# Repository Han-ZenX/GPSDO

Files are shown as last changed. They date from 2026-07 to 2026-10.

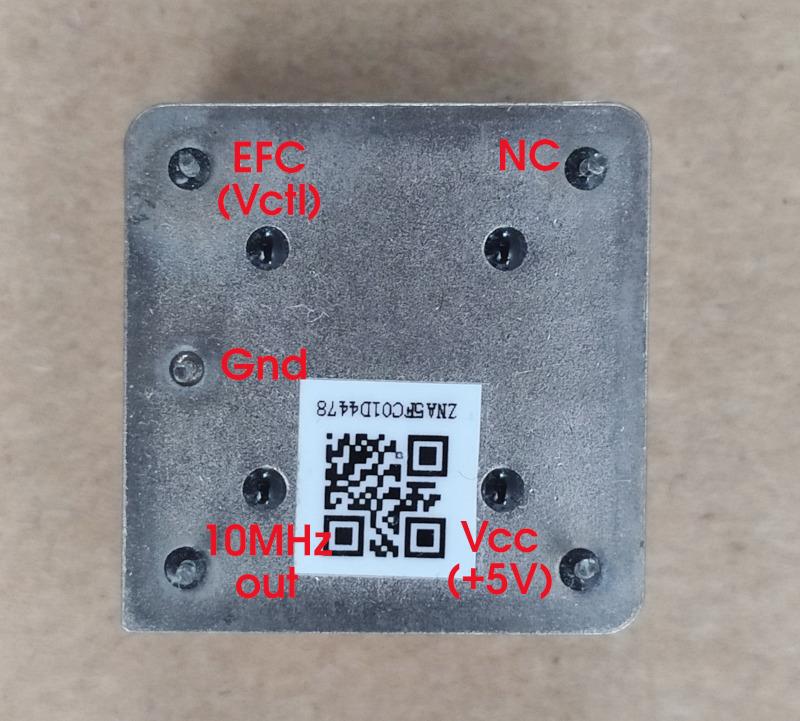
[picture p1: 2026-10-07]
docs/hardware/10Mhz OCXO ETC-CTI OSC5A2B02/CTI_OCXO_bottom.jpg

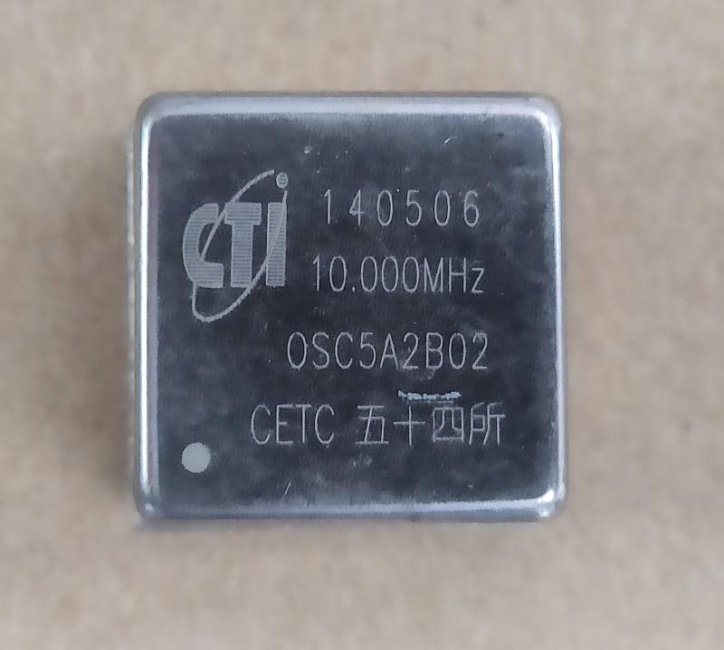
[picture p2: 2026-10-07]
docs/hardware/10Mhz OCXO ETC-CTI OSC5A2B02/CTI_OCXO_top.jpg

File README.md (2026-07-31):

# 🛰️ GPSDO - GPS disciplined Oscillator (GPS  disciplining frequency standard)

<div align="center">

**A highly integrated, portable and high-precision GPSDO**  
一款高度集成、便携式、高精度的 GPS discipling frequency standard






</div>

---

## 📖 概述 (Overview)

GPSDO (GPS Disciplined Oscillator) 是一种利用 GPS 卫星信号来校准高精度晶振频率的设备。本项目采用模块化设计，支持长期持续迭代，具备：

- ✨ **高稳定性**：PPB 级频率精度
- 🔧 **便携设计**：低功耗、一体化结构
- 🚀 **易于扩展**：分层架构，支持功能升级
- 💻 **开放源码**：完整固件 + 硬件设计开源

---

## 🎯 主要特性

| 特性 | 说明 |
|---|---|
| **精度** | PPB（十亿分之一）级别的频率稳定度 |
| **温度补偿** | 内置高精度温度传感器，实时补偿 |
| **数据记录**：支持 SD 卡存储历史数据 |
| **通信接口**：UART/SPI/I2C 多种通信方式 |
| **显示模块**：可扩展 OLED/LCD 显示屏 |
| **电源管理**：宽电压输入，锂电池供电 |
| **外壳设计**：可 3D 打印或 CNC 加工 |

---

## 🏗️ 系统架构

项目采用 **Monorepo + 四层分层架构**，各层级职责清晰：

```
GPSDO/
├── firmware/          # 嵌入式固件 (STM32G431KBU6)
│   ├── src/
│   │   ├── app/       # 应用层：业务逻辑、算法、UI
│   │   ├── hal/       # 硬件抽象层：GPIO、时钟、中断
│   │   ├── drivers/   # 驱动层：SPI、I2C、UART 等外设
│   │   └── services/  # 服务层：通信协议、数据存储
│   └── boards/        # 板级配置 (不同硬件版本)
│
├── hardware/          # KiCad 硬件设计
│   ├── schematic/v1.0/# 原理图
│   ├── pcb/v1.0/      # PCB 布局
│   ├── bom/           # BOM 物料清单
│   └── pinout/        # 引脚分配表
│
├── docs/              # 项目文档
│   ├── architecture/  # 系统架构说明
│   ├── user-guide/    # 用户使用手册
│   └── api/           # API 接口文档
│
├── software/          # 配套软件（开发中）
│   ├── desktop/       # PC 桌面应用
│   └── mobile/        # 移动端 App
│
├── tests/             # 测试套件
├── tools/             # 构建脚本与工具
└── ci/                # CI/CD 流水线配置
```

### 分层架构优势

| 层级 | 职责 | 独立性 |
|---|---|---|
| **Application** | 业务逻辑、状态机 | 更换 MCU 零修改 |
| **HAL** | GPIO、时钟、中断 | 换 MCU 时整体替换 |
| **Drivers** | SPI/I2C/UART 通信 | 随外设更换更新 |
| **Services** | 通信、存储、OTA | 可独立升级 |

👉 **核心原则**：业务逻辑不直接访问寄存器，确保代码可移植性。

---

## 🛠️ 硬件规格 (Hardware Specs)

### 主控芯片
- **MCU**: STM32G431KBU6 (Cortex-M4F, 170MHz)
- **Flash**: 1MB
- **RAM**: 112KB

### GPS 模块
- **芯片**: SKG123NT
- **通道数**: 72 通道
- **定位精度**: 水平 < 2.5m CEP

### ADC 采样
- **芯片**: ADS1115 / ADS1258
- **分辨率**: 16/24-bit
- **采样率**: 上行至 8SPS

### 辅助传感器
- **温度传感器**: TMP117 (-40~+125°C, ±0.1°C)
- **RTC**: PCF8563 (带电池备份)

### 接口
- UART: 调试串口 / 通信接口
- SPI: ADC / 显示屏
- I2C: 传感器 / EEPROM
- GPIO: LED / 按键 / 扩展

---

## 📦 构建指南 (Build Instructions)

### 环境要求

- CMake ≥ 3.16
- ARM GCC Toolchain (`arm-none-eabi-gcc`)
- Python 3.8+ (用于自动化脚本)

### 快速开始

#### Windows (PowerShell)
```powershell
# Debug 构建 (默认板级)
cd firmware
cmake -B build -DBOARD=default
cmake --build build

# Release 构建
cmake -B build -DBOARD=default -DCMAKE_BUILD_TYPE=Release
cmake --build build
```

#### Linux/macOS
```bash
# 使用自动化脚本 (推荐)
python tools/scripts/build.py --board=default

# 或使用 CMake 命令
cmake -B build -DBOARD=default && cmake --build build
```

### 多板级支持

添加新的硬件版本：
```bash
# 复制默认板级配置
cp -r firmware/boards/default firmware/boards/v2.0

# 编辑引脚映射
nano firmware/boards/v2.0/board_config.h

# 编译新版本
cmake -B build -DBOARD=v2.0
```

---

## 🧪 测试运行

### 单元测试 (Host-based)
```bash
# 在 PC 上运行纯软件测试
python tools/scripts/build.py --test unit
```

### 集成测试
```bash
# 模块间交互测试
python tools/scripts/build.py --test integration
```

### HWT (Hardware-in-the-Loop)
```bash
# 硬件在环测试
python tools/scripts/build.py --test hwt
```

---

## 📂 目录结构详解

### `firmware/src/`
| 目录 | 说明 |
|---|---|
| `app/` | 应用层：GPS 数据处理、频偏计算、状态机 |
| `hal/` | HAL 层：STM32 寄存器操作封装 |
| `drivers/` | 驱动层：ADS1258、u-blox、TMP117 等 |
| `services/` | 服务层：NMEA 解析、Flash 日志、UART 协议 |

### `hardware/schematic/v1.0/`
KiCad 原理图工程文件：
- `GPSDO.kicad_sch` - 原理图
- `GPSDO.kicad_pcb` - PCB 布局
- `fp-lib-table` - 封装库

---

## 🔌 通信协议 (Communication Protocol)

### UART 协议格式
```
波特率：115200
数据位：8
停止位：1
校验位：无
流控：无
```

### 指令集示例
```text
AT+GPS?       → 查询 GPS 状态
AT+TEMP?      → 读取温度值
AT+ALIGN      → 手动校准
AT+LOG START  → 开始记录数据
AT+LOG STOP   → 停止记录
```

详细协议文档：`docs/api/communication.md`

---

## 🚀 开发路线图

| 阶段 | 计划 | 状态 |
|---|---|---|
| **v1.0** | 基础版 - 核心功能实现 | ✅ 完成 |
| **v1.1** | 优化算法 - 提升精度 | 🔄 进行中 |
| **v1.2** | 增加 LCD 显示 | 📋 规划中 |
| **v2.0** | 蓝牙/Wi-Fi 远程监控 | 📋 未来计划 |
| **v3.0** | 云端数据同步 | 📋 概念验证 |

---

## 📄 许可证

本项目采用 **[MIT License](LICENSE)** 开源协议

允许：
- ✅ 自由商用
- ✅ 修改代码
- ✅ 分发源码
- ✅ 私有修改

要求：
- ⚠️ 保留版权声明
- ⚠️ 注明原始作者

---

## 👥 贡献指南

欢迎提交 Issue 和 Pull Request！

### 开发流程
1. Fork 本仓库
2. 创建特性分支 (`git checkout -b feature/amazing-feature`)
3. 提交更改 (`git commit -m 'Add some amazing feature'`)
4. 推送到分支 (`git push origin feature/amazing-feature`)
5. 开启 Pull Request

### 编码规范
- C 代码遵循 [Google C Style Guide](https://google.github.io/styleguide/cguide.html)
- 函数注释使用 Doxygen 格式
- 提交信息符合 [Conventional Commits](https://www.conventionalcommits.org/)

---

## 📞 联系方式

- **作者**: Han-ZenX
- **项目主页**: https://github.com/Han-ZenX/GPSDO
- **问题反馈**: [GitHub Issues](https://github.com/Han-ZenX/GPSDO/issues)

---

## 🙏 致谢

本项目参考了以下优秀开源项目：

- **ESP-IDF** - 组件化架构设计
- **Zephyr RTOS** - 板级抽象层模式
- **FreeRTOS** - 任务调度机制
- **RIOT-OS** - 驱动分层设计

---

## 📊 统计信息

```
语言分布:
├── C         54.8%
├── CMake     21.6%
└── Python    23.6%
```

---

<div align="center">

**Made with ❤️ for Precision Timing**

⭐ Star 本仓库以支持项目开发！

</div>

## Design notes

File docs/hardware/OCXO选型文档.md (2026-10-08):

# 10 MHz OCXO 选型文档

> **数据来源声明。** 本文中的**板级约束**（封装尺寸、焊盘坐标、网络连接、供电拓扑、EFC 滤波参数）全部由本仓库 `hardware/schematic/v1.0/GPSDO.kicad_sch` 与 `GPSDO.kicad_pcb` 解析得出，可直接采信。本文中的**具体型号参数、价格与库存**为依据厂商公开资料整理的典型值与量级，撰写时无法联网核对实时行情，**下单前必须逐项核对最新 datasheet 与商城页面**。凡标注"须复核"的条目请视为待验证项，而非结论。

---

## 1. 结论摘要

| 项目 | 结论 |
| --- | --- |
| 接口形态 | 1 英寸见方（25.4 mm）金属壳直插 OCXO，引脚网格 19.0 mm，5 脚（3+2 排布），**安装在 PCB 底面** |
| 输出要求 | **必须是 HCMOS / LVCMOS 方波**，本板没有任何正弦整形电路 |
| 控制方式 | MCU PWM 经二阶 RC 滤波产生 0-3.3 V 控制电压，同时回读进 ADC |
| 供电能力 | TPS7A8901 双路 LDO，输入取自 SYS（单节锂电系统轨 3.0-4.4 V）。**该轨在结构上做不出 5 V**，单通道约 500 mA（须复核） |
| 第一结论 | 不改板时只能选"3.3 V 供电、预热小于 1.5 W、稳态小于 1.0 W"的低功耗型号，这个组合在 1 英寸直插壳里选择面很窄、单价偏高 |
| 推荐路线 | 增加一路 5 V 升压，把 OCXO 轨改为 5 V。**这一步打开整个 5 V OCXO 市场**，新品与拆机件都极易购买 |
| 牵引范围 | 0-3.3 V 控制范围内总牵引量取 **3 到 10 ppm**（即 ±1.5 到 ±5 ppm），依据见第 3.3、3.4 节 |
| 必须避开 | 正弦输出、12 V 供电、封装大于 25.4 mm、脚位网格不是 19 mm、无 EFC 引脚、无 datasheet 的三无拆机件 |

### 1.1 三条可选路线

| 路线 | 做法 | 板级改动 | 器件档次 | 整机功耗 | 适用场景 |
| --- | --- | --- | --- | --- | --- |
| **路线 1** 不改板 | 选 3.3 V 低功耗 OCXO | 无 | ±5 到 ±20 ppb 小型低功耗件 | 预热小于 1.5 W，稳态小于 1 W | 坚持电池便携，可接受高单价与窄选择面 |
| **路线 2** 推荐 | 加 5 V 升压后供 OCXO | 加 1 颗升压 IC 加电感电容，约 6 个元件 | ±5 ppb 主流 5 V 件，选择面最大 | 预热 3 到 5 W，稳态 1.5 到 2.5 W | 大多数情况的最优解，续航按 2 到 4 h 设计 |
| **路线 3** 替代 | 改用超稳 MEMS 数字调频器件 | EFC 通道改走 I2C，PWM 链路作废 | ±100 ppb 级，优于普通 TCXO 但不及 OCXO | 小于 0.15 W | 把便携续航排在短稳之前的产品定位 |

---

## 2. 板级约束（实测自 v1.0 工程文件）

@fig:ocxo_pinout 图 1　U2 焊盘实测坐标与引脚功能（数据取自 GPSDO.kicad_pcb）

### 2.1 封装与脚位

PCB 中 OCXO 位号 `U2`，封装 `Counter:OCXO_19x19mm`，位于 **B.Cu 即板底面**。丝印外框从 -3.25 mm 到 +22.25 mm，约 **25.5 mm 见方**，对应标准 1 英寸金属壳 OCXO。

| 焊盘 | 相对坐标 mm | 原理图引脚名 | 实际连接网络 | 说明 |
| --- | --- | --- | --- | --- |
| 1 | (0, 0) | RF | Net-(U2-RF) | 10 MHz 输出，串 R6 180 欧 |
| 2 | (0, -9.5) | GND | BAT- | 地。本工程的地网络最终名为 BAT- |
| 3 | (0, -19) | VCTRL | VCTL | 电压控频 EFC 输入 |
| 4 | (19, -19) | VREF | **未连接** | 预留给带内部基准输出的型号 |
| 5 | (19, 0) | VCC | +3.3/+5V | OCXO 供电轨，见 2.2 |

机械参数：焊盘 1.5 mm 圆角矩形，钻孔直径 **1.0 mm**；引脚网格 **19.0 x 19.0 mm**（业界标准 0.75 英寸即 19.05 mm，0.05 mm 差异可由 1.0 mm 孔吸收）。

> **选型时必须核对的三件事。** 一，**脚位排布**：本板是"一条边 3 脚间距 9.5 mm，对边 2 脚间距 19 mm"。这是常见但并非唯一的 1 英寸 OCXO 脚位，另一大类"四角 4 脚加中心 1 脚"**与本板不兼容**。二，**引脚功能顺序**：几何位置对上不等于功能对上，各厂对 VCC / VC / OUT / GND 的分配顺序不同。三，**引脚直径**：部分 OCXO 用直径 1.0 mm 粗针，塞进 1.0 mm 孔会很紧，0.45 到 0.6 mm 细针则没问题。

### 2.2 供电通道

供电链路为：USB VBUS 或电池，经 BQ25890 得到 SYS，再经 TPS7A8901 双路超低噪 LDO 得到 `+3.3V` 与 `+3.3/+5V`。OCXO 挂在第二路输出上。该路的反馈电阻 R10 / R11 目前**数值未定义**（原理图中 R10 的值写成 "100nF"、R11 的值写成 "GND"，是占位符）。焊接跳线 JP1 可把该轨直接短接到主 3.3 V。

> **关键结论：该轨不可能输出 5 V。** TPS7A8901 是线性稳压器，输出必然低于输入，而它的输入是 SYS，BQ25890 的 SYS 轨在单节锂电系统中约为 3.0 到 4.4 V。因此网络名 `+3.3/+5V` 里的 "+5V" 在当前拓扑下无法实现。**要用 5 V OCXO 就必须新增升压级**，见第 7 节。

| 项目 | 数值与影响 |
| --- | --- |
| 可用输出电压 | 3.3 V |
| 单通道电流上限 | 约 500 mA（TPS7A89 系列标称，**须复核**），3.3 V 下对应约 **1.65 W 功率上限** |
| 低电池风险 | 锂电放到 3.4 V 时 SYS 约 3.4 V，扣掉 LDO 压差后 3.3 V 轨掉出调整区，OCXO 供电随电池漂移，再经电压频率灵敏度（典型 ±1 ppb 每 1% VCC）污染频率 |
| 由此得出的门槛 | **预热峰值不超过 1.5 W（约 455 mA），稳态不超过 1.0 W**，才能不改板直接使用 |

对照：典型 1 英寸金属壳 OCXO 的预热功耗是 3 到 6 W，稳态 1.2 到 2.5 W。**绝大多数常见型号会超出本板 LDO 的电流能力**，这正是推荐路线 2 的根本原因。

### 2.3 EFC 电压控频通道

链路为：MCU PWM 引脚，经 R4 20k 与 C1 10uF、R5 20k 与 C2 10uF 两级 RC，得到 VCTL 送 OCXO 引脚 3，C3 0.1uF 就近去耦，TP1 为测试点；**VCTL 同时回接到 MCU 的一个 ADC 引脚做闭环监测**。

| 项目 | 数值 |
| --- | --- |
| 控制电压范围 | 0 到 3.3 V（PWM 高电平即 MCU 的 VDD，未做电平放大） |
| 滤波器 | 二阶 RC，单极点 fc = 1/(2 pi x 20k x 10uF) 约 **0.80 Hz** |
| PWM 载波（建议） | 16 位分辨率配 170 MHz 时钟，载波 2.594 kHz，两级合计衰减约 **140 dB**，纹波可忽略 |
| 建立时间 | 单级时间常数 0.2 s，二阶串联稳定到 0.1% 约需 1.5 到 2 s，远快于 GPSDO 环路带宽（毫赫兹量级） |
| 源阻抗 | **40 k 欧**（两级 20k 串联），见下方风险 A |

> **风险 A：源阻抗过高。** EFC 节点的戴维南源阻抗是 40 k 欧。若所选 OCXO 的 EFC 输入阻抗为 Rin，实际到达变容管的电压被分压成 V 乘以 Rin/(Rin+40k)。Rin = 100 k 欧时只剩 71%，且 Rin 随温度变化会转化成**控制增益漂移**；若 EFC 端有输入偏置电流，还会带来固定电压误差。对策二选一：一是选型时限定 **EFC 输入阻抗不低于 1 M 欧**（变容管直连型多属此类，但必须查证）；二是在 RC 之后加一级轨到轨运放电压跟随器（OPA333 或 OPA192 级别，低失调低噪声）。**推荐后者。**

> **风险 B：PWM 幅度即基准。** 控制电压等于 PWM 占空比乘以 MCU 的 VDD，3.3 V 轨的噪声与漂移会按比例直接调制 EFC。按 3.3 节的最佳区间（0-3.3 V 内总牵引 5 ppm，每 LSB 约 7.6e-11）计算，占空比在 50% 附近时，**3.3 V 轨每变化 0.1 mV，EFC 就变化约 1 个 LSB**。缓慢漂移会被环路纠正，但本板是电池供电，充电启停、蜂鸣器、GNSS 模组与 CH340E 的负载变化会让 3.3 V 轨出现 mV 级的快速台阶，这些台阶会直接变成频率台阶。

> **风险 B 的对策：在 PWM 与 RC 之间插入一颗由精密基准单独供电的单门 CMOS 缓冲器。** 缓冲器输出的高电平就等于基准电压，与 3.3 V 轨无关；它的负载只是 20 k 欧的 RC，约 0.2 mA，一般精密基准都能直接驱动，输出电阻带来的误差在微伏级。基准有两种取法：一是取 OCXO 自身的 VREF 输出（本板焊盘 4 已预留，见 2.1 节），构成比率式调谐，基准漂移时 EFC 与 OCXO 内部基准一起漂、部分抵消，但需确认该型号 VREF 引脚的输出电流能力；二是用独立的精密基准。器件选择取决于基准电压：基准为 3.3 V 或更低时用 74LVC1G125 一类即可；**基准高于 3.3 V 时（如 5 V 型号的 VREF），要改用 TTL 输入门限的 74AHCT1G125 或电平转换器 74LVC1T45**，否则 MCU 3.3 V 的高电平达不到门限。做了这一步之后，"基准电压加 DAC"相对 PWM 已经没有基准方面的优势。

> **更正：用 ADC 回读 VCTL 做比例校正，在本板上不成立。** STM32G431KBU6 的 UFQFPN32 封装没有单独的 VREF+ 引脚，ADC 以 VDDA 为基准，而 VDDA 与数字电源同接 +3.3V。于是 ADC 读数等于 VCTL 除以 3.3 V 轨，恰好就是占空比本身，3.3 V 轨怎么变都看不出来。若不加上述缓冲器，只能同时测量片内参考电压 VREFINT、换算出 VDDA 的绝对值再补偿，精度受 VREFINT 自身温漂限制。VCTL 回读仍然保留，但用途是监测 EFC 的开路、短路与饱和，而不是校正基准。

### 2.4 输出通道

链路为：OCXO 引脚 1，串 R6 180 欧到网络 `10MHz`，该网络上挂 TP2 测试点、R24 49.9 欧对地、R27 0 欧接 LMK1C1102 的 CLKIN；缓冲器两路输出分别经 R25 送 MCU 定时器、经 R22 与 R23 送 SMA 座 J2。原理图上的文字标注是 "OCXO HCMOS" 与 "50 OHM TRACE"。

> **硬性结论：必须选方波输出型号。** 本板没有任何正弦整形电路，没有比较器、没有自偏置反相器、没有变压器。市面上大量便宜的拆机 OCXO 是**正弦输出（典型 +7 dBm / 50 欧）**，焊上去无法驱动 LMK1C1102 的 LVCMOS 输入。

> **风险 C（顺带发现的既有设计问题，本文不做修改）。** R6 = 180 欧与 R24 = 49.9 欧构成分压，会把 3.3 Vpp 方波衰减到约 **0.72 Vpp**，可能低于 LMK1C1102 的输入高电平门限。若要保留 50 欧端接，串阻通常取 22 到 33 欧更合适。另外 PCB 中 **U8 的 VDD 焊盘（pad 6）当前是未连接状态**。建议贴片前一并复核。

@fig:ocxo_chain 图 2　OCXO 的三条链路与各自的瓶颈

---

## 3. 指标怎么看

### 3.1 单位换算速查（f0 = 10 MHz）

| 相对频差 | 绝对频差 | 1 秒累积相位 | 1 天累积时差 | 在本项目中的含义 |
| --- | --- | --- | --- | --- |
| 1 ppm = 1e-6 | 10 Hz | 3600 度 | 86.4 ms | 普通晶振量级，也是典型 OCXO 牵引范围量级 |
| 1 ppb = 1e-9 | 10 mHz | 3.6 度 | 86.4 us | OCXO 温度稳定度的常用单位 |
| 1e-11 | 0.1 mHz | 0.036 度 | 0.86 us | 好 OCXO 的 1 秒阿伦方差量级，也是 EFC 分辨率的设计目标 |
| 1e-12 | 10 uHz | 0.0036 度 | 86 ns | 驯服锁定后的长期目标，高端双恒温 OCXO 的短稳 |

### 3.2 参数权重表

| 参数 | 对 GPSDO 的作用 | 本项目目标 | 权重 |
| --- | --- | --- | --- |
| **短稳 ADEV**，取样 1 到 100 s | 决定环路带宽以内以及交越点附近的实际性能，GPSDO 输出短稳基本等于 OCXO 自身短稳 | 1 s 不劣于 1e-11，10 s 不劣于 1e-11，100 s 不劣于 2e-11 | 最高 |
| **温度稳定度**，全温区峰峰值 | 环路带宽外的温度扰动无法被 GPS 修正，这是 OCXO 相对 TCXO 的核心价值 | 不超过 ±10 ppb，优选 ±5 ppb | 最高 |
| **牵引范围与 EFC 特性** | 太小则老化后拉不回，太大则分辨率与噪声抑制变差，定量见 3.3 与 3.4 | 0-3.3 V 内总量 3 到 10 ppm，单调且近似线性 | 最高 |
| **预热时间与功耗** | 直接决定电池续航与供电方案，便携设备的第一约束 | 见 2.2，不改板需预热不超过 1.5 W | 最高 |
| **老化率** | 决定失锁保持能力，以及 EFC 调谐余量能撑几年 | 不超过 1 ppb 每天，不超过 0.5 ppm 每年 | 高 |
| **相位噪声** | 影响作为射频本振或测试基准时的可用性，做时频基准时优先级低于 ADEV | 10 Hz 处不劣于 -120 dBc/Hz，1 kHz 处不劣于 -145 dBc/Hz | 中 |
| **Retrace 重启复现性** | 断电冷却再上电回到原频率的能力，便携设备频繁开关机时才重要 | 不超过 ±5 ppb | 中 |
| **电压与负载牵引** | 供电波动经此转成频率误差，与 2.2 的低电池风险叠加 | 不超过 ±1 ppb 每 1% VCC | 低 |
| **磁场与振动敏感度** | 固定台式使用可忽略，移动使用会显著劣化短稳 | 了解即可，通常不作筛选条件 | 低 |

### 3.3 EFC 分辨率计算，决定牵引范围的上限

```
每 LSB 频率步进  df = 总牵引量[ppm] x 10 Hz/ppm / 2^N      (N 为 PWM 位数)
相对分辨率      = df / 10 MHz
```

取 N = 16（STM32G431 配 170 MHz，PWM 载波 2.594 kHz，二阶 RC 后纹波已被抑制约 140 dB）：

| 0-3.3 V 内的总牵引量 | 全量程频率跨度 | 每 LSB 步进 | 相对分辨率 | 评价 |
| --- | --- | --- | --- | --- |
| 1 ppm，即 ±0.5 ppm | 10 Hz | 0.153 mHz | 1.5e-11 | 分辨率好，但余量不足，见 3.4 |
| 3 ppm，即 ±1.5 ppm | 30 Hz | 0.458 mHz | 4.6e-11 | **下限，可用** |
| 5 ppm，即 ±2.5 ppm | 50 Hz | 0.763 mHz | 7.6e-11 | **最佳区间** |
| 10 ppm，即 ±5 ppm | 100 Hz | 1.53 mHz | 1.5e-10 | **上限，尚可** |
| 20 ppm，即 ±10 ppm | 200 Hz | 3.05 mHz | 3.1e-10 | 已劣于 OCXO 自身短稳，不推荐 |

注一：目标是让 EFC 分辨率优于 OCXO 在环路时间常数处的 ADEV（约 1e-11 到 1e-10），使量化台阶不成为性能瓶颈。上表 3 到 10 ppm 区间满足这一条件。

注二：若实际拿到的器件牵引范围偏大，可用固件做一阶 sigma-delta 抖动（在 1 秒更新周期内对占空比做时间维度抖动），再换取 2 到 4 位等效分辨率，RC 的 0.8 Hz 截止频率足以滤掉抖动噪声。

注三：C1 与 C2 是 10uF X7R，存在直流偏压容值衰减，实际可能只剩 50% 到 70%，fc 会升到约 1.1 到 1.6 Hz，对上述结论无实质影响。

### 3.4 调谐余量的寿命计算，决定牵引范围的下限

EFC 必须同时吸收下列各项：

| 误差来源 | 典型量 | 说明 |
| --- | --- | --- |
| 出厂初始频差 | ±0.5 ppm | 常见标称 ±0.5 ppm 或 ±1 ppm 在 25 摄氏度 |
| 第 1 年老化 | ±0.3 到 ±0.5 ppm | 按 1 ppb 每天，且首年速率最快 |
| 后续每年老化 | ±0.1 到 ±0.2 ppm 每年 | 老化率随时间衰减 |
| 温度加电压加 retrace | ±0.05 ppm | 相对老化项可忽略 |
| **5 年累计需求** | **约 ±1.3 到 ±1.5 ppm** | 因此总牵引量需要不低于 3 ppm |

> **3.3 与 3.4 的合并结论：在 0-3.3 V 控制范围内，总牵引量取 3 到 10 ppm 最佳。** 注意 datasheet 通常标注的是 0-5 V 的牵引范围。若器件标称"±5 ppm 在 0-5 V"，本板只用到 0-3.3 V，实际可用牵引约为标称的 66%，即总量约 6.6 ppm，仍落在最佳区间内；但要注意**标称频率点会落在 EFC 中点 1.65 V 附近而不是 2.5 V**，选型时需确认该点仍在牵引曲线的线性段内。

---

## 4. 筛选清单

拿这张表对着商城页面逐条打勾。

| 序号 | 条件 | 要求 | 不满足的后果或处理 |
| --- | --- | --- | --- |
| 1 | 标称频率 | 10.000000 MHz | 硬性 |
| 2 | 输出波形 | **HCMOS 或 LVCMOS 方波** | 正弦输出需自建整形电路，本板没有，直接排除 |
| 3 | 输出电平 | 与 3.3 V 逻辑兼容，或经 2.4 节分压后仍满足缓冲器门限 | 5 V CMOS 输出经 180/49.9 分压后约 1.1 Vpp，需复核门限 |
| 4 | 供电电压 | 路线 1 为 3.3 V ±5%，路线 2 为 5.0 V ±5% | 12 V 型号一律排除 |
| 5 | 预热峰值电流 | 路线 1 不超过 450 mA，路线 2 建议不超过 1 A | 超出会导致限流保护、上电反复重启 |
| 6 | 稳态功耗 | 路线 1 不超过 1.0 W，路线 2 不超过 2.5 W | 直接决定电池续航 |
| 7 | 有 EFC 引脚 | 必须有，控制范围覆盖 0-3.3 V 或 0-5 V | 无 EFC 的固定频率 OCXO 无法驯服，排除 |
| 8 | 牵引范围 | 0-3.3 V 内总量 3 到 10 ppm | 过小则数年后失去调节能力，过大则分辨率变差 |
| 9 | EFC 输入阻抗 | 不低于 1 M 欧，低于 200 k 欧必须加运放缓冲 | 见风险 A |
| 10 | EFC 极性 | 正斜率或负斜率，已知即可 | 极性搞反会让环路变成正反馈而发散 |
| 11 | 封装与脚位 | 不大于 25.4 mm 见方，网格 19.0 或 19.05 mm，脚位逐点比对 2.1 表 | 不匹配需做转接小板或飞线 |
| 12 | 温度稳定度 | 不超过 ±10 ppb，优选 ±5 ppb | 决定环路带宽外的性能 |
| 13 | 老化率 | 不超过 1 ppb 每天 | 决定保持能力与调谐寿命 |
| 14 | 有正式 datasheet | 必须能拿到 PDF | 拿不到就只能按第 8 节实测反推脚位与极性 |

---

## 5. 候选器件

> 下表价格为**量级参考**，参数为**厂商公开资料的典型值**，撰写环境无法联网核实。请把它当作搜索方向与判断框架，不要当作最终报价与规格书。

### 5.1 B 档：正规渠道新品（推荐主力）

渠道为立创商城、贸泽、得捷、厂商代理。优点是有 datasheet、批次一致、可复购；缺点是单价高。

| 系列与品牌 | 封装 | 供电 | 典型指标（须复核） | 价格量级 | 与本板匹配 |
| --- | --- | --- | --- | --- | --- |
| **Connor-Winfield OH300 系列** | 1 英寸金属壳直插 | 3.3 V 或 5 V | HCMOS 输出，温度稳定度 ±5 到 ±20 ppb，老化约 1 ppb 每天 | 300 到 800 元 | 封装契合度最高的一类，**务必核对脚位排布与预热功耗** |
| **Taitien 泰艺 OCXO 系列** | 直插与贴片均有 | 3.3 V 或 5 V | ±5 到 ±20 ppb，型号覆盖广，含低功耗版本 | 200 到 600 元 | 国内易买，有低功耗型号，是路线 1 的主要希望 |
| **IQD OCXO 系列** | 直插或贴片 | 3.3 V / 5 V / 12 V | 分档细，从 ±20 ppb 到 ±1 ppb | 300 到 1500 元 | 贸泽常备，注意剔除 12 V 与正弦输出型号 |
| **Abracon AOCJY 系列** | 多为贴片，约 10 x 8 mm 起 | 3.3 V | ±5 到 ±20 ppb，低功耗设计 | 200 到 600 元 | **贴片封装与本板直插焊盘不匹配**，需转接板；但功耗最适合电池供电 |
| **国产：成都天奥、苏州东晶、扬兴 YXC 等** | 以 1 英寸直插为主 | 5 V 居多，3.3 V 较少 | ±5 到 ±50 ppb 不等，分档明显 | 80 到 400 元 | 性价比最高的一类，**务必索取 datasheet**，同一外形可能有多种脚位定义 |

### 5.2 A 档：拆机与二手（低成本验证）

渠道为淘宝、闲鱼、AliExpress、eBay。优点是极便宜且常是高档货，缺点是无质保、批次不一、脚位与 EFC 需自行实测。

| 型号或类别 | 供电 | 输出 | 特点 | 价格量级 | 与本板匹配 |
| --- | --- | --- | --- | --- | --- |
| **CTI OSC5A2B02** | 5 V | 方波 | 圈内最经典的入门件，±5 ppb 级，社区实测数据丰富 | 40 到 120 元 | 封装约 36 x 27 mm，**脚位与本板不匹配**，需转接板加 5 V 升压 |
| **各类 1 英寸方壳 5 V 拆机件** | 5 V | 方波或正弦 | 数量最多最便宜的一类，质量参差需实测筛选 | 30 到 150 元 | 几何上最可能匹配本板，**必须先实测确认方波与脚位** |
| **Trimble / Symmetricom / Datum 拆机模块** | 多为 12 V | 常为正弦 | 指标很好，部分是双恒温 | 80 到 300 元 | 供电与输出形式都不适配，只适合当外部参考源 |
| **Morion MV89A 等** | 12 V | 正弦 | 短稳可达 1e-12 量级，发烧级选择 | 200 到 600 元 | 50.8 mm 封装加 12 V 加正弦，**与本板完全不兼容** |

> **拆机件三条铁律。** 一，先用限流实验室电源单独点亮实测，绝不直接焊上板。二，无 datasheet 时必须按第 8 节流程反推脚位，把 EFC 错接到电源会击穿变容二极管。三，同一链接的不同批次可能是完全不同的器件，量产不可依赖。

### 5.3 C 档：高性能（超出本板需求）

双恒温 DOCXO、恒温 SC 切晶体、Wenzel 与 Bliley 与 Morion 的高端型号，短稳可达 1e-12 甚至更好。这类器件普遍是 12 V 供电、功耗 5 到 15 W、体积 50 mm 以上、多为正弦输出，**与本项目的便携电池定位冲突**。仅建议作为将来台式外接电源版本的升级选项，不在本板考虑范围。

### 5.4 D 路线：超稳 MEMS 数字调频器件（替代方案）

以 SiTime SiT5711 与 SiT5721 一类"超稳 MEMS 振荡器"为代表：3.3 V 供电，功耗低于 0.15 W，通过 **I2C 数字接口**直接写入频率修正值，分辨率可达 1e-12 量级，不需要模拟 EFC 通道。

| 维度 | 相对 OCXO 的优势 | 相对 OCXO 的劣势 |
| --- | --- | --- |
| 功耗 | 低 1 到 2 个数量级，彻底解决续航与 LDO 电流问题 | 无 |
| 预热 | 秒级可用，无长预热 | 无 |
| 调频接口 | 数字接口，本文 2.3 节的三个风险全部消失 | 需改硬件与固件走 I2C，PWM 加 RC 链路作废 |
| 温度稳定度 | 优于普通 TCXO | 通常仍不及好 OCXO 的 ±5 ppb |
| 短稳 ADEV | 无 | **明显不如 OCXO，这是最关键的差距** |
| 封装 | 小型贴片 | 与本板直插焊盘不兼容，需改版 |

具体型号的稳定度与 ADEV 须查 SiTime 官方 datasheet 核实。此路线适合把"便携、续航、快速可用"排在"短期稳定度"之前的产品定位；若项目核心卖点是 ppb 级频率基准品质，仍应选 OCXO。

---

## 6. 推荐结论

### 6.1 首选方案

> **路线 2 加 B 档国产或台系 5 V 方波 OCXO。**

1. 板上增加一路 5 V 升压，详见第 7 节，把 OCXO 供电与 3.3 V 数字域分开。
2. 选购 1 英寸直插、**5 V 供电、HCMOS 方波输出**、温度稳定度 ±5 到 ±10 ppb、老化不超过 1 ppb 每天、0-5 V 牵引 ±3 到 ±5 ppm 的型号。
3. EFC 仍用本板的 0-3.3 V 驱动，对应约 66% 牵引量，仍满足 3.4 节的余量要求；也可在升压后加运放把 0-3.3 V 放大到 0-5 V 以用满量程、改善线性度。
4. 在 RC 网络后加一级轨到轨运放跟随器，消除 40 k 欧源阻抗问题，即风险 A。

理由：5 V 是 OCXO 市场的主流供电，可选型号数量是 3.3 V 的数倍，价格低一个档次，且拆机件大量可用于前期验证。

### 6.2 备选方案（不想动板子）

路线 1 加低功耗 3.3 V OCXO。严格按第 4 节清单筛选，重点卡死"预热不超过 1.5 W、稳态不超过 1.0 W、3.3 V 供电、1 英寸直插、方波输出"这五条。同时满足的型号数量有限、单价偏高、选型工作量大，但完全不用改板。若筛选中发现只有贴片封装的低功耗型号可选，做一块 25.4 mm 转接小板也是可行方案。

### 6.3 明确不推荐

- **任何 12 V 型号**：本板无 12 V 轨，功耗也与电池方案冲突。
- **任何正弦输出型号**：本板无整形电路，Morion 与多数 Trimble、Symmetricom 拆机件属此类。
- **无 EFC 引脚的固定频率 OCXO**：无法驯服。
- **50 mm 级大封装双恒温件**：与便携定位冲突。
- **未验证脚位就直接焊上板的拆机件**：EFC 端错接电源会击穿变容管。

---

## 7. 若走路线 2：供电改动要点

| 项目 | 说明 |
| --- | --- |
| 拓扑 | SYS（3.0 到 4.4 V）升压到 5.0 至 5.5 V，再经一级超低噪 LDO 稳到 5.0 V 供 OCXO。升压能力建议不低于 1.5 A 以覆盖预热浪涌 |
| 为什么要串 LDO | 升压是开关电源，其纹波与开关噪声会经供电灵敏度调制频率并抬高相噪基底，串一级低压差超低噪 LDO 并留 300 到 500 mV 压差可显著改善 |
| 网络与跳线 | 现有网络名 `+3.3/+5V` 已预留此意图。改动后应把 R10 与 R11 的占位值改成实际反馈电阻，或把该轨直接切到新的 5 V 源，并保留 JP1 作为回退到 3.3 V 的选项 |
| 电池续航估算 | OCXO 稳态 2 W 加其余系统约 0.4 W 合计 2.4 W。按 3000 mAh 单节锂电约 11 Wh、转换效率 85% 计算，**约 3.9 小时**。预热阶段 3 到 5 分钟按 4 到 5 W 计，额外约 0.3 Wh，可忽略 |
| 热设计 | OCXO 装在板底面，稳态 2 W 会形成局部热源。一要避免其热流干扰 TMP117 的温度读数；二要避免机壳内气流直吹 OCXO，气流波动会转化成频率波动 |
| EFC 电平匹配（可选） | 用一级同相放大，增益 1.515，把 0-3.3 V 映射到 0-5 V 以用满牵引范围。但这会把牵引量放大 1.5 倍，需按 3.3 节重新核算分辨率是否仍在 3 到 10 ppm 的等效区间内 |

---

## 8. 到货验收流程

### 8.1 步骤

| 步 | 操作 | 方法 | 判据与记录 |
| --- | --- | --- | --- |
| 1 | 外观与尺寸核对 | 看壳体丝印与批次，用游标卡尺量壳体尺寸与引脚网格 | 网格 19.0 到 19.05 mm，壳体不超过 25.5 mm |
| 2 | 脚位反推（无资料时） | 断电用万用表测各脚对壳体的阻值：近似 0 欧的是 GND；阻值极大且对地无低阻通路的是 EFC；剩余两脚串 100 欧限流后从 3.3 V 缓慢升压试探并监控电流 | **此步有烧毁风险，必须用限流电源，初始限流设 100 mA。** 记录每个脚的判定结论 |
| 3 | 预热电流曲线 | 按标称电压供电、限流 1.5 A，记录 0、10 s、30 s、1 min、2 min、3 min、5 min、10 min 的电流 | 峰值是否在供电方案能力内，稳态是否符合 datasheet。**峰值超标即该器件不可用** |
| 4 | 输出波形确认 | 用不低于 100 MHz 带宽的示波器配 10:1 探头测输出 | **必须是方波**，记录 Vpp、上升沿、占空比，占空比应在 45% 到 55% |
| 5 | EFC 牵引曲线实测 | EFC 从 0 V 起按 0.2 到 0.5 V 步进扫到满量程，每点稳定 60 s 后用频率计或与 GPS 1PPS 比对的闸门计数测频 | 画出 f-V 曲线，确认**单调性、极性、总牵引量、线性度**，总牵引量应落在 3.4 节要求内 |
| 6 | EFC 输入阻抗估算 | 在 EFC 支路串入已知电阻如 100 k 欧，比较串入前后的频率变化量反推分压比 | 推得 Rin。低于 200 k 欧则必须加运放缓冲 |
| 7 | 准确度与预热漂移 | EFC 置于中点，连续记录 30 分钟频率 | 记录 5、10、30 分钟时刻的频差，预热判据一般取"进入 ±1 ppb 带宽" |
| 8 | 老化观察 | 常温连续通电 7 到 30 天，每天同一时刻记录频率 | 拟合日老化率，应不超过 1 ppb 每天。**拆机件的老化通常已趋于平缓，这是二手件的真实优点** |
| 9 | ADEV 测量 | 与 GPS 1PPS 做时间间隔测量，本板 MCU 的 32 位定时器即可粗测，采样不少于 10000 点，算重叠阿伦偏差 | 对照 3.2 节目标，1 秒处不劣于 1e-11 |
| 10 | 温度敏感度（可选） | 用热风枪或温箱在 0 到 60 摄氏度间缓慢变温，同步记录 TMP117 与频率 | 得到频温曲线峰峰值，可用于固件前馈补偿 |

### 8.2 验收记录表模板

| 项目 | 实测值 | 判据 | 结论 |
| --- | --- | --- | --- |
| 型号 / 批次 / 渠道 |  | 记录用 |  |
| 壳体尺寸与引脚网格 mm |  | 不超过 25.5，网格 19.0 到 19.05 |  |
| 引脚 1 到 5 的功能 |  | 与 2.1 表一致 |  |
| 供电电压与稳态电流 |  | 与所选方案匹配 |  |
| 预热峰值电流与持续时间 |  | 不超过供电能力 |  |
| 输出波形 Vpp 与占空比 |  | 方波，45% 到 55% |  |
| EFC 极性 |  | 已确定 |  |
| 0-3.3 V 牵引量 ppm |  | 3 到 10 ppm |  |
| EFC 输入阻抗 |  | 不低于 1 M 欧，否则加缓冲 |  |
| 10 分钟频差 ppb |  | 不超过 ±10 ppb |  |
| 日老化率 ppb 每天 |  | 不超过 1 |  |
| ADEV 1 秒与 100 秒 |  | 不劣于 1e-11 与 2e-11 |  |

---

## 9. 购买渠道与询价

| 渠道 | 搜索关键词或筛选路径 | 备注 |
| --- | --- | --- |
| 立创商城 | "恒温晶振 OCXO 10MHz"，筛选频率 10 MHz、封装选插件、输出选 CMOS 或 HCMOS | 有中文规格书与现货标识，最省事的正规渠道 |
| 贸泽 Mouser 与得捷 DigiKey | 参数筛选：Frequency 选 10 MHz，Package 选 Through Hole，Supply 选 3.3 V 或 5 V，Output 选 HCMOS，功能选带 EFC 的 VCOCXO | 参数筛选器最强、datasheet 齐全，价格最高，注意关税与起订量 |
| 淘宝 | "10M 恒温晶振 方波"、"OCXO 10MHz 压控 5V"、"恒温晶振 25.4 直插" | 新品与拆机混杂，**下单前务必私信索要 datasheet 与脚位图** |
| 闲鱼与 eBay | "拆机 恒温晶振"、"OCXO 10MHz" | 最便宜，也最需要第 8 节的完整验收流程 |
| AliExpress | "OCXO 10MHz square wave"、"OCXO 10MHz VCOCXO" | 与淘宝货源大致重合 |

询价话术模板，可直接复制给卖家：

```
你好，我需要 10 MHz 恒温晶振，请确认以下几点：
1) 输出是方波 HCMOS 还是正弦？
2) 供电电压是多少？
3) 预热电流峰值和稳态电流各是多少？
4) 有没有压控 EFC 引脚？控制电压范围和牵引量是多少 ppm？
5) 能否提供 datasheet 和引脚定义图（底视图，含引脚间距尺寸）？
```

---

## 10. 附录

### 10.1 术语

| 术语 | 含义 |
| --- | --- |
| OCXO | 恒温晶体振荡器。晶体置于恒温槽中，用温控消除频温曲线的影响，是本项目的核心器件 |
| EFC 或 VC | Electronic Frequency Control，电压控频输入，是 GPSDO 环路的执行端 |
| 牵引范围 | EFC 从最低到最高时能改变的频率总量，通常以 ppm 表示 |
| ADEV | 阿伦方差或阿伦偏差，频率源短期稳定度的标准度量，与取样时间相关 |
| Holdover | 失去 GPS 信号后仅靠 OCXO 自身维持精度的能力，主要由老化率与温度稳定度决定 |
| Retrace | 断电冷却后再上电，频率回到原值的复现能力 |
| DOCXO | 双恒温 OCXO，两级温控，性能更高、功耗更大 |

### 10.2 关键数值汇总

| 项目 | 数值 |
| --- | --- |
| OCXO 焊盘引脚网格 | 19.0 x 19.0 mm，钻孔 1.0 mm，底面安装 |
| EFC 滤波器 | 二阶 RC，fc = 0.80 Hz，源阻抗 40 k 欧 |
| EFC 源阻抗处理 | 加轨到轨运放跟随器，或选输入阻抗不低于 1 M 欧的器件 |
| 推荐 PWM 分辨率与载波 | 16 位，2.594 kHz，基于 170 MHz 时钟 |
| 推荐牵引范围 | 0-3.3 V 内总量 3 到 10 ppm |
| 不改板时的功耗门槛 | 预热不超过 1.5 W，稳态不超过 1.0 W |
| 路线 2 的电池续航估算 | 约 3.9 小时，按 3000 mAh 单节锂电、OCXO 稳态 2 W 计 |
| 短稳目标 | 1 秒阿伦偏差不劣于 1e-11 |

### 10.3 待办事项

1. 复核 TPS7A8901 的实际单通道电流能力与压差，本文按 500 mA 估算。
2. 确定 R10 与 R11 的实际阻值，明确 `+3.3/+5V` 轨的目标电压，当前是占位值。
3. 复核 R6 180 欧与 R24 49.9 欧的分压比是否满足 LMK1C1102 的输入门限，并确认 U8 的 VDD 焊盘连接。
4. 确定走路线 1、2 还是 3 之后，按第 4 节清单锁定 2 到 3 个候选型号，各买 1 只按第 8 节验收，用实测数据定型。
5. 把最终选定型号的 EFC 极性、牵引量 Hz 每伏、预热时间写入固件常量与 `hardware/bom/`。

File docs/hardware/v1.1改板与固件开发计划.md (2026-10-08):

# GPSDO v1.1 改板与固件开发计划

> **本计划的依据与前提。** 硬件现状由 `hardware/schematic/v1.0` 工程文件解析并经 `kicad-cli` 导出网表核对；固件现状由 `firmware/` 下的实际代码统计。改动理由来自同目录的三份文档：`OCXO选型文档`、`GNSS模组选型文档`、`开源GPSDO项目对比文档`。
>
> **关键前提：本计划假设走"真 OCXO + 便携锂电"路线**（即 OCXO 选型文档里的路线 1/2），而不是改用超稳 MEMS 的路线 3。如果决定改走 MEMS，本文的 HW-1、HW-2 中关于 5 V 升压与 EFC 模拟链路的全部内容失效，固件的 M4 与 M5 需要重写为 I²C 数字调频。**若路线未定，请先定这个，再看第 2 节。**

---

## 1. 现状盘点

### 1.1 硬件：基本完整，有五处待改

v1.0 的整体架构是对的——MCU、GNSS、OCXO、时钟缓冲、电源管理、USB、充电、按键、蜂鸣器都已就位，PCB 已布完。问题集中在 OCXO 供电能力、EFC 模拟链路、GNSS 定时能力这三块，详见第 2 节。

### 1.2 固件：实际上是空的

这是本计划里最需要正视的事实。

| 文件 | 行数 | 实际内容 |
| --- | --- | --- |
| `src/main.c` | 32 | 调用三个空函数的框架 |
| `src/app/app_main.c` | 16 | 空函数 |
| `src/hal/hal_init.c` | 13 | 空函数 |
| `src/services/service_manager.c` | 13 | 空函数 |
| `boards/default/board_config.h` | 36 | **模板，且内容与实际硬件矛盾** |
| **合计** | **194** | **没有任何 GPSDO 功能代码** |

没有 NMEA 解析、没有定时器捕获、没有 PI 控制环、没有 PWM 输出、没有 ADC 采集、没有状态机、没有数据记录。**固件是从零开始，不是改进。**

### 1.3 三处文档与实物不一致，必须先修正

| 位置 | 当前内容 | 实际硬件 |
| --- | --- | --- |
| `boards/default/board_config.h` | `MCU_TYPE "STM32F407"`，`SYSTEM_CLOCK_HZ 168000000` | **STM32G431KBU6，170 MHz** |
| `board_config.h` 引脚定义 | PA9/PA10 UART、PA4-PA7 SPI、PB6/PB7 I2C、PC13 LED、PA0 按键 | 见 3.1 节实测表。**UFQFPN32 封装没有 PC13**；PA0 是 10 MHz 输入不是按键；SPI 根本没用 |
| `hardware/pinout/pinout.md` | 十行通用模板 | 同上 |
| `README.md` 硬件规格 | 列了 ADS1115/ADS1258、TMP117、PCF8563 | **原理图里都不存在**。板上唯一的 I²C 设备是 BQ25890 |

### 1.4 构建系统还不能产出可烧写固件

`firmware/CMakeLists.txt` 没有交叉编译工具链文件、没有 `CMAKE_SYSTEM_NAME`、没有链接脚本、没有启动文件、没有引入 STM32 HAL 或 LL 库。全仓库只有 `ci/workflows/build.yml` 里装了 `gcc-arm-none-eabi`，但 CMake 侧并未使用它。

**现在执行 README 里的 `cmake -B build -DBOARD=default` 只会用主机编译器编译三个空文件，产出一个 x86 可执行文件。** 这是 M0 存在的原因。

---

## 2. 硬件改动清单

@fig:v11_roadmap 图 1　v1.1 的硬件轨与固件轨及其依赖关系

### 2.1 P0 必改（不改则达不到设计目标）

#### HW-A　OCXO 供电：解决 5 V 与电流上限

| 项 | 内容 |
| --- | --- |
| 问题 | `+3.3/+5V` 轨由 TPS7A8901 线性稳压，输入是 SYS（3.0–4.4 V），**结构上做不出 5 V**；单通道约 500 mA，3.3 V 下仅 1.65 W，而典型 OCXO 预热要 3–6 W，**会触发限流反复重启** |
| 来源 | OCXO 选型文档 2.2 节 |
| **方案 A（低成本，优先评估）** | **复用 BQ25890 的 OTG 升压**。U5 的 OTG 控制脚已连到 MCU 的 PB3，BQ25890 的 OTG 模式能从电池升压出 5 V 到 VBUS，典型能力 1.2–2.4 A。**这意味着可能不需要新增升压 IC** |
| 方案 A 的风险 | OTG 输出在 VBUS 上，需要把 VBUS 引回板内给 OCXO，必须处理：USB 插入时的冲突与反灌、OTG 使能时序、USB 供电与电池供电的切换逻辑。**这几点必须在改板前用 BQ25890 datasheet 确认清楚** |
| 方案 B（稳妥） | 新增独立升压 IC（能力 ≥1.5 A）后串一级超低噪 LDO 稳到 5.0 V。多 6 个元件，但逻辑简单、无耦合风险 |
| 共同要求 | 升压是开关电源，纹波会经供电灵敏度调制频率并抬高相噪底，**必须串一级低噪 LDO，留 300–500 mV 压差** |
| 顺带 | R10/R11 的值目前是占位符（写成 "100nF" 和 "GND"），需定为实际反馈电阻 |
| 验证 | 用限流电源模拟 OCXO 预热负载（0.2→1.0 A 阶跃），测 5 V 轨的跌落与恢复；用示波器测纹波 |

#### HW-B　EFC 加运放缓冲

| 项 | 内容 |
| --- | --- |
| 问题 | EFC 节点源阻抗 **40 kΩ**（R4+R5 各 20 kΩ）。OCXO 的 EFC 输入阻抗 Rin 会与之分压，Rin=100 kΩ 时只剩 71%，且 Rin 随温度变化转成控制增益漂移 |
| 来源 | OCXO 选型文档 风险 A；**并且开源 GPSDO 对比文档发现 Carsten Andrich 的 STM32G4 方案正是这么做的**——他在调谐 DAC 之后加一级 1 Hz 有源低通 |
| 方案 | 在二阶 RC 之后加一级轨到轨运放电压跟随器（OPA333 或 OPA192 级别，低失调低噪声）。或按 Andrich 的做法把第二级 RC 直接做成有源低通，一次解决滤波与阻抗两件事 |
| 代价 | 1 颗运放 + 2 个无源件 |
| 验证 | 串入 100 kΩ 前后测 VCTL 电压变化，加缓冲后应无可测变化 |

#### HW-C　GNSS 换定时级模组

| 项 | 内容 |
| --- | --- |
| 问题 | SKG123N 是**导航级**模组，没有定时模式，1PPS 受位置解算噪声污染；而且**没有锯齿波修正消息** |
| 来源 | GNSS 模组选型文档 第 3、6 节 |
| 方案 | 换 **u-blox NEO-F10T**（L1+L5 双频定时级）或 **NEO-M8T**（单频、资料最全）。**本板焊盘是 12.20×16.30 mm / 24 pad，与 u-blox NEO 封装尺寸一致，且 pin 3=1PPS、10=GND、11=RF_IN、23=VCC 四个关键脚已核对对应，改板量可能为零** |
| **前置条件** | 必须先完成 GNSS 文档第 7 节的 24 脚逐一核对。**这件事没做完之前不要下单** |
| 若脚位不兼容 | 退回 SkyTraq PX1100T（10.1×9.7 mm，5 ns，支持 PSTI,00），代价是重画焊盘 |
| 验证 | 见 GNSS 文档第 8 节；核心是 M4 完成后锯齿波修正前后的抖动对比 |

#### HW-D　输出链路复核

| 项 | 内容 |
| --- | --- |
| 问题一 | R6 180 Ω 与 R24 49.9 Ω 构成分压，把 3.3 Vpp 方波衰减到约 **0.72 Vpp**，可能低于 LMK1C1102 的输入高电平门限 |
| 问题二 | PCB 中 **U8（LMK1C1102）的 VDD 焊盘 pad 6 当前未连接** |
| 来源 | OCXO 选型文档 风险 C |
| 方案 | 核对 U8 的 V_IH/V_IL，串阻改 22–33 Ω；连上 U8 的 VDD |
| 注意 | 问题二若确实存在，**当前板子的时钟缓冲根本不工作**，这会掩盖其他所有问题，应优先确认 |

#### HW-E　GNSS 备电

| 项 | 内容 |
| --- | --- |
| 问题 | V_BCKP（pin 22）只经 R7 470 Ω 从 3.3 V 取电，配 C5 1 µF，**没有电池或超级电容**。断电即丢星历，每次开机都是冷启动（30 秒以上），而不是热启动（几秒） |
| 来源 | GNSS 模组选型文档 2.3 节 |
| 方案 | 补一颗超级电容（0.1–1 F）或纽扣电池 + 隔离二极管；同时核对 V_BCKP 的电流规格，确认 470 Ω 串联是否造成压降 |
| 为什么是 P0 | 便携设备频繁开关机，**"拿出来就能用"是产品体验的核心**，而冷启动直接违背它 |

### 2.2 P1 建议改（明显收益，代价小）

| 编号 | 改动 | 理由与来源 |
| --- | --- | --- |
| HW-F | **磁珠 FB1 下游补一颗 10 µF**（甚至 22 µF 聚合物电容顺便做 LC 阻尼） | 本轮已加的 FB1 把上游 C7 10 µF 隔开了，OCXO 侧只剩 C4 0.1 µF，**加热器的动态电流撑不住，加了磁珠反而可能比原来更差** |
| HW-G | 1PPS 串阻 R1 由 100 Ω 改为 **22–33 Ω** | 1PPS 的边沿陡度直接决定时间间隔测量的分辨率，应与时钟信号同等对待。来源：GNSS 文档 2.3 节 |
| HW-H | **把 10 MHz 同时送进 OSC_IN** | 当前 10 MHz 只进 PA0，MCU 的 HSE 是独立晶振 Y1。若让 MCU 以 OCXO 为系统时钟，TIC 单次分辨率可从 **100 ns 提到 5.9 ns**，见 3.2 节。这是性价比最高的一项分辨率改善 |
| HW-I | CHIP_EN（pin 8）明确上拉而非悬空 | 悬空依赖内部上拉，换模组后该位置功能会变 |
| HW-N | **PWM 与 RC 之间插一颗基准供电的单门缓冲器** | PWM 幅度即 3.3 V 轨（OCXO 选型文档 风险 B），轨上每变化 0.1 mV 约等于 EFC 跳 1 个 LSB，电池板的负载台阶会直接变成频率台阶。缓冲器由精密基准或 OCXO 的 VREF 单独供电，PWM 幅度即等于基准。代价是 1 颗 SOT-23-5 逻辑门加去耦，见 3.4 节 |

### 2.3 P2 可选（看目标定位再决定）

| 编号 | 改动 | 说明 |
| --- | --- | --- |
| HW-J | 预留 TDC7200 位置与 SPI | 把 TIC 分辨率推到 55 ps。但在 OCXO 与 GNSS 没升级之前，分辨率不是瓶颈，**不建议现在就上** |
| HW-K | 预留 Lars 式模拟 TIC（HC390 + HC4046 + 二极管 + RC 进 ADC） | 两片 HCMOS 换约 1 ns 分辨率，比 TDC7200 便宜得多。如果 HW-H 做了，收益会重叠，二选一 |
| HW-L | OCXO 热隔离的机械预留 | 泡棉或气凝胶包裹 OCXO。既稳频率又降恒温槽功耗，是便携设计里少见的双赢。但增大体积，需与外壳一起定 |
| HW-M | 外部 16 位 DAC 预留 | 做了 HW-N 之后，DAC 在基准方面已无优势；仅当所需分辨率超过 PWM 加抖动扩位所能提供的范围时才考虑。见 3.4 节 |

### 2.4 改动量小结

| 优先级 | 项数 | 新增元件估计 | 是否需要改 PCB 布线 |
| --- | --- | --- | --- |
| P0 | 5 | 方案 A 约 3–5 个，方案 B 约 10 个 | 是，电源区与 EFC 区 |
| P1 | 5 | 3–5 个 | HW-H 需加一条走线与匹配；HW-N 需在 PWM 与 RC 之间插入一颗门 |
| P2 | 4 | 视选择 | 建议留位不贴 |

---

## 3. MCU 引脚与定时器资源规划

### 3.1 实测引脚表（用它替换 `pinout.md` 与 `board_config.h`）

STM32G431KBU6，UFQFPN32，33 个焊盘（含底部散热盘）。下表直接取自网表。

| pad | MCU 引脚 | 网络 | 功能 |
| --- | --- | --- | --- |
| 1 | VDD | +3.3V | 供电 |
| 2 | PF0 | OSC_IN | HSE 晶振 Y1 |
| 3 | PF1 | OSC_OUT | HSE 晶振 Y1 |
| 4 | PG10 | RESET | NRST，接 SW1 与 R19/C21 |
| 5 | **PA0** | **10MHz_1** | **OCXO 10 MHz 输入**（经 R25 来自 LMK1C1102 的 Y0） |
| 6 | **PA1** | **1PPS** | **GNSS 1PPS 输入**（经 R1） |
| 7 | PA2 | TX2 | USART2 TX → CH340E（USB 调试串口） |
| 8 | PA3 | BUZZ | 蜂鸣器，经 Q1 |
| 9 | PA4 | — | **未连接。注意 PA4 = DAC1_OUT1** |
| 10 | **PA5** | **PWM** | **EFC 控制输出** → R4/C1/R5/C2 → VCTL。注意 PA5 = DAC1_OUT2 |
| 11 | PA6 | — | 未连接 |
| 12 | PA7 | — | 未连接 |
| 13 | **PB0** | **VCTL** | **EFC 电压回读（ADC）** |
| 14 | VSSA | GND | — |
| 15 | VDDA | +3.3V | — |
| 16 | VSS | GND | — |
| 17 | VDD | +3.3V | — |
| 18 | PA8 | — | 未连接 |
| 19 | PA9 | TX1 | USART1 TX → GNSS 模组 RX（经 R2） |
| 20 | PA10 | RX1 | USART1 RX ← GNSS 模组 TX（经 R3） |
| 21 | PA11 | — | 未连接 |
| 22 | PA12 | — | 未连接 |
| 23 | PA13 | SWDIO | 调试 |
| 24 | PA14 | SWCLK | 调试 |
| 25 | PA15 | I2C1_SCL | → BQ25890 |
| 26 | PB3 | OTG | → BQ25890 OTG 控制（**HW-A 方案 A 的关键脚**） |
| 27 | PB4 | RX2 | USART2 RX ← CH340E |
| 28 | PB5 | — | 未连接 |
| 29 | PB6 | — | 未连接 |
| 30 | PB7 | I2C1_SDA | → BQ25890 |
| 31 | PB8 | GND | **BOOT0 接地 = 正常启动** |
| 32 | VSS | GND | — |
| 33 | VSS | GND | 底部散热盘 |

空闲引脚 8 个：PA4、PA6、PA7、PA8、PA11、PA12、PB5、PB6。

### 3.2 时间间隔测量（TIC）：三个方案

硬件已经把 10 MHz 送到 PA0、1PPS 送到 PA1。**要测 OCXO 就必须拿 10 MHz 当计数时基**，这决定了当前能做到什么。

| 方案 | 做法 | 单次分辨率 | 需要改板 | 说明 |
| --- | --- | --- | --- | --- |
| **A（当前硬件可做）** | TIM2 用 PA0 的 10 MHz 作外部时钟（ETR 或外部时钟模式），PA1（CH2）输入捕获 1PPS，32 位计数器连续累积相位 | **100 ns** | 否 | **相位连续累积**使等效分辨率随观测时间线性提高：1000 s 观测约等效 1e-10。这是方案 A 能用的关键，不要只看单次 100 ns |
| **A+（软件插值）** | 在 A 的基础上，用内部 170 MHz 再捕获 10 MHz 的边沿做游标插值 | 约 6 ns | 否 | 纯固件技巧，但 MCU 时钟来自独立晶振 Y1，其噪声会进入插值结果，收益需实测确认 |
| **B（HW-H 之后）** | 10 MHz 同时送 OSC_IN，MCU 以 OCXO 为系统时钟，用 170 MHz 直接捕获 1PPS | **5.9 ns** | 是，加一条走线 | 性价比最高的分辨率改善 |
| **C（HW-J 之后）** | 外接 TDC7200 | 55 ps | 是，加芯片 | 在 OCXO 与 GNSS 升级之前不是瓶颈 |

> **更正：** 本项目早先在开源 GPSDO 对比文档里被记为"5.9 ns 定时器捕获"，这是按内部 170 MHz 算的。但那样测的是 1PPS 相对 MCU 自身晶振的时间，**测不到 OCXO**。以 OCXO 为时基时单次分辨率是 100 ns。该文档已更正。

### 3.3 定时器资源冲突（必须在写固件前解决）

**PA0 和 PA5 在 STM32G4 上都映射到 TIM2_CH1。** 如果 TIM2 被用作 TIC（ETR 取 PA0 的 10 MHz、CH2 捕获 PA1 的 1PPS、ARR 置满程做自由运行计数器），那么 PA5 就不能再用同一个 TIM2 输出 PWM——因为 PWM 周期会被满程 ARR 决定（2^32/10 MHz ≈ 429 s），毫无意义。

**必须查 STM32G431 datasheet 的 AF 复用表确认 PA5 还有没有第二个可用的定时器通道。** 三条退路，按推荐顺序：

1. **PA5 直接改用 DAC1_OUT2 输出 EFC。零改板**，固件一行配置切换。代价是 G431 的 DAC 只有 12 位，见 3.4 节。
2. TIC 改用其他定时器，前提是 PA0/PA1 对该定时器有可用 AF。
3. PWM 移到 PA4（也是空闲脚且为 DAC1_OUT1），需改板一条走线。

### 3.4 EFC 输出方式的权衡（不要想当然选 DAC）

| 方案 | 分辨率 | 牵引 5 ppm 时的步进 | 评价 |
| --- | --- | --- | --- |
| **PWM 16 位 + 二阶 RC**（当前） | 65536 级 | 0.76 mHz = **7.6e-11** | **分辨率最好**。载波 2.594 kHz，两级 RC 衰减约 140 dB，纹波可忽略 |
| 内部 DAC 12 位（PA5 或 PA4） | 4096 级 | 12 mHz = 1.2e-9 | **比 PWM 差 16 倍。"用 DAC 更高级"是错觉** |
| 外部 16 位 DAC + 基准 | 65536 级 | 同 PWM | 分辨率与 PWM 相当，优势在于摆脱了"PWM 幅度即 VDD"的基准问题（风险 B）。但 HW-N 用一颗逻辑门解决了同一问题 |
| **PWM 16 位 + 基准供电缓冲门（HW-N）** | 65536 级 | 同 PWM | **推荐。** 分辨率不变，PWM 幅度改由基准决定，与 3.3 V 轨无关 |

> **结论：保留 PWM 方案，并补上 HW-N。** PWM 的真正弱点不是分辨率而是基准：控制电压等于占空比乘以 3.3 V 轨。按牵引 5 ppm 计，占空比在 50% 附近时，**3.3 V 轨每变化 0.1 mV，EFC 就变化约 1 个 LSB（7.6e-11）**。缓慢漂移会被环路纠正，但电池板上充电启停、蜂鸣器、GNSS 与 CH340E 的负载变化会造成 mV 级的快速台阶。在 PWM 与 RC 之间插一颗由精密基准单独供电的单门 CMOS 缓冲器（HW-N），PWM 幅度就等于基准电压。基准为 3.3 V 或更低时用 74LVC1G125 一类；高于 3.3 V 时改用 TTL 输入门限的 74AHCT1G125 或电平转换器 74LVC1T45。外部 16 位 DAC + 基准（HW-M）因此不再必要。

> **更正：早先"把 VCTL 回读进 PB0 的 ADC，在固件里做比例校正"的说法不成立。** UFQFPN32 封装没有单独的 VREF+ 引脚（见 3.1 节引脚表），ADC 以 VDDA 为基准，而 VDDA（pad 15）与数字电源同接 +3.3V。于是 ADC 读数等于 VCTL 除以 3.3 V 轨，恰好就是占空比本身，3.3 V 轨怎么变都看不出来。不做 HW-N 时，只能同时测量片内参考电压 VREFINT、换算出 VDDA 的绝对值再补偿，精度受 VREFINT 自身温漂限制。PB0 回读仍然保留，用途改为监测 EFC 的开路、短路与饱和。

---

## 4. 固件开发计划

八个里程碑。**M0–M3 与 M5–M7 全部不依赖改板，可在现有 v1.0 板上立即开始**，只有 M4 需要等定时级 GNSS 模组到货。

### M0　构建系统可用

| | |
| --- | --- |
| 目标 | 能编译出可烧写到 STM32G431KBU6 的固件并点亮一个 LED |
| 任务 | 写 ARM GCC 工具链文件；引入 CMSIS 与 STM32G4 的 HAL 或 LL 库；加启动文件与链接脚本；配置 170 MHz 时钟树（HSE 来自 Y1 + PLL）；接通 `ci/workflows/build.yml` 里已装好的 `gcc-arm-none-eabi`；配置 SWD 烧写 |
| 交付物 | `firmware/cmake/arm-none-eabi.cmake`、链接脚本、可用的 `cmake --build` 产出 .elf/.bin |
| **验收** | **烧进板子，蜂鸣器响一声或状态灯闪烁；`arm-none-eabi-size` 能输出合理的段大小** |
| 依赖 | 无。**这是全部工作的起点** |

### M1　板级配置校正

| | |
| --- | --- |
| 目标 | `board_config.h` 与 `pinout.md` 与实际硬件一致 |
| 任务 | 按 3.1 节实测表重写 `boards/default/board_config.h`（MCU 改 STM32G431KBU6、时钟改 170 MHz、引脚全部按实测）；同步 `hardware/pinout/pinout.md`；修正 `README.md` 里不存在的 ADS1115/TMP117/PCF8563 |
| 交付物 | 两个文件 + README 勘误 |
| **验收** | **逐脚与 3.1 节表核对一致；每个宏都能在代码里被用到或明确标注保留** |
| 依赖 | 无，可与 M0 并行 |

### M2　基础驱动

| | |
| --- | --- |
| 目标 | 各外设单独可用 |
| 任务 | USART1 收 GNSS 的 NMEA（中断或 DMA）；USART2 做调试输出与 AT 指令；NMEA 解析（至少 GGA/RMC/GSV，拿到定位状态与可见卫星数）；PA5 的 PWM 输出（16 位，载波 2.594 kHz）；PB0 的 ADC 读 VCTL；I²C1 与 BQ25890 通信读电池状态；LED 与蜂鸣器 |
| 交付物 | `src/drivers/` 下各驱动 + `src/services/` 下 NMEA 服务 |
| **验收** | **调试串口能打印出 UTC 时间、定位状态、可见卫星数、电池电压；示波器能看到 PWM 占空比随指令变化；ADC 读回的 VCTL 与万用表实测在 1% 内吻合** |
| 依赖 | M0、M1 |

### M3　时间间隔测量

| | |
| --- | --- |
| 目标 | 输出可信的原始相位序列 |
| 任务 | **先解决 3.3 节的定时器冲突**；实现 3.2 节方案 A（TIM2 外部时钟 + CH2 捕获 + 32 位相位连续累积）；处理计数器溢出与 1PPS 丢失；把每秒的相位值经串口输出 |
| 交付物 | `src/services/tic.c`，输出时间戳序列 |
| **验收** | **OCXO 自由运行时，相位序列应是一条带噪声的直线，斜率等于频差。把 EFC 改一个已知量，斜率应按预期变化——这同时验证了 TIC 与 EFC 两条链路的极性与增益** |
| 依赖 | M2 |

### M4　锯齿波（量化误差）修正

| | |
| --- | --- |
| 目标 | 把 1PPS 的有效抖动压低一个数量级 |
| 任务 | 实现 UBX 二进制协议解析（NEO 系列）或 PSTI,00 解析（SkyTraq）；取出 qErr；**注意 u-blox 的 qErr 单位是皮秒，要除以 1000 换成纳秒**；**qErr 仅在 1 Hz 脉冲时有效**；从 M3 的时间间隔值里减掉它 |
| 交付物 | `src/services/gnss_ubx.c` + 修正逻辑 |
| **验收** | **同一组数据，修正前后算标准差，修正后应明显下降。下降不明显说明符号或单位换算错了。同时把未修正的序列画出来应能看到明显三角波** |
| 依赖 | M2、M3，**以及 HW-C 的模组到货**。这是唯一需要等硬件的固件里程碑 |
| 为什么优先 | **投入产出比最高的一项：纯固件、零硬件成本，而当前完全没做** |

### M5　控制环与状态机

| | |
| --- | --- |
| 目标 | 能稳定锁定 |
| 任务 | PI 控制器（先按 Lars 方案的参数整定思路起步）；交越时间常数可配，初值取 100–1000 s；状态机：上电 → OCXO 预热 → GNSS 捕获 → 粗调 → 精调锁定 → 失锁保持；EFC 限幅与饱和处理；VCTL 的 ADC 回读用于监测 EFC 开路、短路与饱和（不能用来校正基准漂移，见 3.4 节更正；风险 B 由 HW-N 在硬件上解决） |
| 交付物 | `src/app/` 下控制环与状态机 |
| **验收** | **从冷启动到进入 ±1 ppb 带宽的时间可测量并记录；人为扰动 EFC 后环路应自行恢复；连续运行 24 小时不失锁、不饱和** |
| 依赖 | M3（M4 可后补，但有 M4 时性能更好） |

### M6　数据记录与上位机对接

| | |
| --- | --- |
| 目标 | 能出 ADEV 图 |
| 任务 | 按 TimeLab 可读的格式导出时间间隔序列（制表符分隔的时间戳序列）；串口协议完善（参考 README 里已设计的 AT 指令集）；记录温度、电池、卫星数等协变量以便做相关性分析 |
| 交付物 | 导出格式说明 + 上位机采集脚本 |
| **验收** | **把一段不少于 10 小时的数据导入 TimeLab，能画出 ADEV 曲线，且曲线形状符合开源 GPSDO 对比文档图 1 的定性预期** |
| 依赖 | M3 |

### M7　守时与快速启动

| | |
| --- | --- |
| 目标 | 解决便携场景"拿出来就能用" |
| 任务 | **把最后一次锁定的 EFC 值存进 Flash，开机直接打到该值**，跳过大段收敛；配合 HW-E 的备电实现 GNSS 热启动；失锁保持（holdover）策略；可选的温度前馈补偿（需先采集频温曲线） |
| 交付物 | `src/services/` 下的参数持久化 + holdover 逻辑 |
| **验收** | **断电再上电，进入 ±1 ppb 的时间应显著短于 M5 的冷启动基线；拔掉天线后 1 小时内的频率漂移可测量并记录** |
| 依赖 | M5；温度前馈还需 M6 的数据 |

---

## 5. 测量与验证计划

### 5.1 最大的门槛不是电路，是参考源

要验证 1e-11 以上的性能，需要一个比被测对象更好的参考。**用本项目的 MCU 去测本项目的 OCXO，测到的是两者误差的组合。**

| 方案 | 代价 | 能验证到 |
| --- | --- | --- |
| 长时间与 GPS 比对取统计 | 零 | 长 tau 段（交越点以右），足够验证锁定与长稳 |
| 买一台已知良好的成品 GPSDO 做互比 | 中 | 全段，但只能得到两者的组合误差 |
| 铷钟 | 高 | 短中 tau 段，是验证 OCXO 真实短稳的唯一实际途径 |
| 自制 TAPR TICC（BSD 开源，TDC7200，<60 ps） | 低–中 | 作为独立的高分辨率测量工具，不受本项目固件 bug 影响 |

**建议：先用"长时间 GPS 比对"走完 M0–M6，这不需要额外投入；在需要验证短稳时再考虑 TICC 或铷钟。**

### 5.2 必备工具

| 工具 | 用途 | 状态 |
| --- | --- | --- |
| **TimeLab** | ADEV 绘图与分析的事实标准 | 免费，需安装 |
| 限流实验室电源 | OCXO 预热电流曲线、模拟负载阶跃 | 必需 |
| 示波器 ≥100 MHz | 输出波形、PWM 纹波、1PPS 边沿 | 必需 |
| 频率计 | OCXO 的 EFC 牵引曲线实测 | 可用本板的闸门计数替代，精度较低 |
| 万用表 | 供电、压降、VCTL 校核 | 必需 |

---

## 6. 风险登记册

| 编号 | 风险 | 影响 | 应对 |
| --- | --- | --- | --- |
| R1 | **NEO 系列与本板焊盘脚位不完全兼容** | HW-C 从"零改板"变成"重画焊盘"，M4 延后 | 下单前完成 24 脚核对；备选 PX1100T |
| R2 | **PA5 没有可用的第二定时器通道** | PWM 与 TIC 冲突 | 见 3.3 节三条退路，首选改用 DAC1_OUT2（零改板） |
| R3 | BQ25890 的 OTG 复用方案（HW-A 方案 A）存在反灌或时序问题 | 退回方案 B，多 6 个元件 | 改板前先用 datasheet 确认，必要时先搭飞线验证 |
| R4 | **U8 的 VDD 未连接，当前板子时钟缓冲可能根本不工作** | 会掩盖其他所有问题 | **列为最优先确认项**，用万用表直接量 |
| R5 | OCXO 预热功耗超出供电能力 | 上电反复重启 | 选型时卡死预热峰值；HW-A 完成后复测 |
| R6 | 固件从零开始，工作量被低估 | 进度延期 | M0 到 M3 是硬骨头，先做；M4 之后每步都有明确验收 |
| R7 | 便携使用的振动与温度冲击吃掉 OCXO 的短稳优势 | 实际性能不如预期 | HW-L 热隔离；选低 g 敏感 OCXO（参考 Andrich 的做法） |
| R8 | 测量结果不可信导致调参方向错误 | 浪费大量时间 | 严守 5.1 节的参考源原则，M3 与 M4 的验收标准都设计成自校验 |

---

## 7. 执行顺序建议

### 7.1 立即可做的三件事（零采购、零改板、零等待）

1. **用万用表确认 U8 的 VDD 是否真的没连**（风险 R4）。五分钟的事，但它可能是当前板子的拦路虎。
2. **查 STM32G431 datasheet 的 AF 复用表，解决 3.3 节的 PA5 定时器冲突**（风险 R2）。这个结论会决定 M3 的实现方式和是否需要改板。
3. **开始 M0**：搭交叉编译工具链。这是所有固件工作的前提，而且完全不依赖硬件决策。

### 7.2 两轨并行

**硬件轨**（受采购与打样周期约束）：先完成 HW-C 的脚位核对与 HW-A 的方案选择 → 器件采购 → 原理图与 PCB 改动 → 打样 → 硬件验收。

**固件轨**（不占用采购周期）：M0 → M1 → M2 → M3 → M5 → M6，全部可在现有 v1.0 板上完成。**M4 卡在模组到货，但它可以插在 M5 之后补做，不必阻塞主线。**

### 7.3 一个取舍提醒

本计划的 P0 五项都有明确依据，但**它们的收益并不均等**。按对最终 ADEV 的贡献排序：

**HW-C（定时级 GNSS）+ M4（锯齿修正）> HW-A（供电能力，属于"不做就不工作"）> HW-B（EFC 缓冲）> HW-H（TIC 分辨率）> OCXO 升级。**

如果资源有限，**优先把 HW-C 加 M4 这一对做完**——它改善的是交越点右边的长 tau 段，而这正是 GPSDO 相对裸 OCXO 的全部价值所在。

---

## 8. 待确认事项清单

下面每一条都会改变计划内容，建议逐条消解。

| 序号 | 待确认 | 影响 |
| --- | --- | --- |
| 1 | **路线选择：真 OCXO 还是超稳 MEMS** | 决定本计划是否整体适用，见开头前提 |
| 2 | u-blox NEO-F10T / NEO-M8T 的 24 脚是否与本板焊盘完全兼容 | HW-C 的改板量 |
| 3 | PA5 在 STM32G431 上的全部定时器 AF | M3 实现方式与是否改板 |
| 4 | BQ25890 的 OTG 能否安全地给板内 5 V 供电 | HW-A 选方案 A 还是 B |
| 5 | TPS7A8901 的实际单通道电流能力与压差（本文按 500 mA 估算） | 供电余量核算 |
| 6 | U8 的 VDD 焊盘是否真的未连接 | 当前板子能否工作 |
| 7 | 目标续航与精度指标 | 电池容量、OCXO 功耗档位、是否值得做热隔离 |
| 8 | 是否接受 GPL-3.0（若直接参考 AndrewBCN 的固件代码） | 固件许可策略 |

---

## 9. 相关文档

| 文档 | 本计划中引用的内容 |
| --- | --- |
| `docs/hardware/OCXO选型文档.pdf` | HW-A 供电约束、HW-B 风险 A、HW-N 风险 B、HW-D 风险 C、3.4 节 EFC 分辨率计算 |
| `docs/hardware/GNSS模组选型文档.pdf` | HW-C 的 NEO 封装兼容性发现、HW-E 备电、HW-G 串阻、M4 的锯齿修正依据 |
| `docs/hardware/开源GPSDO项目对比文档.pdf` | 3.2 节 TIC 方案、HW-B 借鉴 Andrich 的有源滤波、M5 借鉴 Lars 的环路整定、5.1 节参考源问题 |

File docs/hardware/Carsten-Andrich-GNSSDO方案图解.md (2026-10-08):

# Carsten Andrich GNSSDO 方案图解

> **资料来源与可信度声明。** 本文的电路细节全部取自作者公开的两版原理图 PDF（v1：2022-08-05；v2：2022-08-10 至 08-11）和 v2 版图 PDF，设计思路取自作者在 time-nuts 邮件列表与 EEVblog 论坛的两个讨论串（2022-08-05 至 2022-09-03），逐条来源列在第 13 节。**截至作者最后一条公开帖（2022-09-03），整机没有发布任何实测结果，固件与 KiCad 工程也未公开**，只有原理图与版图的 PDF。文中的滤波器 f0、Q、群时延与幅频曲线是本文按原理图元件值**自行计算**的；标注"推断"的内容是本文根据帖子描述整理，作者并未明说。

---

## 1. 方案速览

| 项目 | 内容 |
| --- | --- |
| 作者 | Carsten Andrich，自述职业为射频工程师 |
| 发布 | 2022-08-05 同时发到 time-nuts 与 EEVblog；08-11 更新原理图并发布版图 |
| 用途 | 移动车辆之间的精确时间同步，服务于分布式 SDR 的相干采样与毫米波变频器。载体主要是汽车，也可能上飞机 |
| 为什么自己做 | 作者在工作中用过 Ministd、Jackson Labs LC_XO、SRS FS740，移动中都不满足要求 |
| 指标目标 | 10 km 半径内、移动中相对时间误差 < 10 ns，**期望 < 1 ns**。只要求相对同步，不关心绝对 UTC 误差 |
| 成本目标 | 单台器件与制造费用 < 500 欧元，**不含 OCXO** |
| 开发优先级 | 性能 > 简洁 > 性价比（作者原话的顺序） |
| 核心器件 | ZED-F9T（用 RCB-F9T 评估板）、TDC7200、STM32G474RE、Abracon AOCJY OCXO、LMK1C1103、AD5542A、ADR4533、OPA189、BUF602 x5、TMP117；v2 加 IIM-42652 IMU |
| 板子 | 100 x 100 mm，5 路 SMA，三路电源全部外供 |
| 进度 | 原型设计定稿；TDC7200 死区问题已用面包板实测验证；**整机性能未见公开** |

@fig:ca_usecase 图 1　应用场景：基准站播发差分修正，各车辆上的 GNSSDO 彼此相对同步

### 1.1 作者明确提出的三处改进

作者说明这套架构受 thinkfat（Matthias Welwarsky）的 STM32 + TDC7200 方案启发，并在三处做了改动：

| 方面 | thinkfat 的做法 | Andrich 的做法 | 理由（作者自述） |
| --- | --- | --- | --- |
| OCXO 输出给 TDC | 经 74HC390 分频 | **10 MHz 直接送 TDC7200**，不分频 | 分频器的传播延迟随温度变化 |
| 时钟分配器件 | 74 系列逻辑 | **只用 LMK1C110x 这类低抖动时钟芯片** | 74 系列没有抖动与相噪指标 |
| 调谐电压 | DAC 直接送 OCXO | **DAC 后加 1 Hz 有源低通** | 一是压低电源、基准、DAC 送进 EFC 的噪声；二是为在 16 bit 之上叠加 PWM 扩展分辨率留出条件 |

---

## 2. 系统架构

@fig:ca_system 图 2　系统总框图（v2 原理图），颜色区分信号类型

整机分成四块：**GNSS 接收**（RCB-F9T 板插在主板上）、**时间测量**（MCU 定时器 + TDC7200）、**OCXO 及其调谐**（DAC、基准、有源滤波、OCXO、时钟分配）、**输出驱动**（5 路 BUF602）。

### 2.1 关键器件

| 位号 | 器件 | 作用 | 关键参数 |
| --- | --- | --- | --- |
| U201 | STM32G474RETx | 主控 | 170 MHz；TIM2 为 32 bit，单拍 5.88 ns；HRTIM 等效 184 ps |
| U231 | TDC7200 | 时间间隔测量 | 单次约 55 ps；模式 1 量程 12 ns 起；外部时钟 1 至 16 MHz |
| U321 | Abracon AOCJY | 10 MHz OCXO | 3.3 V 供电；原理图标注预热峰值电流 1.1 A |
| U331 | LMK1C1103 | 1 分 3 时钟缓冲 | 通道偏斜 <= 50 ps（-40 至 125 摄氏度），上升沿 <= 0.7 ns（作者引用） |
| U302 | AD5542A | 16 bit 调谐 DAC | 无缓冲 R-2R 输出，内阻约 6.25 k 欧，与码值无关 |
| U301 | ADR4533 | DAC 电压基准 | 3.3 V；可用 JP302 改接 OCXO 自身的 VREF 输出 |
| U311 | OPA189 | 二阶有源低通 | 零漂移运放，+5 V 单电源供电 |
| U341 | TMP117 | 温度传感器 | 放在 OCXO 塑料罩内 |
| U401 至 U491 | BUF602 x5 | 50 欧输出驱动 | 每路串 49.9 欧源端匹配 + TVS |
| J102 | RCB-F9T | ZED-F9T 评估板 | 2x4 排针叠插：V_ANT、VCC、TXD、RXD、RST、TP1、TP2、GND |
| J103 | IIM-42652 子板 | 6 轴 IMU（v2 新增） | SPI3 + MCU 提供的外部时钟 |

**电源：** 主板上**没有任何稳压器**。+5 V、+3.3 V、-5 V 三路由 J101 四针端子外供：+5 V 给 OPA189、ADR4533 与天线偏置，+3.3 V 给 MCU、TDC、DAC、OCXO、LMK、F9T，+/-5 V 给 BUF602。

---

## 3. 时钟与脉冲分配

@fig:ca_clock_tree 图 3　10 MHz 与各路脉冲的完整路径（v2），按相干域与异步域分区

这张图是理解整个方案的关键，要点有四：

1. **只有 GNSS 脉冲是异步信号。** TDC 的时基、MCU 的全部定时器、对外输出的脉冲，全部来自同一个 OCXO，经同一片 LMK1C1103 分出。MCU 通过 PF0（OSC_IN）以 HSE 旁路方式直接吃 10 MHz，再由 PLL 倍频到 170 MHz，因此 TIM2 每 100 ns 恰好走 17 拍，与 10 MHz 严格同相。
2. **全程不分频、不同步。** 作者拒绝 74 系列的理由有具体数字：74HC74 在 5 V 下传播延迟典型 14 ns、最大约 40 ns；即使 74AHC74 在全温区也有 1.0 至 8.5 ns 的跨度，这个不确定性会直接落在"TDC 测到的沿"与"SMA 输出的沿"之间。LMK1C1103 的通道间偏斜全温区不超过 50 ps，**各通道一起漂，相互抵消**。
3. **上升沿速度。** TDC7200 要求 START、STOP、CLOCK 的上升时间标称 1 ns。74HC74 的转换时间典型 7 ns、最大 19 ns，不满足；LMK1C110x 的上升沿不超过 0.7 ns。
4. **输出脉冲由 OCXO 派生，不直接用 GNSS 脉冲。** GNSS 原始脉冲 TP2 另走一路 BUF602 送到 SMA，只作对照。

> **v2 的一处细节：** LMK 到 MCU、到 TDC 的两路各加了一个 0 欧串联电阻 R331、R332（v1 没有）。作者没说明用途，推断是预留的阻尼或调试断点。

---

## 4. 时间间隔测量：TIM2 粗测 + TDC7200 细测

### 4.1 原理

@fig:ca_tic_timing 图 4　两级时间测量时序。情形 A 是常规情况，情形 B 是 10 MHz 沿落进 TDC 死区的情况

TDC7200 的模式 1 只能测十几到几百 ns 的短间隔，而且单次误差随间隔线性增大（见 4.3 节）。作者的做法是：

- **START 接 GNSS 脉冲，STOP 与 CLOCK 都接连续的 10 MHz**（经 JP231 短接）。于是 TDC 测到的是"脉冲到其后第一个可用 10 MHz 沿"的时间 tau，范围 12 至 112 ns，这是**周期内的精细相位**。
- **TIM2 的 32 bit 输入捕获（PB11，TIM2_CH4）同时给出粗时刻 t_c**，分辨率 5.88 ns，用来判定"是哪一个 10 MHz 周期"，即解决 TDC 读数的 100 ns 周期模糊。
- 组合：k = round((t_c + tau) / 100 ns)，脉冲精确时刻 t = k x 100 ns - tau。

**一个容易忽略的好处：粗测的误差只要小于正负 50 ns 就不影响取整。** 所以 TIM2 输入同步造成的几个时钟周期的固定延迟完全无关紧要，粗测不需要标定到 ns 级。

### 4.2 TDC7200 死区之争与作者的解法

@fig:ca_tdc 图 5　左：周期性 STOP 下的读数折叠关系；右：作者面包板实测的单次标准差

发帖次日，vk3jpk 指出 TDC7200 模式 1 的最小可测间隔是 12 ns，脉冲落在 10 MHz 沿之前 0 至 12 ns 的情况（约 12% 的时间）会出问题，并建议照 TAPR TICC 的思路加一级 D 触发器同步器。thinkfat 也提到他用 74HC74 把 STOP 延迟一个周期。社区里的三种方案：

| 方案 | 做法 | 代价 |
| --- | --- | --- |
| 同步器（TICC 思路） | D 触发器链把脉冲同步到 10 MHz，TDC 测脉冲到同步器输出 | 多器件，触发器延迟随温度变化，需从 TDC 结果中消掉 |
| STOP 延迟一周期（thinkfat） | 74HC74 把 STOP 推后 100 ns | 多器件，上升沿慢 |
| **作者的方案 A：利用周期性** | 不加任何器件。第一个沿落进死区就被忽略，TDC 自然测到下一个沿，读数从 0 至 12 ns 折叠到 100 至 112 ns | 折叠区的读数长了 100 ns，单次误差略大 |
| 作者的方案 B | TDC7200 寄存器 CLOCK_CNTR_STOP_MASK = 1，开始后等一个时钟周期再接受 STOP | 方案 A 失败时的后备 |

作者坚持方案 A 的理由：数据手册没有任何地方说 STOP 落在死区或先于 START 会影响后续测量；而且他不愿为一个"没有坚实技术理由"的同步器引入额外的温度相关延迟。

**他随后用实测验证了这个假设（2022-08-28）。** 做了一块 TDC7200 转接板插在 Nucleo-G474RE 上，用 TIM2 产生间隔可编程的 START/STOP（正间隔每点测 10 万次，负间隔每点 1 万次）：

| 结果 | 说明 |
| --- | --- |
| STOP 先于或等于 START | **100% 判为溢出无效，不产生错误读数**，下一次测量不受影响 |
| 设定间隔 5.88 ns | 仍有 99.8% 有效，平均读数 6.71 ns。说明标称 12 ns 是保证值，实际门限更低；设计上仍应按 12 ns 处理 |
| 设定间隔 >= 11.76 ns | 100% 有效 |
| 单次标准差 | 随间隔近似线性增长，拟合斜率约 0.87 ps/ns；12 至 112 ns 工作区内约 13 至 75 ps |

### 4.3 实测中发现的一个坑：GPIO 输出速度

2022-09-03 作者补充：START/STOP 由 MCU 的 GPIO 产生时，**GPIO 输出速度档位明显影响 TDC 的单次标准差**。下表摘自他发布的原始数据（TIM2 运行在 160 MHz，TDC 时钟为 160 MHz 经 MCO 16 分频的 10 MHz，单位 ps）：

| 设定间隔 | 速度档 0（低） | 档 1 | 档 2（高） | 档 3（最高） |
| --- | --- | --- | --- | --- |
| 12.5 ns | 217 | 75 | 54 | 42 |
| 50 ns | 227 | 64 | 55 | 47 |
| 150 ns | 233 | 115 | 101 | 114 |
| 500 ns | 258 | 240 | 241 | 426 |
| 2000 ns | 547 | 520 | 520 | 1209 |

最低档最差，最高档在长间隔反而劣化，作者暂定用"高"档，原因尚未用示波器查明。**对 GNSSDO 本身影响不大**——在整机里 START 来自 F9T、STOP 来自 LMK，都不是 MCU 的 GPIO；但对用 MCU 产生测试信号做标定的场景是个实用提醒。

### 4.4 分辨率不是瓶颈

论坛里多人（WatchfulEye、thinkfat）指出，在环路关心的带宽内，**ZED-F9T 定时脉冲本身的噪声比 TDC7200 高几个数量级**。作者也认同，并据此放弃了功能更强但更贵的 ScioSense AS6500——用 AS6500 虽然可以省掉 MCU 定时器的粗测，但生成稳定输出脉冲仍需要一个同步到 OCXO 的 MCU 定时器，收益不大。WatchfulEye 还给了一个技巧：可以"借用"模式 2，只取时钟计数与 TIME1 的小数部分，丢掉 TIME2，避免两次测量噪声相加。

---

## 5. OCXO 调谐链路

### 5.1 电路

@fig:ca_dac_sch 图 6　按作者原理图重绘的调谐电压链路，元件值按"v1 / v2"标注

信号路径：**ADR4533（3.3 V）或 OCXO 自身 VREF → AD5542A 16 bit DAC → 二阶 Sallen-Key 有源低通（单位增益，OPA189）→ 无源 RC（100 欧 + 10 uF）→ OCXO 的 VCTL**。几个设计细节：

- **基准二选一（JP302）。** 用 OCXO 自带的 VREF 时，DAC 输出与 OCXO 内部基准成比例，基准漂移被抵消一部分；用 ADR4533 时噪声与温漂由独立的精密基准决定。
- **AD5542A 的 LDAC 接地**，数据在 CS 上升沿直接锁存，只需 SPI1 的三根线（不读回）。
- **为什么有源级后面还要一级无源 RC。** 在几 kHz 以上，C313 近似短路，输入电流经 R311 直接灌到运放输出端；运放的闭环输出阻抗随频率升高，于是有源级的衰减到某个频率后不再增加，反而以 +20 dB/十倍频回升，原理图上标注为"斜率在 3 至 4 kHz 处反转"。后面那级 159 Hz 的 RC 把这段回升压平。
- **R313 只取 100 欧。** 作者解释：12 k 欧的电阻在 300 K 时热噪声约 14 nV/根号Hz，已高于 OPA189 的输出噪声，所以第二级用小电阻大电容"宁可保守"。
- **OCXO 罩在 Hammond 1551P 塑料盒里挡气流**，罩内放 TMP117 测温。

### 5.2 两版参数与本文计算

| 参数 | v1（2022-08-05） | v2（2022-08-11） |
| --- | --- | --- |
| R311 / R312 | 13 k / 10 k | 8.2 k / 15 k |
| C313 / C314 | 20 uF / 10 uF | 2.2 uF / 1 uF |
| f0（按原理图） | **0.99 Hz** | **9.68 Hz** |
| Q | 0.70（接近巴特沃斯） | 0.71 |
| 群时延：直流 / 峰值 | 0.23 s / 0.28 s（0.62 Hz 处） | 0.024 s / 0.029 s（6.2 Hz 处） |
| 计入 DAC 内阻 6.25 k 后的 f0 与 Q | **0.81 Hz**，Q 0.67 | **7.29 Hz**，Q 0.74 |
| 计入 DAC 内阻后的群时延峰值 | 0.33 s | 0.039 s |
| 作者标注的斜率反转点 | 3 至 4 kHz | 约 10 kHz |
| 本文模型算出的反转点 | 3.2 kHz | 12.6 kHz |

@fig:ca_lpf_bode 图 7　两版调谐滤波器的幅频响应（按原理图元件值计算）

> **一个旁证：** 作者在帖子中给出 v1 的 PSpice 结果"群时延在约 0.5 Hz 处达到峰值约 0.27 s"，与本文**不计 DAC 内阻**时算出的 0.28 s @ 0.62 Hz 吻合，计入内阻后则是 0.33 s。可见作者仿真时把 DAC 当成了理想电压源（他也说明用的是"2 V 直流偏置 + 1 mV 交流"的激励源）。

### 5.3 为什么要更细的调谐分辨率

@fig:ca_tuning 图 8　DAC 一个 LSB 的频率步进在 tau 内累积出的时间误差

作者的算例：假设 OCXO 调谐范围 2 ppm 全部落在 16 bit DAC 的满量程内，一个 LSB 对应 30.5 ppt；持续 10 s 就累积 305 ps，**已经比 TDC7200 的约 50 ps 分辨率粗了 6 倍**。所以他希望在 DAC 之上再叠加 PWM 或 PAM（用 STM32G4 的定时器或 DAC 的循环 DMA）扩展有效位数——这正是 1 Hz 低通的第二个用途。

这个设计在 time-nuts 上引发了一轮讨论：

| 观点 | 提出者 | 要点 |
| --- | --- | --- |
| 滤波器时延会带来环内相移和噪声峰化 | Bob kb8tq | 控制环不分模拟数字，时延就是时延，无法"补偿掉" |
| 群时延对慢环路可忽略 | 作者 | 0.27 s 的群时延对 10 s 以上的环路时间常数可忽略；1PPS 驱动的环路时间常数本来就不可能小于 1 s；数字环可把滤波器传函和死区时间显式计入 |
| 其实几乎不用滤波 | WatchfulEye | 按窄带调频近似，VCTL 噪声引起的相噪约为 20 log10(S x Nv(f) / 2f)。以 0 至 4 V 调 +/-2 ppm 的廉价 OCXO（S = 10 Hz/V）为例，1 LSB 方波扰动在 10 Hz 偏移处约 -122 dBc/Hz，远低于廉价 OCXO 自身相噪 |
| PWM 抖动比 DAC 更便宜 | MIS42N | 用 PIC 的 10 bit PWM 逐脉冲抖动扩到 24 bit，FET 对管缓冲加无源滤波，粒度优于 1 uV |

v2（08-11）把截止频率从 1 Hz 提到 10 Hz，群时延随之降为原来的十分之一。作者没有说明改动原因，时间上紧随上述讨论。

### 5.4 本文发现的两处需要注意的地方

以下两点作者在帖子和原理图中都没有讨论，是本文根据器件数据手册推断的，**移植时应先核实**：

1. **AD5542A 的内阻会改变滤波器参数。** 它是无缓冲 R-2R 输出，内阻约 6.25 k 欧，与 R311 串联。结果是 f0 比设计值低约 18% 至 25%，群时延相应变大（见 5.2 节表格）。直流精度不受影响，因为运放同相端几乎不取电流。移植时应把 R311 减去约 6.25 k 欧，或在 DAC 后加缓冲。
2. **OPA189 的输入共模范围可能不够。** TI 数据手册给出的输入共模上限比正电源低约 2.5 V（典型值）。OPA189 用 +5 V 单电源时，同相端最高约 2.5 V；而 DAC 满量程是 3.3 V，**码值的上部约 24% 会使单位增益跟随器超出共模范围**。如果 OCXO 的实际工作点在 2.5 V 以下就不受影响——作者仿真时用的 2 V 偏置恰好在范围内，所以仿真不会暴露这个问题。本项目 v1.1 计划 HW-B 选的 OPA333、OPA192 都是输入轨到轨型，不存在此问题。

---

## 6. 控制环（推断）

@fig:ca_loop 图 9　数字锁相环的信号流（按帖子描述整理，作者未公开固件）

作者没有公开固件，下面是根据帖子能确定的部分：

| 环节 | 能确定的内容 | 来源 |
| --- | --- | --- |
| 相位比较 | GNSS 脉冲时刻与本地 OCXO 派生脉冲时刻之差，全部在 OCXO 相干时钟域内完成 | 架构本身 |
| 环路时间常数 | 作者按"大于 10 s"考虑，并认为 1PPS 驱动下小于 1 s 不现实 | time-nuts 讨论 |
| 滤波器时延 | 由数字环显式计入 | time-nuts 讨论 |
| 锯齿波修正 | 用 F9T 的 UBX-TIM-TP 中的 qErr。F9T 内部时钟据社区估计约 128 MHz，量化步长约 7.8 ns | 推断；时钟频率为 Marek 的估计，未见官方确认 |
| 差分授时 | 一台固定的 F9T 以时间模式、已测坐标运行，向移动端发送 RTCM 3 MSM7；移动端 F9T 用这些码与载波相位修正改善授时 | time-nuts 讨论 |
| IMU 用途 | v2 加了 IMU，作者未说明用途。推断用于 OCXO 加速度敏感度补偿或运动状态记录 | 推断 |
| 温度 | TMP117 放在 OCXO 罩内，可用于温度前馈 | 推断 |

### 6.1 社区指出的 ZED-F9T 风险

这些风险直接影响移动场景，作者表示要靠原型实测来回答：

- **定时指标只在固定位置模式下规定。** F9T 数据手册的 5 ns 绝对、2.5 ns 差分的脉冲精度只针对固定位置模式；移动时的运行极限是 4 g、500 m/s。作者承认移动中可能劣化，验证这一点正是做原型的目的之一。
- **能否用 RTK 修正有争议。** John Ackermann（N8UR）认为只有 F9P 能内部做 RTK，F9T 只能当基准站；作者引数据手册反驳：F9T 的差分授时功能本身就使用 RTCM 10403 中的码与载波相位修正，不需要做 RTK 定位。
- **位置误差不等于时间误差。** 作者用 F9P 双天线基线长度误差的统计（98% 小于 30 cm，约合 1 ns）来类比，Bob kb8tq 认为时间误差很可能比这个类比更差。目前双方都没有数据。
- **模块对温度、冲击、姿态敏感。** Thomas Abbott 实测：把裸模块翻转、升温 5 至 10 摄氏度、甚至用力敲桌子，脉冲都会跳几个 ns，10 至 20 s 后恢复。他判断是内部 TCXO 受扰后各个环路在重新收敛。**这对车载是直接威胁。**
- **qErr 偶发回绕。** Thomas Abbott、Marek、Bob 都观察到时间脉冲偏移修正偶尔出现约 7 ns 的"跳点"，2019 年的固件与 TIM 2.21 固件上都有人遇到，固件里必须做跳变检测。
- **不要开 SBAS。** 作者引用了 u-blox 的建议：授时应用应关闭 SBAS。

---

## 7. 输出驱动

@fig:ca_output 图 10　BUF602 输出级：源端 49.9 欧匹配，可驱动 50 欧或高阻负载

5 路输出电路完全相同：**BUF602 → 49.9 欧串联 → TVS → SMA**。2 路 10 MHz 来自 LMK 的 Y0，2 路稳定脉冲来自 MCU 的 PA9，1 路是 F9T 的 TP2 原始脉冲。

作者为什么用缓冲运放而不用 74 逻辑门，在同期的 RCB-F9T 转接板讨论中解释得很清楚：

| 理由 | 说明 |
| --- | --- |
| 上升沿 | BUF602 压摆率 8 V/ns，上升沿 < 0.5 ns；逻辑门的规格书都不给 1 ns 以下的上升时间 |
| 电源抑制 | BUF602 的 PSRR 在 1 MHz 以内 > 45 dB；逻辑门基本不标 |
| 源端匹配 | 运放输出阻抗低且确定，串 49.9 欧即成 50 欧源；逻辑门不标输出阻抗，驱动 50 欧要并联多个输出 |
| 可预期的噪声 | 附加噪声主要来自输入电压噪声 4.8 nV/根号Hz，约合 -153 dBm/Hz（50 欧），可以照数据手册算；逻辑门没有抖动指标 |
| 工程成本 | Bob kb8tq 认为分立方案更便宜；作者认为为每种信号分别验证一套方案的工程成本更高，手焊 SMA 的成本已经超过器件差价 |

作者还指出输出电平恰好符合 ITU G.703 的要求。在单独的 RCB-F9T 转接板上，-5 V 由 LM27761 电荷泵产生（驱动 5 路 50 欧负载的平均电流 < 100 mA）；主板上则由 J101 外供。

---

## 8. MCU 引脚分配

@fig:ca_pinmap 图 11　STM32G474RET6 在 v2 原理图中的引脚分配

几个值得注意的选择：

- **PF0 接 10 MHz（HSE 旁路）**，这是"MCU 与 OCXO 同源"的关键一根线。
- **PA9 输出稳定脉冲。** 它在原理图上标为 TIM2_CH3，但 PA9 同时是 HRTIM1_CHA2，可改用 HRTIM 获得约 184 ps 的边沿定位分辨率，这就是作者说的"约 200 ps 可调延迟"。
- **GNSS 脉冲进 PB11（TIM2_CH4）**，与输出脉冲共用 32 bit 的 TIM2，粗测与生成在同一个计数器上，没有跨定时器的同步问题。
- **PC13 至 PC15 一律不用。** v2 原理图特意注明：这三脚由电池域的 3 mA 电源开关供电，最高 2 MHz @ 30 pF，且不能输出电流。
- **TDC 的 INTB 加了 4.7 k 上拉**（v2 的 R231）。作者在 08-07 读 thinkfat 的帖子时发现 v1 漏了这个上拉——原理图注释"Only INT is open-drain"。

---

## 9. PCB 布局

@fig:ca_board 图 12　v2 版图的器件分区（按作者版图 PDF 量取，示意）

- 板框 100 x 100 mm（含 SMA 底座），可直接装进常见的铝制 PCB 外壳。
- **OCXO 在左上角，罩在 Hammond 1551P 塑料盒里**，TMP117 也在罩内，用于在无外壳使用时挡住气流。
- **RCB-F9T 用 2x4 排针叠插在右上方**，MCU 与 TDC7200 就在它下面紧挨着，GNSS 脉冲走线最短。
- 基准、DAC、有源滤波夹在 OCXO 罩与 MCU 之间；LMK1C1103 紧贴 OCXO 输出脚。
- 5 路 SMA 全部排在下沿，BUF602 驱动级一字排开在其上方。
- IMU 子板放在板中央（v2 新增）。

---

## 10. 两版原理图差异

| 项目 | v1（2022-08-05） | v2（各页 08-09 至 08-11） |
| --- | --- | --- |
| 有源低通 | 13 k / 10 k / 20 uF / 10 uF，约 1 Hz，反转 3 至 4 kHz | 8.2 k / 15 k / 2.2 uF / 1 uF，约 10 Hz，反转约 10 kHz |
| LMK 输出分配 | Y0 到 MCU，Y1 到 TDC，Y2 到输出 | Y0 到输出，Y1 经 R331 到 MCU，Y2 经 R332 到 TDC |
| TDC INTB | **无上拉**（作者事后发现） | R231 4.7 k 上拉 |
| TDC 供电 | 直接接 +3.3 V | 经 FB231 600 欧磁珠 |
| TDC ENABLE / INTB 引脚 | PC8 / PC9 | PC7 / PC6 |
| TMP117 | I2C4（PC6 / PC7），上拉 5 k | I2C3（PC8 / PC9），上拉 4.7 k |
| IMU | 无 | IIM-42652 子板，SPI3 + TIM4_CH1 时钟 |
| 指示灯 | 无 | PA0 至 PA2 接绿 / 黄 / 红 LED |
| SWD | 无保护 | 加 SMF05C ESD 阵列 |
| JP301（基准供电跳线） | 在磁珠与 ADR4533 输入之间 | 移到磁珠与 +5 V 之间 |
| 安装孔 | 4 个 | 8 个 |

---

## 11. 作者在讨论中回应过的其他问题

| 问题 | 提出者 | 作者回应 |
| --- | --- | --- |
| OCXO 的加速度敏感度 | Bob kb8tq | 原型先用一颗容易买到的普通 OCXO；下一版换最坏轴 < 0.2 ppb/g 的型号。他找到的最好约 0.05 ppb/g/轴，但很贵或体积大、不是贴片 |
| MCU 输出抖动 | WatchfulEye（在 SAMD51 上测到 PLL 抖动约 5 ns） | STM32G474 数据手册给出的 PLL 抖动约正负 25 ps，且 MCU 与 TDC 同源，预计影响可忽略。未实测 |
| 加气压传感器 | thinkfat | OCXO 是密封外壳，应对气压不敏感，暂不加 |
| 怎样测移动中的性能 | Theboel | 之前测 LC_XO 的做法：同一辆车里放多台 GPSDO，各用一根朝向不同的天线，行驶中直接比对各自输出。跨车辆比对需要视距无线链路，太复杂 |

---

## 12. 对本项目的借鉴

| Andrich 的做法 | 本项目现状 | 建议 | 对应 v1.1 计划 |
| --- | --- | --- | --- |
| 10 MHz 进 OSC_IN，MCU 与 OCXO 同源 | 10 MHz 只进 PA0，HSE 是独立晶振 | **照做**，单次分辨率从 100 ns 提到 5.9 ns，只加一条走线 | HW-H |
| TDC7200 的 STOP、CLOCK 直接接 10 MHz，靠周期折叠避开死区 | 无 TDC | 若将来上 TDC，可直接沿用这种无同步器接法，作者已实测验证 | HW-J |
| 粗测只需正负 50 ns，TIM2 与 TDC 组合 | 无 | 写 TIC 固件时按 4.1 节的公式组合，粗测不用精细标定 | M3 |
| DAC 后接有源二阶低通 + 无源 RC | PWM + 两级无源 RC，源阻抗 40 k 欧 | 借鉴结构，但**运放选输入轨到轨型**，并把 PWM 或 DAC 的源阻抗算进滤波器 | HW-B |
| 截止频率从 1 Hz 改到 10 Hz | 0.8 Hz | 本项目若在 16 bit PWM 上做抖动扩位，需要足够低的截止频率滤掉抖动；不做扩位时可参考 v2 适当提高 | HW-B |
| LMK1C1103 三路同相分配，无 74 逻辑 | 已有 LMK1C1102，但输入幅度与 VDD 有问题 | 先修正 v1.1 已列出的两个问题 | v1.1 第 2 节 |
| OCXO 罩盒挡气流 + 罩内测温 | 热设计尚未做 | 可直接借鉴，便携场景更需要 | HW-L |
| qErr 修正并做跳变检测 | 固件为空 | 实现 M4 时加入回绕检测 | M4 |

**不建议照搬的部分：**

- **供电方式。** 他的板子需要外部 +5 V、+3.3 V、-5 V 三路电源，没有任何板载稳压，OCXO 预热峰值 1.1 A @ 3.3 V。本项目是电池便携方案，必须自己做电源。
- **BUF602 + +/-5 V。** 需要负电源，功耗也不小。本项目若只需驱动高阻负载，没必要上。
- **把 ZED-F9T 当作移动授时一定可行。** 社区对此有实质性质疑（第 6.1 节），作者自己也没有数据。

---

## 13. 参考来源

```
Original post, time-nuts 2022-08-05 (v1 schematic STM32G4_GNSSDO.pdf attached)
  https://febo.com/pipermail/time-nuts_lists.febo.com/2022-August/106228.html
Author replies on time-nuts (F9T specs, differential timing, LPF group delay,
  0.05 ppb/g OCXO, F9P baseline error, updated schematic)
  https://febo.com/pipermail/time-nuts_lists.febo.com/2022-August/106235.html
  https://febo.com/pipermail/time-nuts_lists.febo.com/2022-August/106246.html
  https://febo.com/pipermail/time-nuts_lists.febo.com/2022-August/106249.html
  https://febo.com/pipermail/time-nuts_lists.febo.com/2022-August/106250.html
  https://febo.com/pipermail/time-nuts_lists.febo.com/2022-August/106265.html
  https://febo.com/pipermail/time-nuts_lists.febo.com/2022-August/106277.html
  https://febo.com/pipermail/time-nuts_lists.febo.com/2022-August/106290.html
Community feedback on time-nuts (Bob kb8tq, John Ackermann, Thomas Abbott, Marek)
  https://febo.com/pipermail/time-nuts_lists.febo.com/2022-August/106236.html
  https://febo.com/pipermail/time-nuts_lists.febo.com/2022-August/106237.html
  https://febo.com/pipermail/time-nuts_lists.febo.com/2022-August/106257.html
  https://febo.com/pipermail/time-nuts_lists.febo.com/2022-August/106267.html
  https://febo.com/pipermail/time-nuts_lists.febo.com/2022-August/106311.html
  https://febo.com/pipermail/time-nuts_lists.febo.com/2022-August/106325.html
  https://febo.com/pipermail/time-nuts_lists.febo.com/2022-August/106329.html
EEVblog thread (v2 schematic + layout, TDC7200 dead-time test, GPIO speed test)
  https://www.eevblog.com/forum/projects/gpsdognssdo-stm32g4-u-blox-zed-f9t-tdc7200/
  https://www.eevblog.com/forum/projects/gpsdognssdo-stm32g4-u-blox-zed-f9t-tdc7200/25/
RCB-F9T adapter board thread (why BUF602, LM27761 negative rail, G.703 levels)
  https://febo.com/pipermail/time-nuts_lists.febo.com/2022-August/106347.html
  https://febo.com/pipermail/time-nuts_lists.febo.com/2022-August/106375.html
  https://febo.com/pipermail/time-nuts_lists.febo.com/2022-August/106387.html
thinkfat: DIY GPSDO with STM32 + TDC7200 (the design that inspired this one)
  https://www.eevblog.com/forum/projects/diy-gpsdo-project-w-stm32-tdc7200/
Part data used in this document
  OPA189 datasheet (input common-mode headroom)
    https://www.ti.com/product/OPA189
  AD5542A output impedance (CN-0169)
    https://www.analog.com/CN0169
  STM32G474 pin map: PA9 = HRTIM1_CHA2
    https://docs.embassy.dev/embassy-stm32/git/stm32g474re/hrtim/
    trait.HRTimerPin.html
```

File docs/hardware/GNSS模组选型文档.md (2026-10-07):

# GNSS 模组选型文档

> **数据来源声明。** 本文第 2 节的**板级现状**（焊盘尺寸、引脚使用、网络连接、外围元件值）由本仓库 `hardware/schematic/v1.0` 的工程文件解析得出，并经 `kicad-cli` 导出网表核对，可直接采信。第 3 节之后的**模组参数**来自厂商公开资料与公开技术讨论，已在第 10.3 节列出逐条来源；凡标注"须核对 datasheet"的条目请视为待验证项。价格与库存未经核实，下单前请自行复核。

---

## 1. 结论摘要

| 项目 | 结论 |
| --- | --- |
| **最重要的发现** | 本板 GNSS 焊盘是 **12.20 x 16.30 mm / 24 pad**，与 **u-blox NEO 封装（12.2 x 16.0 mm，24 pin LCC）尺寸一致**，且关键四个引脚（3 = 1PPS、10 = GND、11 = RF_IN、23 = VCC）与 NEO-M8T 公开资料完全对应 |
| **由此得到的首选** | **u-blox NEO-F10T**（L1+L5 双频定时模组）或 **NEO-M8T**（单频定时模组），**很可能不用改焊盘就能直接替换**现有的 SKG123N。这是本次选型最大的收获 |
| 对"越小越好"的回答 | 最小的是 **u-blox MIA-M10Q，4.5 x 4.5 mm SiP**，只占 20 mm2 板面积且不需外围元件。但它是**导航级**模组，1PPS 只有 30 ns RMS，**不适合做 GPSDO 的时间基准** |
| 尺寸不是瓶颈的原因 | 定时级和导航级的封装尺寸差别很小。10.1 x 9.7 mm 这一档里既有导航级的 ATGM336H、LC76G，也有定时级的 PX1100T。**同样大小，性能差 6 倍** |
| 真正的决定性指标 | 一是**有没有定时模式**（position hold / stationary timing），二是**有没有锯齿波（量化误差）修正消息**。详见第 3 节 |
| 当前方案的短板 | SKG123N 是 L1+L5 **导航级**模组，没有定时模式，1PPS 抖动受位置解算噪声污染 |

### 1.1 三条路线

| 路线 | 选型 | 尺寸 | 1PPS 精度 | 改板量 | 适用 |
| --- | --- | --- | --- | --- | --- |
| **路线 A** 推荐 | u-blox NEO-F10T | 12.2 x 16.0 mm | ns 级，L1+L5 双频 | **可能为零**，待脚位核对 | 追求最佳 GPSDO 性能且想少改板 |
| **路线 B** 性价比 | SkyTraq PX1100T | 10.1 x 9.7 mm | 5 ns (1 sigma) | 需重画焊盘 | 既要定时级又要省面积，且接受重画 |
| **路线 C** 极小 | u-blox MIA-M10Q | 4.5 x 4.5 mm | 30 ns RMS | 需重画焊盘 | 只在尺寸压倒一切、放弃 GPSDO 精度目标时选 |

---

## 2. 本板 GNSS 现状（实测自 v1.0 工程文件）

@fig:gnss_chain 图 1　本板 GNSS 的三条链路（连接关系取自 kicad-cli 导出的网表）

### 2.1 焊盘与脚位

PCB 中 GNSS 模组位号 `U3`，封装 `Counter:SKG123N`，丝印范围 **12.20 x 16.30 mm**，**24 个焊盘**。

这个尺寸和引脚数与 u-blox NEO 封装一致。把本板实际连接的引脚与 NEO-M8T 的公开引脚资料并排对比：

| 引脚 | 本板 SKG123N 的引脚名 | 本板实际连接 | u-blox NEO-M8T | 是否一致 |
| --- | --- | --- | --- | --- |
| 3 | PPS | 经 R1 100 欧到 MCU | **TIMEPULSE** | **一致** |
| 9 | ANT_POWER | 经 L1 33nH 到 VANT | 待核对 | 待核对 |
| 10 | GND | 地 | **GND** | **一致** |
| 11 | RF_IN | IPEX 座 U4 的信号脚 | **RF_IN** | **一致** |
| 12 | GND | 地 | 待核对 | 待核对 |
| 13 | GND | 地 | 待核对 | 待核对 |
| 20 | UART0_TX | 经 R3 33 欧到 MCU | 待核对 | 待核对 |
| 21 | UART0_RX | 经 R2 33 欧到 MCU | 待核对 | 待核对 |
| 22 | V_BCKP | C5 1uF 与 R7 470 欧到 3.3V | 待核对 | 待核对 |
| 23 | VCC | 3.3V | **VCC** | **一致** |
| 24 | GND | 地 | 待核对 | 待核对 |

> **关键四脚（供电、地、射频输入、1PPS）全部对应。** 这四个脚决定了模组能不能上电工作并输出 1PPS，因此 NEO 系列换上本板焊盘的可行性很高。但**必须拿到 NEO-F10T 或 NEO-M8T 的正式 datasheet，把 24 个引脚逐一核对完**再下单——尤其是 UART 的 20 / 21 两脚方向、V_BCKP 位置、以及天线供电引脚是否存在。这件事没做完之前，上表的"一致"只覆盖 4 个脚，不是 24 个。

### 2.2 当前未使用的引脚

本板有 11 个引脚悬空：1 (RTC_EINT)、2 / 5 / 6 (NC)、4 (SPEED)、7 (EINT_IN)、8 (CHIP_EN)、14 (EINT_OUT)、15 (FWD)、16 / 17 (UART2)、18 / 19 (TXD1/SDA、RXD1/SCL)。

换料时这些脚的功能会变，**悬空不等于安全**：如果新模组在同一位置是使能脚、复位脚或配置脚，悬空会导致模组不工作或行为随机。

### 2.3 顺带发现的三个待复核项

这些属于既有设计，本文只记录，不做改动。

1. **CHIP_EN (pin 8) 悬空。** 如果 SKG123N 内部没有上拉，模组可能根本不使能。请确认 datasheet 是否标明内部上拉；换成 NEO 系列后该位置的功能也会变。
2. **V_BCKP (pin 22) 没有备电。** 当前只经 R7 470 欧从 3.3V 取电，配 C5 1uF。整机断电后星历与 RTC 全部丢失，**每次开机都是冷启动**（典型 30 秒以上才有 1PPS），而不是热启动（几秒）。对需要快速进入锁定的 GPSDO 来说，建议补一颗超级电容或纽扣电池。另外 470 欧串联会在 V_BCKP 有电流需求时产生压降，需核对该引脚的电流规格。
3. **1PPS 串 R1 100 欧。** 100 欧配 MCU 引脚电容会拖慢边沿。**1PPS 的边沿陡度直接影响时间间隔测量的分辨率**，这条路径上建议用 22 到 33 欧，和时钟信号同等对待。

---

## 3. GPSDO 对 GNSS 模组的真正要求

### 3.1 定时模式 vs 导航模式（最重要）

| | 导航模式 | 定时模式 |
| --- | --- | --- |
| 解算内容 | 同时解 3 个位置分量加 1 个时间分量 | 位置被钉死，**只解时间** |
| 后果 | 位置解的噪声通过几何关系耦合进时间解，1PPS 抖动被显著放大 | 时间解的噪声源只剩卫星钟与路径误差 |
| 最少可见卫星 | 4 颗 | **1 颗即可**（位置已知） |
| 典型 1PPS 精度 | 几十 ns 到几百 ns | 5 到 20 ns |
| 实现方式 | 默认 | 先 self-survey 自测位置数小时取平均，再切 position hold |

**这是导航级与定时级模组的分水岭，比尺寸、比星座数量、比灵敏度都重要。** 一个 4.5 mm 的导航模组和一个 10 mm 的定时模组，后者给 GPSDO 带来的性能提升是前者省下的面积完全换不来的。

### 3.2 锯齿波（量化误差）修正

模组内部用自己的时钟（典型几十 MHz）去对齐 1PPS 边沿，因此边沿只能落在内部时钟的整数周期上，产生周期性的三角波误差，画出来像锯齿，这就是量化误差 qErr。

| 环节 | 说明 |
| --- | --- |
| 误差幅度 | 取决于模组内部时钟频率，典型十几到几十 ns 峰峰值 |
| 修正原理 | 模组在**下一个脉冲到来之前**把该脉冲的量化误差播报出来，固件把这个值从时间间隔测量结果里减掉 |
| u-blox 的实现 | **UBX-TIM-TP** 消息的 qErr 字段，单位皮秒，仅在 1 Hz 脉冲时有效 |
| SkyTraq 的实现 | **PSTI,00** 消息，PX1100T 支持 |
| 为什么关键 | 不做修正，1PPS 的有效抖动就是锯齿波的幅度；做了修正可以压到 ns 以下。**这是 GPSDO 能否进到 1e-12 量级的分界线** |

> **这一项要作为硬性筛选条件。** 没有量化误差输出的模组（多数导航级模组，包括部分 Quectel 型号——其用户论坛上仍有"是否有 PPS 量化误差消息"的提问）用在 GPSDO 上，固件再好也补不回来。

### 3.3 单频与 L1+L5 双频

电离层延迟是单频 GNSS 定时的最大系统误差源，有明显的日变规律，会在 GPSDO 的输出上留下周期性的频率起伏。双频（L1+L5 / E1+E5a / B1+B2a）可以直接算出电离层延迟并消掉，**不需要外部差分改正服务**。

本板现有的 SKG123N 已经是 L1+L5 双频，但是导航级；NEO-F10T 则是**双频加定时级**，两个优点兼得。

### 3.4 指标权重

| 参数 | 对 GPSDO 的作用 | 权重 |
| --- | --- | --- |
| 定时模式 (position hold) | 决定 1PPS 抖动的量级，见 3.1 | 最高 |
| 量化误差输出 | 决定固件能否把抖动再压一个数量级，见 3.2 | 最高 |
| 1PPS 时间精度 ns RMS | 直接决定环路参考的质量 | 最高 |
| L1+L5 双频 | 消电离层，去掉日变系统误差 | 高 |
| 守时 / T-RAIM 完好性 | 剔除异常卫星，避免坏星把环路带偏 | 中 |
| 跟踪灵敏度 | 室内或遮挡环境能否维持锁定 | 中 |
| 功耗 | 本板是电池供电，但模组功耗远小于 OCXO，不是瓶颈 | 低 |
| **封装尺寸** | 见第 4 节，边际收益有限 | **低** |

---

## 4. 尺寸对比

@fig:gnss_size 图 2　主流 GNSS 模组本体尺寸等比对比

### 4.1 为什么"越小越好"在这里收益有限

把模组从 12.2 x 16 mm（195 mm2）换成 4.5 x 4.5 mm（20 mm2）看似省了 175 mm2，但 GNSS 这一块的实际占板面积还包括：

| 外围 | 本板实际情况 | 面积量级 |
| --- | --- | --- |
| IPEX 天线座 | U4，丝印 2.7 x 2.7 mm | 小，但周边需要净空 |
| 有源天线偏置 | L1 33nH 加 VANT 网络 | 十几 mm2 |
| 备电 | C5 1uF，**建议再加超级电容** | 补了备电后反而增加 |
| 供电去耦 | C22 / C23 / C24 / C26 / C27 等多颗 | 十几 mm2 |
| 射频走线净空 | RF_IN 到天线座要求 50 欧阻抗与地平面完整 | 不可压缩 |

**结论：模组本体越做越小以后，外围和射频净空成了面积的主导项。** 为了省这 175 mm2 而把 1PPS 精度从 ns 级退到 30 ns 级，对一个以频率准确度为核心卖点的产品是不划算的交换。真要省面积，先优化天线座位置与偏置网络布局。

---

## 5. 候选模组

### 5.1 定时级（GPSDO 应该从这里选）

| 型号 | 尺寸 mm | 1PPS 精度 | 频点 | 量化误差消息 | 要点 |
| --- | --- | --- | --- | --- | --- |
| **u-blox NEO-F10T** | 12.2 x 16.0 | ns 级 | L1+L5 双频 | UBX-TIM-TP（须核对该型号是否保留） | 双频自带消电离层；带 secure boot、配置锁、T-RAIM 完好性；2.7 到 3.6 V 单电源，3.0 V 下约 19 mA |
| **u-blox NEO-M8T** | 12.2 x 16.0 | 优于 20 ns | 单频 | **UBX-TIM-TP qErr，皮秒单位** | 时间圈经典型号，开源 GPSDO 代码与实测数据最多，资料最好找 |
| **SkyTraq PX1100T** | **10.1 x 9.7** | **5 ns (1 sigma)** | 单频四星座 | **PSTI,00** | 尺寸与导航模组同级却是定时级；1 颗星可见即可输出 1PPS；冷启动灵敏度 -148 dBm，跟踪 -165 dBm；230 通道；castellated 边缘封装好焊 |
| u-blox ZED-F9T | 17 x 22 | 约 5 ns | 双频 | 支持 | 性能天花板。公开实测：1 km 基线上两台之间 1PPS 标准差约 0.7 ns，滤波后可到约 200 ps。但体积最大、价格最高 |

### 5.2 导航级小封装（尺寸最优，不适合做 GPSDO 基准）

| 型号 | 尺寸 mm | 1PPS 精度 | 要点 |
| --- | --- | --- | --- |
| **u-blox MIA-M10Q** | **4.5 x 4.5 SiP** | 30 ns RMS，99% 时优于 60 ns | 目前最小，仅占 20 mm2 且**不需外部元件**；连续跟踪小于 25 mW；脉冲频率 0.25 Hz 到 10 MHz 可配 |
| Quectel LC76G | 10.1 x 9.7 x 2.4 | 30 ns | GPS / BDS / GLONASS / Galileo / QZSS |
| Quectel L76K | 10.1 x 9.7 x 2.0 | 30 ns | 比 LC76G 薄，星座少 Galileo |
| 中科微 ATGM336H 系列 | 10.1 x 9.7 | 标称定时优于 10 ns（**此指标未找到权威出处，须核对完整 datasheet**） | 立创有货、国产最便宜，有 -6N / -7N / -F8N 多版本 |
| u-blox MAX-M10S | 10.1 x 9.7 | 未查证 | 连续跟踪小于 25 mW，超低功耗 |
| SKYLAB SKG123N | 12.2 x 16.3 焊盘 | 未查证 | **本板当前方案**，GPS / BDS / GLONASS / Galileo / QZSS，L1+L5 双频 |

### 5.3 两个封装家族

市面上的小型 GNSS 模组实际上收敛到两个事实标准，都是被 u-blox 的封装带出来的：

| 家族 | 尺寸 | 成员 |
| --- | --- | --- |
| **MAX 家族** | 10.1 x 9.7 mm | u-blox MAX-M10S、SkyTraq PX1100T、Quectel LC76G 与 L76K、中科微 ATGM336H |
| **NEO 家族** | 12.2 x 16.0 mm，24 pin LCC | u-blox NEO-M8T 与 NEO-F10T、SKYLAB SKG123（**本板**） |

实用价值：**同一家族内可以共用一套焊盘**，便宜的型号打样调试、贵的型号定型量产，板子不用改。但**尺寸相同绝不等于脚位兼容**，必须逐脚核对各家 datasheet 的引脚定义表。

---

## 6. 推荐结论

### 6.1 首选：u-blox NEO-F10T

> 理由是三条优点叠在一起，而代价可能为零。

1. **定时级**，有 position hold，1PPS 进入 ns 级；
2. **L1+L5 双频**，消掉电离层日变误差，这一点与本板现有 SKG123N 持平而不退步；
3. **封装属于 NEO 家族，与本板现有焊盘尺寸一致**，关键四脚已核对对应，**改板量可能为零**；
4. 附带 T-RAIM 完好性与安全启动，可以剔除异常卫星，避免坏星把环路带偏。

前提是第 7 节的脚位核对全部通过。

### 6.2 备选

- **u-blox NEO-M8T**：同样是 NEO 家族，同样可能免改板。单频，所以要接受电离层日变误差；但**公开资料与开源实现最多**，qErr 的用法有大量现成代码可参考，是风险最低的工程选择。适合先用它把固件的锯齿波修正逻辑跑通，再升级到 F10T。
- **SkyTraq PX1100T**：如果决定重画这块区域的焊盘，它是性价比最优解——10.1 x 9.7 mm 拿到 5 ns，支持 PSTI,00 锯齿波修正，castellated 封装好焊。代价是焊盘、布局、固件的 NMEA 解析都要改。

### 6.3 不推荐

- **MIA-M10Q 等导航级模组做 GPSDO 基准**：30 ns RMS 的 1PPS 当环路参考，意味着环路时间常数必须拉得很长才能把抖动平均掉，而 OCXO 的优势恰恰在中短时间尺度。为省面积牺牲这个不划算。
- **没有量化误差输出的模组**：见 3.2，固件补不回来。
- **ZED-F9T 用在本板**：17 x 22 mm 与便携定位冲突，留给将来的台式版本。

---

## 7. 换料前必须做完的核对清单

| 序号 | 要核对的事 | 怎么做 | 不通过的后果 |
| --- | --- | --- | --- |
| 1 | 24 个引脚逐一比对 | 把 NEO-F10T 或 NEO-M8T datasheet 的引脚表与本文 2.1、2.2 两节逐行对照 | 错接电源或射频会直接损坏模组 |
| 2 | 焊盘几何 | 核对 datasheet 的 land pattern 与本板 12.20 x 16.30 mm / 24 pad 的间距、宽度 | 焊不上或虚焊 |
| 3 | 天线供电引脚 | 确认新模组是否有 ANT_POWER 类引脚，位置是否仍是 pin 9；若没有，L1 与 VANT 网络要改成外部偏置 | 有源天线不工作 |
| 4 | 悬空脚的新功能 | 本板悬空的 11 个脚在新模组上是什么功能，是否需要上下拉或固定电平 | 模组不使能或行为随机 |
| 5 | 供电电压与电流 | NEO-F10T 为 2.7 到 3.6 V，3.0 V 下约 19 mA；核对本板 3.3V 轨余量 | 一般没问题，确认即可 |
| 6 | 量化误差消息 | 确认该型号固件版本支持 UBX-TIM-TP 且 qErr 字段有效（**仅 1 Hz 脉冲时有效**） | 拿不到锯齿波修正，精度上不去 |
| 7 | 定时模式配置 | 确认支持 self-survey 与 position hold，以及如何通过 UBX 或 NMEA 指令切换 | 退化成导航级精度 |
| 8 | 固件改动量 | NEO 系列用 UBX 二进制协议，本板现有固件是 NMEA 解析，需要新增 UBX 解析 | 低估工作量 |

---

## 8. 验收与实测方法

拿到模组后，1PPS 的真实质量必须实测，datasheet 的数字只是参考。

| 步 | 操作 | 判据 |
| --- | --- | --- |
| 1 | 冷启动到首次 1PPS 的时间 | 记录。无备电时典型 30 秒以上 |
| 2 | 切定时模式 | 先 self-survey 数小时取位置平均，再切 position hold，确认模组回报已进入定时模式 |
| 3 | 1PPS 抖动（不修正） | 用本板 MCU 的 32 位定时器把 1PPS 与 OCXO 的 10 MHz 做时间间隔测量，采样不少于 10000 点，算标准差 |
| 4 | 1PPS 抖动（修正后） | 同上，但每个脉冲减掉 qErr 或 PSTI,00 给出的量化误差，**标准差应明显下降**。下降不明显说明修正逻辑有错 |
| 5 | 锯齿波形态确认 | 把未修正的时间间隔序列画出来，应能看到明显的三角波，周期与模组内部时钟有关 |
| 6 | 长期稳定性 | 连续记录 24 小时以上，观察是否有日变起伏。单频模组会有，双频应显著减弱 |
| 7 | 遮挡与卫星数 | 记录可见卫星数与 1PPS 抖动的相关性，定时模式下应对卫星数不敏感 |
| 8 | 天线对比 | 换不同天线与安装位置重测，天线的影响常常大于模组型号的差别 |

> **第 4 步是整个验收的核心。** 它同时验证了模组确实在播报量化误差、固件的符号与单位换算正确（u-blox 的 qErr 是皮秒，要除以 1000 换成纳秒）、以及时间间隔测量链路本身是可信的。

---

## 9. 采购渠道

| 渠道 | 适合买 | 备注 |
| --- | --- | --- |
| 立创商城 | ATGM336H、部分 u-blox 型号 | 中文规格书、现货标识，国产模组最便宜 |
| 贸泽 Mouser、得捷 DigiKey | NEO-F10T、NEO-M8T、ZED-F9T、MIA-M10Q | datasheet 齐全，正品渠道，价格最高 |
| SkyTraq 代理或淘宝 | PX1100T | 注意确认是 T 结尾的定时版本，不要买成 S 结尾的导航版本 |
| 淘宝 | 各类模组与开发板 | **务必问清是定时版还是导航版**，两者型号常只差一个字母 |

> **最容易买错的一点：** SkyTraq 的 PX1100**T** 是定时版，PX1100**S** 是导航版；u-blox 的 NEO-M8**T** 是定时版，NEO-M8**N** 是导航版。**一个字母的差别就是本文第 3 节的全部内容。**

---

## 10. 附录

### 10.1 术语

| 术语 | 含义 |
| --- | --- |
| 1PPS | 每秒一个脉冲，上升沿对齐 UTC 整秒，是 GPSDO 的时间参考输入 |
| 定时模式 | position hold / stationary timing，位置已知后只解时间，大幅降低 1PPS 抖动 |
| self-survey | 模组长时间自测位置并取平均，为切入定时模式做准备 |
| qErr / 量化误差 | 1PPS 边沿被模组内部时钟量化产生的误差，画出来呈锯齿状 |
| UBX-TIM-TP | u-blox 的私有二进制消息，播报下一个脉冲的时间信息与量化误差 |
| PSTI,00 | SkyTraq 的 NMEA 扩展消息，作用同上 |
| T-RAIM | 定时接收机自主完好性监测，剔除异常卫星 |
| LCC | 无引线芯片载体封装，NEO 家族用的 24 脚形式 |

### 10.2 关键数值汇总

| 项目 | 数值 |
| --- | --- |
| 本板 GNSS 焊盘 | 12.20 x 16.30 mm，24 pad，封装名 Counter:SKG123N |
| 已核对一致的引脚 | 3 = 1PPS、10 = GND、11 = RF_IN、23 = VCC |
| 本板悬空引脚数 | 11 个 |
| 1PPS 串联电阻 | R1 = 100 欧（建议复核，宜改 22 到 33 欧） |
| 天线偏置 | ANT_POWER pin 9 经 L1 33nH 到 VANT |
| 备电 | V_BCKP pin 22 经 R7 470 欧从 3.3V 取电，C5 1uF，**无电池或超容** |
| 定时级 1PPS 目标 | 5 到 20 ns，修正锯齿波后进入 ns 以下 |
| 导航级 1PPS 实际 | 约 30 ns RMS |
| 最小模组 | MIA-M10Q，4.5 x 4.5 mm，20 mm2 |

### 10.3 参考来源

```
u-blox MIA-M10Q datasheet (立创镜像)
  https://wmsc.lcsc.com/wmsc/upload/file/pdf/v2/lcsc/
  2312271341_U-BLOX-MIA-M10Q-00B_C6990279.pdf
u-blox MIA-M10 系列产品页
  https://www.u-blox.com/en/product/mia-m10-series
u-blox NEO-F10T datasheet
  https://content.u-blox.com/sites/default/files/documents/
  NEO-F10T_DataSheet_UBX-22022576.pdf
u-blox ZED-F9T datasheet
  https://cdn.sparkfun.com/assets/7/a/e/d/3/ZED-F9T-00B_DataSheet_UBX-18053713.pdf
u-blox MAX-M10S datasheet
  https://cdn.sparkfun.com/assets/7/5/9/a/a/MAX-M10S_DataSheet_UBX-20035208.pdf
u-blox 定时应用笔记 (GPS.G6-X-11007)
  https://mikrocontroller.net/attachment/546526/Timing_AppNote__GPS.G6-X-11007_.pdf
SkyTraq PX1100T datasheet
  https://macrogroup.ru/upload/iblock/bd4/
  cj2twawy50db4fphjo8zj555jogc5ob3/PX1100T.pdf
time-nuts 邮件列表：SkyTraq PX1100T 实测讨论
  https://febo.com/pipermail/time-nuts_lists.febo.com/2021-December/104490.html
time-nuts 邮件列表：锯齿波修正的实现
  https://febo.com/pipermail/time-nuts_lists.febo.com/2022-December/107093.html
N8UR：GPS 接收机定时性能评测 (TAPR DCC 2020)
  https://hamsci.org/sites/default/files/publications/
  2020_TAPR_DCC/N8UR_GPS_Evaluation_August2020.pdf
Quectel LC76G 规格书
  https://quectel.com/content/uploads/2024/03/
  Quectel_LC76G_Series_GNSS_Specification_V1.1-1-1.pdf
Quectel L76K 规格书 (中文)
  https://www.quectel.com.cn/wp-content/uploads/2021/03/
中科微 ATGM336H 系列用户手册 (立创商城)
  https://atta.szlcsc.com/upload/public/pdf/source/20230620/
  6B4557DC589EF72A5E0A00DF964910CB.pdf
SKYLAB SKG123 产品资料
  https://www.yunzhan365.com/basic/62707938.html
NEO-M8T 引脚资料 (DigiKey / flux.ai 条目)
  https://www.flux.ai/vasy_skral/neo-m8t-0.md
```

### 10.4 待办

1. 拿到 NEO-F10T 与 NEO-M8T 的正式 datasheet，完成第 7 节清单第 1 到 4 项的 24 脚逐一核对，确认能否免改板替换。
2. 核对 SKG123N 的 CHIP_EN (pin 8) 是否有内部上拉。
3. 评估给 V_BCKP 补超级电容或纽扣电池的方案，把冷启动改成热启动。
4. 复核 1PPS 路径上 R1 = 100 欧是否应改为 22 到 33 欧。
5. 固件侧预研 UBX 二进制协议解析与 UBX-TIM-TP 的 qErr 应用，这是换 u-blox 模组的主要软件工作量。
6. 定型后把模组型号、定时模式配置指令、qErr 单位换算写入固件常量与 `hardware/bom/`。

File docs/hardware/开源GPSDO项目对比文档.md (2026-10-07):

# 开源 GPSDO 项目对比文档

> **数据来源与可信度声明。** 本文所有项目信息来自各项目的仓库、作者在 time-nuts 邮件列表与 EEVblog 论坛的公开陈述，逐条来源列在第 9 节。**不同项目的性能数据性质差别很大**：有的是第三方实测、有的是作者自述、有的只是设计目标，本文在每个条目上标注了数据性质，请按此判断可信度。各项目的 star 数与状态为查询时的快照。第 3 节的 ADEV 曲线是**典型量级示意，不是任何具体项目的实测曲线**。

---

## 1. 结论摘要

| 问题 | 回答 |
| --- | --- |
| 开源 GPSDO 一共有多少 | 真正完整的硬件加固件开源**设计**约十个，另有二十余个 GitHub 仓库是周边工具（协议解析、分配放大器、监控软件） |
| **最值得参考的一个** | **Carsten Andrich 的 STM32G4 + ZED-F9T + TDC7200 方案**。它和本项目**用同一系列的 MCU**，架构是目前公开方案里最先进的，设计思路可以直接借鉴 |
| **社区最成熟、资料最多** | **Lars Walenius GPSDO**。2011 年至今的事实基准，EEVblog 主帖阅读量三十余万，有大量第三方复现与实测数据 |
| **最容易上手、成本最低** | **AndrewBCN/STM32-GPSDO**，不到 30 欧元，GPL-3.0，106 star，开源 GPSDO 里 star 最高 |
| **时间分辨率最高** | 用 TI **TDC7200** 的那一类，**55 到 60 ps**，比 Lars 的 1 ns 方案高约 20 倍，比本项目当前的定时器捕获方案高约 100 倍 |
| **精度最高（有实测依据）** | Lars 方案与铷钟 GPSDO 对比测试中，在 tau = 1000 s 处约 **2e-12**。这是本次调研中找到的**有公开实测支撑**的最好数字 |
| 一个重要的认识 | **时间分辨率高不直接等于输出精度高。** 分辨率只决定短 tau 段，输出 ADEV 由 OCXO、环路、GNSS 共同决定，见第 3 节 |

### 1.1 本项目的定位

本项目 v1.0 当前是 **STM32G431 加 SKG123N 加 PWM 控压 OCXO**。硬件上 OCXO 的 10 MHz 进 PA0、1PPS 进 PA1，**要测 OCXO 就必须拿 10 MHz 当计数时基，因此单次分辨率是 100 ns**，靠相位连续累积换取等效分辨率。只有改板把 10 MHz 同时送进 OSC_IN，让 MCU 以 OCXO 为系统时钟，才能拿到 1/170 MHz = 5.9 ns。

对照下来，**本项目的架构与 AndrewBCN/STM32-GPSDO 同级**（都是 MCU 定时器捕获加 Arduino 级固件复杂度），而**与 Carsten Andrich 的方案差了一个 TDC7200 加一套锯齿波修正**。这两处正是最值得补的短板。

---

## 2. 项目全景

### 2.1 第一梯队：TDC 架构（分辨率最高）

| 项目 | 架构 | 分辨率 | 数据性质 | 要点 |
| --- | --- | --- | --- | --- |
| **Carsten Andrich 方案** | STM32G4 + u-blox ZED-F9T + TDC7200 + 低 g 敏感 OCXO | TDC7200 约 50 ps | **设计目标**，未见完整实测 | 目标是在 10 km 半径内移动时相对精度优于 10 ns；避免对 OCXO 输出做数字分频；用低抖动时钟 IC；**在调谐 DAC 之后加 1 Hz 有源低通，以获得优于 16 bit 的等效调谐分辨率**；成本目标单台 500 欧元以内（不含 OCXO）。原理图 PDF 公开，是否完整开源未确认 |
| **thinkfat (Matthias Welwarsky) 方案** | STM32 + TDC7200 | 单次 55 ps，长观测区间约 60 ps（TDC7200 极限） | **作者自述加论坛实测** | 受 Lars 方案启发但走了更精密的路线，用专用 TDC 取代 4046 加 ADC。EEVblog 长帖有完整开发记录，是否发布完整设计文件未确认 |
| **TAPR TICC**（John Ackermann N8UR） | Arduino Mega 2560 + 双路 TDC7200 | 单次小于 60 ps，抖动小于 100 ps | **产品化指标** | **严格说这不是 GPSDO 而是时间间隔计数器**，但它是构建与评测高精度 GPSDO 的关键工具：双通道，约 100 次每秒，无需校准，与 TimeLab 实时兼容，需外部 10 MHz 参考。**BSD 许可，完整开源**，TAPR 有成品卖 |

### 2.2 第二梯队：经典 1 ns 级模拟 TIC（最成熟）

| 项目 | 架构 | 分辨率 | 数据性质 | 要点 |
| --- | --- | --- | --- | --- |
| **Lars Walenius GPSDO** | Arduino + HC390 + HC4046 + 一个二极管加无源件 | **约 1 ns**，量程 1 us | **实测，有第三方复现** | 2011 年的设计，**只用两片 HCMOS 逻辑加一个二极管**就做到 1 ns：HC390 给 HC4046 送 1 MHz，相位比较器输出经二极管和 RC 网络直接进 Arduino 的 10 bit ADC。实测 ADEV：配 M12 接收机的 position hold 模式，1 s 处 2e-8，1000 s 处 2e-11；**与 LPRO 铷钟 GPSDO 对比测试中 tau = 1000 s 处约 2e-12**；用作纯时间间隔计数器并在 EEPROM 里写入线性化参数后，1 s 处可到 8e-10 |
| **jimharman/Arduino-GPSDO** | 基于 Lars 的硬件与代码 | 同上 | 衍生项目 | Lars 方案的整理与再发布版本，适合想直接照着做的人 |

> **为什么 Lars 方案值得单独研究。** 它用极少的元件达到了 1 ns，核心技巧是**把相位比较器的输出变成一个模拟电压再用 ADC 读**，而不是去数时钟周期。对于不想加 TDC 芯片的设计，这是性价比最高的一条路——本项目如果不打算上 TDC7200，这个方案能把分辨率从 5.9 ns 提到 1 ns，成本只有两片逻辑加几个无源件。

### 2.3 第三梯队：低成本易复现

| 项目 | 架构 | 成本与性能 | 许可 | 要点 |
| --- | --- | --- | --- | --- |
| **AndrewBCN/STM32-GPSDO**（André Balsa） | STM32F411CEU6 Black Pill + u-blox Neo-M8 + 10 MHz OCXO | **低于 30 欧元**；**正负 1 ppb 开箱性能**（作者自述） | GPL-3.0 | **开源 GPSDO 里 star 最高（106）**。C++ / Arduino IDE + STM32duino；仓库含 docs、schematics、software；可选 OLED 显示温度 UTC 运行时间状态频率；带蓝牙接口与运行参数日志；5 V @1 A USB-C 供电。作者在 2022 年的 time-nuts 介绍帖中表示当时尚无 ADEV 图 |
| **ahhuhtal/gpsdo** | 驯服 **OSC5A2B02** OCXO | 未公开量化指标 | 见仓库 | 含源码与 PCB 设计文件。用的就是 OCXO 选型文档里提到的那颗经典廉价件，**和本项目的器件选择最接近**，PCB 可直接参考 |
| **YannickTurcotte/GPSDO-YT** | OCXO + u-blox NEO-M8N，**全 AVR 汇编** | 单周期精度（作者自述） | 见仓库 | 极简主义路线，所有定时逻辑与控制用汇编写到单周期精度。适合研究如何把控制环做到确定性时序 |
| **dfannin/gpsdo** | Arduino | 10 MHz / 1 MHz / 10 kHz 三路输出 | 见仓库 | 入门友好 |
| **xiedidan/gpsdo-alpha** | 面向音频与 HAM DIY | 原型级 | 见仓库 | 目标是让任何人在家能做出来 |
| **glenoverby/gpsdo** | GPSDO 控制器 | 未公开 | 见仓库 | 控制器方向 |
| **SomerledDesign/GPSDO** | 基于 Trimble Thunderbolt 模块 | 取决于 Thunderbolt | 见仓库 | 不是从零设计，是给成品 GPSDO 做控制与显示 |

### 2.4 周边工具（做 GPSDO 必然会用到）

| 名称 | 作用 | 说明 |
| --- | --- | --- |
| **TimeLab**（KE5FX John Miles） | **ADEV 绘图与分析的事实标准** | 免费但非开源。做 GPSDO 必装，TICC 可与它实时对接 |
| **Lady Heather** | GPSDO 监控与控制的经典软件 | GitHub 上有 LadyHeatherGPS 等维护分支 |
| **TAPR TICC** | 测量工具，见 2.1 | 评测自己做的 GPSDO 必须有比它更好的参考 |
| **cracl** | C++ 库，统一接口 u-blox 接收机、振荡器、原子钟、时间间隔计数器 | 做上位机软件时可省很多力 |
| **trueposition_gpsdo_usb_oled** | TruePosition GPSDO 控制器固件加隔离分配放大器 | 拆机 GPSDO 改造方向 |
| **10mhz_distributor** | 三路 10 MHz 分配放大器与低通滤波 | 针对 BG7TBL GPSDO 设计，可独立参考 |
| **esp32-gps-pps-ntp-server** | ESP32 的 GPS/PPS 驯服 NTP 服务器，带 Web 面板与 OTA | 如果目标是授时而非频标，这条路更省事 |

---

## 3. 精度到底由什么决定

@fig:gpsdo_adev 图 1　各类振荡器与 GPS 1PPS 的典型 ADEV，以及 GPSDO 输出的合成包络（典型量级示意）

### 3.1 读图的三个要点

1. **GPSDO 的输出不会比两条曲线中较低的那条更好。** 短 tau 段由振荡器决定（GPS 1PPS 在这里很差，2e-8 量级），长 tau 段由 GPS 决定（OCXO 在这里因老化与温漂而变差）。**GPSDO 的全部意义就是把两者各自的好处拼起来。**
2. **交越点的位置就是环路时间常数。** 设得太短，GPS 的短期噪声会灌进输出；设得太长，OCXO 的漂移来不及被修正。典型取 100 到 1000 s。这是 GPSDO 固件里最重要的一个参数。
3. **换更好的 OCXO 只改善交越点左边，换更好的 GNSS 只改善右边。** 这解释了一个常见困惑：为什么给廉价 GPSDO 换上高端 OCXO，长期指标却没变好——因为长期段本来就由 GPS 决定。

### 3.2 决定精度的四个环节，按影响排序

| 环节 | 影响哪一段 | 本项目现状 | 可改进空间 |
| --- | --- | --- | --- |
| **OCXO 质量** | 短 tau（交越点以左） | 待选型，见 OCXO 选型文档 | 普通 OCXO 1e-11 到高端 1e-12，差一个数量级 |
| **GNSS 1PPS 质量加锯齿波修正** | 长 tau（交越点以右） | SKG123N 导航级，**无锯齿波修正** | 换定时级模组加做 qErr 修正，可改善一个数量级。见 GNSS 选型文档 |
| **时间差测量分辨率** | 短 tau，以及环路能否稳定收敛 | 以 10 MHz 为时基，单次 100 ns | 改板送 OSC_IN 到 5.9 ns，用 Lars 模拟方案到 1 ns，加 TDC7200 到 55 ps |
| **环路设计与时间常数** | 交越点位置与形状 | 待实现 | 这是纯固件工作，零成本，但最需要实测调参 |

> **性价比排序很明确：先做锯齿波修正（纯固件，零硬件成本），再换定时级 GNSS 模组，再提升 TIC 分辨率，最后才是升级 OCXO。** 本项目当前最大的短板是第二项，因为完全没做。

---

## 4. 时间差测量架构对比

@fig:gpsdo_tic 图 2　开源 GPSDO 用过的三种时间差测量架构

@fig:gpsdo_res_bar 图 3　各项目的时间差测量分辨率，对数横轴（注意这不等于输出 ADEV）

### 4.1 三种架构怎么选

| 如果你的情况是 | 选 | 理由 |
| --- | --- | --- |
| 先把系统跑通，验证整条链路 | MCU 定时器捕获 | 零外部器件，本项目已经是这个方案，先用它把固件和环路做对。注意本项目当前单次分辨率是 100 ns 而非 5.9 ns，原因见 1.1 节 |
| 不想加芯片但要提升分辨率 | Lars 的模拟相位比较 | 两片 HCMOS 加几个无源件换来约 6 倍分辨率提升，性价比最高 |
| 要做到公开方案的最好水平 | TDC7200 | 55 ps，无需校准，但多一颗芯片加 SPI 加一套固件 |

### 4.2 一个容易被忽略的细节

Carsten Andrich 的方案里有一条很值得借鉴的做法：**在调谐 DAC 之后加一级 1 Hz 有源低通滤波器，以获得优于 16 bit 的等效调谐分辨率**。

这和本项目的做法思路一致——本项目用的是 PWM 加二阶 RC（截止频率 0.80 Hz），本质是同一个技巧。区别在于他用的是有源滤波，顺便解决了源阻抗问题；而本项目是纯无源 RC，源阻抗 40 k 欧，这正是 OCXO 选型文档里标记的**风险 A**。**他的方案等于把那个风险提前解决了，值得照搬。**

---

## 5. 推荐

### 5.1 按目的推荐

| 你的目的 | 推荐项目 | 怎么用 |
| --- | --- | --- |
| **借鉴架构设计**（本项目当前最需要） | **Carsten Andrich 的 STM32G4 方案** | 同为 STM32G4，看他的原理图 PDF 与 time-nuts 帖子，重点看 TDC7200 接法、DAC 后有源滤波、以及为什么不对 OCXO 输出做数字分频 |
| **学控制环与 TIC 原理** | **Lars Walenius GPSDO** | 读 EEVblog 主帖。他的 1 ns 模拟 TIC 和 PI 环参数整定过程是最好的教材，且有大量实测数据可对照 |
| **快速做出一台能用的** | **AndrewBCN/STM32-GPSDO** | GPL-3.0，直接拿代码跑。架构和本项目几乎一样，固件可大段参考 |
| **参考 PCB 与器件选择** | **ahhuhtal/gpsdo** | 它驯服的 OSC5A2B02 就是 OCXO 选型文档里的经典廉价件，PCB 可直接比对 |
| **评测自己做的 GPSDO** | **TAPR TICC** 加 **TimeLab** | 没有比被测对象更好的参考，就测不出真实性能。TICC 是 BSD 开源的，可以自己做 |

### 5.2 对本项目的三条具体建议

1. **立刻补锯齿波修正。** 纯固件工作，零硬件成本，是当前投入产出比最高的一项。前提是换成支持该消息的 GNSS 模组，见 GNSS 选型文档——NEO 系列的 UBX-TIM-TP 或 SkyTraq 的 PSTI,00。
2. **把 Lars 的模拟 TIC 作为中期升级选项。** 在不加 TDC 芯片的前提下，两片 HCMOS 就能把分辨率从 5.9 ns 提到 1 ns。如果 PCB 还有改版机会，这个改动很值。
3. **照搬 Andrich 的 DAC 后有源滤波。** 它同时解决了调谐分辨率和 EFC 源阻抗两个问题，正好对应 OCXO 选型文档里的风险 A。

### 5.3 不建议走的路

- **直接照抄某个项目的完整设计。** 本项目是电池供电便携方案，而上述所有开源项目都是台式供电，没有一个考虑过功耗预算与电池续航。架构可以借鉴，供电与热设计必须自己做。
- **在没有比被测对象更好的参考源之前相信自己的测量结果。** 用本项目的 MCU 去测本项目的 OCXO，测到的是两者误差的组合，不是 OCXO 的真实性能。
- **把分辨率当成精度。** 见第 3 节。55 ps 的 TDC 配一颗差的 OCXO 和一个导航级 GNSS，输出照样很差。

---

## 6. 复现与测量的现实提醒

| 事项 | 说明 |
| --- | --- |
| 参考源问题 | 要验证 1e-12 量级的性能，需要一个比它更好的参考——铷钟、另一台已知良好的 GPSDO，或者长时间与 GPS 比对取统计。**这是 DIY GPSDO 最大的门槛，不是电路** |
| 测量时长 | 要看清 tau = 1000 s 处的 ADEV，至少需要连续采集十小时以上；要看 tau = 1e4 s，需要数天 |
| 温度是最大干扰 | 实验室环境的昼夜温度变化会直接出现在 ADEV 曲线的长 tau 段。公开实测数据之间不可比，除非说明了环境条件 |
| 数据性质要分清 | 本文第 2 节各项目的指标，**作者自述、设计目标、第三方实测三者可信度差别很大**，已逐条标注 |

---

## 7. 关键数值汇总

| 项目 | 数值 |
| --- | --- |
| 本项目当前 TIC 分辨率 | 单次 100 ns（以 OCXO 10 MHz 为 TIM2 时基）；改板送 OSC_IN 后可达 5.9 ns |
| Lars 方案 TIC 分辨率 | 约 1 ns，量程 1 us |
| TDC7200 单次分辨率 | 55 ps；长观测区间极限约 60 ps |
| TAPR TICC 指标 | 单次分辨率小于 60 ps，抖动小于 100 ps，约 100 次每秒 |
| Lars 方案实测 ADEV | 1 s 处 2e-8；1000 s 处 2e-11；与铷钟对比时 1000 s 处约 2e-12 |
| AndrewBCN 方案 | 低于 30 欧元，正负 1 ppb 开箱性能 |
| Andrich 方案设计目标 | 10 km 半径内相对精度优于 10 ns；GNSS 的 ADEV 约 5e-11 @10 s |
| 典型环路交越点 | 100 到 1000 s |

---

## 8. 待办

1. 读 Carsten Andrich 在 time-nuts 的原帖与原理图 PDF，整理出可借鉴的具体电路（TDC7200 接法、DAC 后有源滤波、时钟分配）。
2. 评估给本项目加 TDC7200 的代价：PCB 面积、SPI 占用、固件工作量，与改用 Lars 模拟 TIC 的方案做定量对比。
3. 下载 AndrewBCN/STM32-GPSDO 的固件，研究其环路实现与参数，作为本项目固件的起点（注意 GPL-3.0 的传染性，若要闭源需自行实现）。
4. 比对 ahhuhtal/gpsdo 的 PCB 与本项目 v1.0 的 OCXO 供电与 EFC 部分。
5. 装 TimeLab，确定本项目的 ADEV 测量与数据导出格式。
6. 评估参考源方案：是否需要购置一台已知良好的 GPSDO 或铷钟作为测量基准。

---

## 9. 参考来源

```
GitHub gpsdo topic 仓库列表
  https://github.com/topics/gpsdo
AndrewBCN/STM32-GPSDO
  https://github.com/AndrewBCN/STM32-GPSDO
ahhuhtal/gpsdo
  https://github.com/ahhuhtal/gpsdo
YannickTurcotte/GPSDO-YT
  https://github.com/YannickTurcotte/GPSDO-YT
dfannin/gpsdo
  https://github.com/dfannin/gpsdo
xiedidan/gpsdo-alpha
  https://github.com/xiedidan/gpsdo-alpha
glenoverby/gpsdo
  https://github.com/glenoverby/gpsdo
SomerledDesign/GPSDO (基于 Trimble Thunderbolt)
  https://github.com/SomerledDesign/GPSDO
jimharman/Arduino-GPSDO (基于 Lars 的设计)
  https://github.com/jimharman/Arduino-GPSDO
TAPR TICC 项目主页
  https://www.febo.com/pages/TICC/
TAPR TICC 源码 (BSD)
  https://github.com/TAPR/TICC
time-nuts: New Timestamping / Time Interval Counter: the TICC
  https://www.febo.com/pipermail/time-nuts/2016-November/102235.html
time-nuts: Arduino GPSDO with 1ns res TIC (Lars 原始发布)
  https://febo.com/pipermail/time-nuts/2014-March/083326.html
  https://www.febo.com/pipermail/time-nuts/2014-February/082820.html
time-nuts: Lars GPSDO on EEVblog
  https://febo.com/pipermail/time-nuts_lists.febo.com/2018-September/094020.html
EEVblog: Lars DIY GPSDO with Arduino and 1ns resolution TIC
  https://eevblog.com/forum/projects/lars-diy-gpsdo-with-arduino-and-1ns-resolution-tic/
EEVblog: DIY GPSDO project w/ STM32, TDC7200 (thinkfat)
  https://eevblog.com/forum/projects/diy-gpsdo-project-w-stm32-tdc7200/
time-nuts: GPSDO/GNSSDO project: STM32G4 + u-blox ZED-F9T + TDC7200 (Andrich)
  https://febo.com/pipermail/time-nuts_lists.febo.com/2022-August/106228.html
time-nuts: The STM32 GPSDO, a short presentation (Balsa)
  https://febo.com/pipermail/time-nuts_lists.febo.com/2022-March/105383.html
N8UR: GPS 接收机定时性能评测 (HamSCI 2021)
  https://hamsci.org/sites/default/files/publications/2021_HamSCI/
  20210319_1320z-John_Ackermann_N8UR.pdf
SepticElectronics/High-Speed-Timer (TDC7200 + FPGA, 55 ps)
  https://github.com/SepticElectronics/High-Speed-Timer
```

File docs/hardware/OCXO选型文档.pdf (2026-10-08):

CORE 项目 · 硬件设计文档 | 第 1 页

# 10 MHz OCXO 选型文档

GPSDO 项目 · 硬件选型 · v1.1 · 2026-10-08 · 适用 hardware/schematic/v1.0

数据来源声明。 本文中的板级约束（封装尺寸、焊盘坐标、网络连接、供电拓扑、EFC 滤波参数）全部由本仓库 hardware/schematic/v1.0/GPSDO.kicad_sch 与 GPSDO.kicad_pcb 解析得出，可直接采信。本文中的具体型号 参数、价格与库存为依据厂商公开资料整理的典型值与量级，撰写时无法联网核对实时行情，下单前必须逐项核对最新 datasheet 与商城页面。凡标注"须复核"的条目请视为待验证项，而非结论。

## 1. 结论摘要

项目 | 结论
接口形 态 | 1 英寸见方（25.4 mm）金属壳直插 OCXO，引脚网格 19.0 mm，5 脚（3+2 排布），安装在 PCB 底面
输出要 求 | 必须是 HCMOS / LVCMOS 方波，本板没有任何正弦整形电路
控制方 式 | MCU PWM 经二阶 RC 滤波产生 0-3.3 V 控制电压，同时回读进 ADC
供电能 力 | TPS7A8901 双路 LDO，输入取自 SYS（单节锂电系统轨 3.0-4.4 V）。该轨在结构上做不出 5 V，单通道约 500 mA（须复核）
第一结 论 | 不改板时只能选"3.3 V 供电、预热小于 1.5 W、稳态小于 1.0 W"的低功耗型号，这个组合在 1 英寸直插壳里选择面很窄、单价偏高
推荐路 线 | 增加一路 5 V 升压，把 OCXO 轨改为 5 V。这一步打开整个 5 V OCXO 市场，新品与拆机件都极易购买
牵引范 围 | 0-3.3 V 控制范围内总牵引量取 3 到 10 ppm（即 ±1.5 到 ±5 ppm），依据见第 3.3、3.4 节
必须避 开 | 正弦输出、12 V 供电、封装大于 25.4 mm、脚位网格不是 19 mm、无 EFC 引脚、无 datasheet 的三无拆机件

### 1.1 三条可选路线

路线 | 做法 | 板级改动 | 器件档次 | 整机功耗 | 适用场景
路线 1 不改板 | 选 3.3 V 低功耗 OCXO | 无 | ±5 到 ±20 ppb 小型低功耗件 | 预热小于 1.5 W，稳态小于 1 W | 坚持电池便携，可接受 高单价与窄选择面
路线 2 推荐 | 加 5 V 升压后供 OCXO | 加 1 颗升压 IC 加电感电容，约 6 个元件 | ±5 ppb 主流 5 V 件，选择面最大 | 预热 3 到 5 W，稳态 1.5 到 2.5 W | 大多数情况的最优解， 续航按 2 到 4 h 设计
路线 3 替代 | 改用超稳 MEMS 数字调频器件 | EFC 通道改走 I2C，PWM 链路作废 | ±100 ppb 级，优于普通 TCXO 但不及 OCXO | 小于 0.15 W | 把便携续航排在短稳之 前的产品定位

## 2. 板级约束（实测自 v1.0 工程文件）

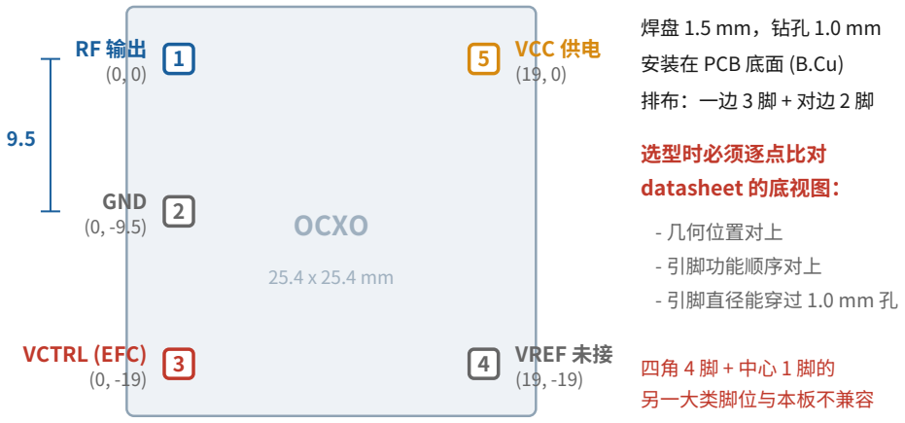
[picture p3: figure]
OCXO; GND (0, -9.5); VCTRL (EFC); VREF 未接 (19, -19); VCC 供电 (19, 0); 安装在 PCB 底面 (B.Cu); 选型时必须逐点比对; datasheet 的底视图：; - 几何位置对上; - 引脚功能顺序对上; - 引脚直径能穿过 1.0 mm 孔; 另一大类脚位与本板不兼容

CORE 项目 · 硬件设计文档 | 第 2 页

### 19.0 mm 引脚网格

图 1 U2 焊盘实测坐标与引脚功能（数据取自 GPSDO.kicad_pcb）

### 2.1 封装与脚位

PCB 中 OCXO 位号 U2，封装 Counter:OCXO_19x19mm，位于 B.Cu 即板底面。丝印外框从 -3.25 mm 到 +22.25 mm，约 25.5 mm 见方，对应标准 1 英寸金属壳 OCXO。

焊盘 | 相对坐标 mm | 原理图引脚名 | 实际连接网络 | 说明
1 | (0, 0) | RF | Net-(U2-RF) | 10 MHz 输出，串 R6 180 欧
2 | (0, -9.5) | GND | BAT- | 地。本工程的地网络最终名为 BAT-
3 | (0, -19) | VCTRL | VCTL | 电压控频 EFC 输入
4 | (19, -19) | VREF | 未连接 | 预留给带内部基准输出的型号
5 | (19, 0) | VCC | +3.3/+5V | OCXO 供电轨，见 2.2

机械参数：焊盘 1.5 mm 圆角矩形，钻孔直径 1.0 mm；引脚网格 19.0 x 19.0 mm（业界标准 0.75 英寸即 19.05 mm，0.05 mm 差异可由 1.0 mm 孔吸收）。

选型时必须核对的三件事。 一，脚位排布：本板是"一条边 3 脚间距 9.5 mm，对边 2 脚间距 19 mm"。这是常见但并非唯一的 1 英寸 OCXO 脚位，另一大类"四角 4 脚加中心 1 脚"与本板不兼容。二，引脚功能顺序：几何位置对上不等于功能对上，各厂对 VCC / VC / OUT / GND 的分配顺序不同。三，引脚直径：部分 OCXO 用直径 1.0 mm 粗针，塞进 1.0 mm 孔会很紧，0.45 到 0.6 mm 细针则没问题。

### 2.2 供电通道

供电链路为：USB VBUS 或电池，经 BQ25890 得到 SYS，再经 TPS7A8901 双路超低噪 LDO 得到 +3.3V 与 +3.3/+5V。OCXO 挂在第二路输出上。该路的反馈电阻 R10 / R11 目前数值未定义（原理图中 R10 的值写成 "100nF"、R11 的值写成 "GND"，是占位符）。焊接跳线 JP1 可把该轨直接短接到主 3.3 V。

关键结论：该轨不可能输出 5 V。 TPS7A8901 是线性稳压器，输出必然低于输入，而它的输入是 SYS，BQ25890 的 SYS 轨在单节锂电系统中约为 3.0 到 4.4 V。因此网络名 +3.3/+5V 里的 "+5V" 在当前拓扑下无法实现。要用 5 V OCXO 就必须新增升压级，见第 7 节。

CORE 项目 · 硬件设计文档 | 第 3 页
项目 | 数值与影响
可用输出 电压 | 3.3 V
单通道电 流上限 | 约 500 mA（TPS7A89 系列标称，须复核），3.3 V 下对应约 1.65 W 功率上限
低电池风 险 | 锂电放到 3.4 V 时 SYS 约 3.4 V，扣掉 LDO 压差后 3.3 V 轨掉出调整区，OCXO 供电随电池漂移，再经电压频率灵敏度（典型 ±1 ppb 每 1% VCC）污染频率
由此得出 的门槛 | 预热峰值不超过 1.5 W（约 455 mA），稳态不超过 1.0 W，才能不改板直接使用

对照：典型 1 英寸金属壳 OCXO 的预热功耗是 3 到 6 W，稳态 1.2 到 2.5 W。绝大多数常见型号会超出本板 LDO 的电流能力，这正是推荐路线 2 的根本原因。

### 2.3 EFC 电压控频通道

链路为：MCU PWM 引脚，经 R4 20k 与 C1 10uF、R5 20k 与 C2 10uF 两级 RC，得到 VCTL 送 OCXO 引脚 3，C3 0.1uF 就近去耦，TP1 为测试点；VCTL 同时回接到 MCU 的一个 ADC 引脚做闭环监测。

项目 | 数值
控制电压范围 | 0 到 3.3 V（PWM 高电平即 MCU 的 VDD，未做电平放大）
滤波器 | 二阶 RC，单极点 fc = 1/(2 pi x 20k x 10uF) 约 0.80 Hz
PWM 载波（建议） | 16 位分辨率配 170 MHz 时钟，载波 2.594 kHz，两级合计衰减约 140 dB，纹波可忽略
建立时间 | 单级时间常数 0.2 s，二阶串联稳定到 0.1% 约需 1.5 到 2 s，远快于 GPSDO 环路带宽（毫赫兹量级）
源阻抗 | 40 k 欧（两级 20k 串联），见下方风险 A

风险 A：源阻抗过高。 EFC 节点的戴维南源阻抗是 40 k 欧。若所选 OCXO 的 EFC 输入阻抗为 Rin，实际到达变容管的电压被分压成 V 乘以 Rin/(Rin+40k)。Rin = 100 k 欧时只剩 71%，且 Rin 随温度变化会转化成控制增益漂移；若 EFC 端有输入偏置电流，还会带来固定电压误差。对策二选一：一是选型时限定 EFC 输入阻抗不低于 1 M 欧（变容管直连型多属此类，但必须查证）；二是在 RC 之后加一级轨到轨运放电压跟随器（OPA333 或 OPA192 级别，低失调低噪声）。推荐后者。

风险 B：PWM 幅度即基准。 控制电压等于 PWM 占空比乘以 MCU 的 VDD，3.3 V 轨的噪声与漂移会按比例直接调制 EFC。按 3.3 节的最佳区间（0-3.3 V 内总牵引 5 ppm，每 LSB 约 7.6e-11）计算，占空比在 50% 附近时，3.3 V 轨每变化 0.1 mV，EFC 就变化约 1 个 LSB。缓慢漂移会被环路纠正，但本板是电池供电，充电启停、蜂鸣器、GNSS 模组与 CH340E 的负载变化会让 3.3 V 轨出现 mV 级的快速台阶，这些台阶会直接变成频率台阶。

风险 B 的对策：在 PWM 与 RC 之间插入一颗由精密基准单独供电的单门 CMOS 缓冲器。 缓冲器输出的高电平就等于基准电压，与 3.3 V 轨无关；它的负载只是 20 k 欧的 RC，约 0.2 mA，一般精密基准都能直接驱动，输出电阻带来的误差在微伏级。基准有两种取法：一是取 OCXO 自身的 VREF 输出（本板焊盘 4 已预留，见 2.1 节），构成比率式调谐，基准漂移时 EFC 与 OCXO 内部基准一起漂、部分抵消，但需确认该型号 VREF
引脚的输出电流能力；二是用独立的精密基准。器件选择取决于基准电压：基准为 3.3 V 或更低时用 74LVC1G125 一类即可；基准高于 3.3 V 时（如 5 V 型号的 VREF），要改用 TTL 输入门限的 74AHCT1G125 或电平转换器 74LVC1T45，否则 MCU 3.3 V 的高电平达不到门限。做了这一步之后，"基准电压加 DAC"相对 PWM 已经没有基准方面的优势。

更正：用 ADC 回读 VCTL 做比例校正，在本板上不成立。 STM32G431KBU6 的 UFQFPN32 封装没有单独的 VREF+ 引脚，ADC 以 VDDA 为基准，而 VDDA 与数字电源同接 +3.3V。于是 ADC 读数等于 VCTL 除以 3.3 V

### 2.4 输出通道

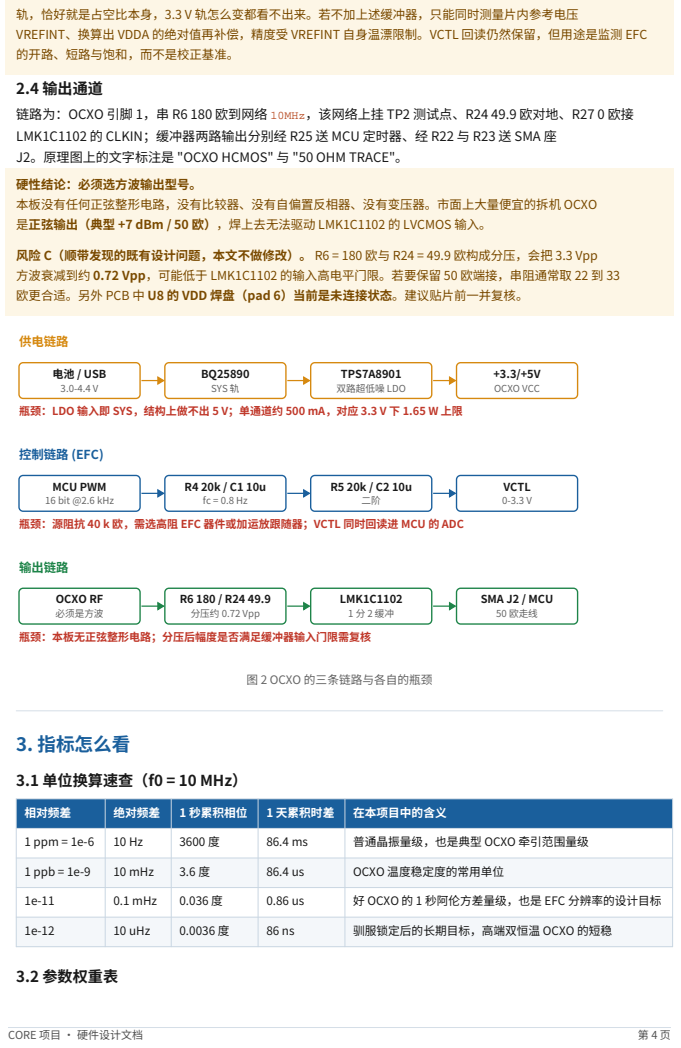
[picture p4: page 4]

轨，恰好就是占空比本身，3.3 V 轨怎么变都看不出来。若不加上述缓冲器，只能同时测量片内参考电压
VREFINT、换算出 VDDA 的绝对值再补偿，精度受 VREFINT 自身温漂限制。VCTL 回读仍然保留，但用途是监测 EFC
的开路、短路与饱和，而不是校正基准。

链路为：OCXO 引脚 1，串 R6 180 欧到网络 10MHz，该网络上挂 TP2 测试点、R24 49.9 欧对地、R27 0 欧接
LMK1C1102 的 CLKIN；缓冲器两路输出分别经 R25 送 MCU 定时器、经 R22 与 R23 送 SMA 座
J2。原理图上的文字标注是 "OCXO HCMOS" 与 "50 OHM TRACE"。

硬性结论：必须选方波输出型号。
本板没有任何正弦整形电路，没有比较器、没有自偏置反相器、没有变压器。市面上大量便宜的拆机 OCXO
是正弦输出（典型 +7 dBm / 50 欧），焊上去无法驱动 LMK1C1102 的 LVCMOS 输入。

风险 C（顺带发现的既有设计问题，本文不做修改）。 R6 = 180 欧与 R24 = 49.9 欧构成分压，会把 3.3 Vpp
方波衰减到约 0.72 Vpp，可能低于 LMK1C1102 的输入高电平门限。若要保留 50 欧端接，串阻通常取 22 到 33
欧更合适。另外 PCB 中 U8 的 VDD 焊盘（pad 6）当前是未连接状态。建议贴片前一并复核。

瓶颈：LDO 输入即 SYS，结构上做不出 5 V；单通道约 500 mA，对应 3.3 V 下 1.65 W 上限

瓶颈：源阻抗 40 k 欧，需选高阻 EFC 器件或加运放跟随器；VCTL 同时回读进 MCU 的 ADC

相对频差 | 绝对频差 | 1 秒累积相位 | 1 天累积时差 | 在本项目中的含义

1 ppm = 1e-6 | 10 Hz | 3600 度 | 86.4 ms | 普通晶振量级，也是典型 OCXO 牵引范围量级

1 ppb = 1e-9 | 10 mHz | 3.6 度 | 86.4 us | OCXO 温度稳定度的常用单位

1e-11 | 0.1 mHz | 0.036 度 | 0.86 us | 好 OCXO 的 1 秒阿伦方差量级，也是 EFC 分辨率的设计目标

1e-12 | 10 uHz | 0.0036 度 | 86 ns | 驯服锁定后的长期目标，高端双恒温 OCXO 的短稳

CORE 项目 · 硬件设计文档 | 第 5 页
参数 | 对 GPSDO 的作用 | 本项目目标 | 权重
短稳 ADEV，取样 1 到 100 s | 决定环路带宽以内以及交越点附近的实际性能，GPS DO 输出短稳基本等于 OCXO 自身短稳 | 1 s 不劣于 1e-11，10 s 不劣于 1e-11，100 s 不劣于 2e-11 | 最高
温度稳定度，全 温区峰峰值 | 环路带宽外的温度扰动无法被 GPS 修正，这是 OCXO 相对 TCXO 的核心价值 | 不超过 ±10 ppb，优选 ±5 ppb | 最高
牵引范围与 EFC 特性 | 太小则老化后拉不回，太大则分辨率与噪声抑制变差 ，定量见 3.3 与 3.4 | 0-3.3 V 内总量 3 到 10 ppm，单调且近似线性 | 最高
预热时间与功耗 | 直接决定电池续航与供电方案，便携设备的第一约束 | 见 2.2，不改板需预热不超过 1.5 W | 最高
老化率 | 决定失锁保持能力，以及 EFC 调谐余量能撑几年 | 不超过 1 ppb 每天，不超过 0.5 ppm 每年 | 高
相位噪声 | 影响作为射频本振或测试基准时的可用性，做时频基 准时优先级低于 ADEV | 10 Hz 处不劣于 -120 dBc/Hz，1 kHz 处不劣于 -145 dBc/Hz | 中
Retrace 重启复现性 | 断电冷却再上电回到原频率的能力，便携设备频繁开 关机时才重要 | 不超过 ±5 ppb | 中
电压与负载牵引 | 供电波动经此转成频率误差，与 2.2 的低电池风险叠加 | 不超过 ±1 ppb 每 1% VCC | 低
磁场与振动敏感 度 | 固定台式使用可忽略，移动使用会显著劣化短稳 | 了解即可，通常不作筛选条件 | 低

### 3.3 EFC 分辨率计算，决定牵引范围的上限

每 LSB 频率步进 df = 总牵引量[ppm] x 10 Hz/ppm / 2^N | (N 为 PWM 位数)
相对分辨率 | = df / 10 MHz

取 N = 16（STM32G431 配 170 MHz，PWM 载波 2.594 kHz，二阶 RC 后纹波已被抑制约 140 dB）：

0-3.3 V 内的总牵引量 | 全量程频率跨度 | 每 LSB 步进 | 相对分辨率 | 评价
1 ppm，即 ±0.5 ppm | 10 Hz | 0.153 mHz | 1.5e-11 | 分辨率好，但余量不足，见 3.4
3 ppm，即 ±1.5 ppm | 30 Hz | 0.458 mHz | 4.6e-11 | 下限，可用
5 ppm，即 ±2.5 ppm | 50 Hz | 0.763 mHz | 7.6e-11 | 最佳区间
10 ppm，即 ±5 ppm | 100 Hz | 1.53 mHz | 1.5e-10 | 上限，尚可
20 ppm，即 ±10 ppm | 200 Hz | 3.05 mHz | 3.1e-10 | 已劣于 OCXO 自身短稳，不推荐

注一：目标是让 EFC 分辨率优于 OCXO 在环路时间常数处的 ADEV（约 1e-11 到 1e-10），使量化台阶不成为性能瓶颈。上表 3 到 10 ppm 区间满足这一条件。

注二：若实际拿到的器件牵引范围偏大，可用固件做一阶 sigma-delta 抖动（在 1 秒更新周期内对占空比做时间维度抖动），再换取 2 到 4 位等效分辨率，RC 的 0.8 Hz 截止频率足以滤掉抖动噪声。

注三：C1 与 C2 是 10uF X7R，存在直流偏压容值衰减，实际可能只剩 50% 到 70%，fc 会升到约 1.1 到 1.6 Hz，对上述结论无实质影响。

### 3.4 调谐余量的寿命计算，决定牵引范围的下限

EFC 必须同时吸收下列各项：

CORE 项目 · 硬件设计文档 | 第 6 页
误差来源 | 典型量 | 说明
出厂初始频差 | ±0.5 ppm | 常见标称 ±0.5 ppm 或 ±1 ppm 在 25 摄氏度
第 1 年老化 | ±0.3 到 ±0.5 ppm | 按 1 ppb 每天，且首年速率最快
后续每年老化 | ±0.1 到 ±0.2 ppm 每年 | 老化率随时间衰减
温度加电压加 retrace | ±0.05 ppm | 相对老化项可忽略
5 年累计需求 | 约 ±1.3 到 ±1.5 ppm | 因此总牵引量需要不低于 3 ppm

### 3.3 与 3.4 的合并结论：在 0-3.3 V 控制范围内，总牵引量取 3 到 10 ppm 最佳。 注意 datasheet 通常标注的是 0-5 V

的牵引范围。若器件标称"±5 ppm 在 0-5 V"，本板只用到 0-3.3 V，实际可用牵引约为标称的 66%，即总量约 6.6 ppm，仍落在最佳区间内；但要注意标称频率点会落在 EFC 中点 1.65 V 附近而不是 2.5 V，选型时需确认该点仍在牵引曲线的线性段内。

## 4. 筛选清单

拿这张表对着商城页面逐条打勾。

序号 | 条件 | 要求 | 不满足的后果或处理
1 | 标称频率 | 10.000000 MHz | 硬性
2 | 输出波形 | HCMOS 或 LVCMOS 方波 | 正弦输出需自建整形电路，本板没有，直接 排除
3 | 输出电平 | 与 3.3 V 逻辑兼容，或经 2.4 节分压后仍满足缓冲器门限 | 5 V CMOS 输出经 180/49.9 分压后约 1.1 Vpp，需复核门限
4 | 供电电压 | 路线 1 为 3.3 V ±5%，路线 2 为 5.0 V ±5% | 12 V 型号一律排除
5 | 预热峰值电流 | 路线 1 不超过 450 mA，路线 2 建议不超过 1 A | 超出会导致限流保护、上电反复重启
6 | 稳态功耗 | 路线 1 不超过 1.0 W，路线 2 不超过 2.5 W | 直接决定电池续航
7 | 有 EFC 引脚 | 必须有，控制范围覆盖 0-3.3 V 或 0-5 V | 无 EFC 的固定频率 OCXO 无法驯服，排除
8 | 牵引范围 | 0-3.3 V 内总量 3 到 10 ppm | 过小则数年后失去调节能力，过大则分辨率 变差
9 | EFC 输入阻抗 | 不低于 1 M 欧，低于 200 k 欧必须加运放缓冲 | 见风险 A
10 | EFC 极性 | 正斜率或负斜率，已知即可 | 极性搞反会让环路变成正反馈而发散
11 | 封装与脚位 | 不大于 25.4 mm 见方，网格 19.0 或 19.05 mm，脚位逐点比对 2.1 表 | 不匹配需做转接小板或飞线
12 | 温度稳定度 | 不超过 ±10 ppb，优选 ±5 ppb | 决定环路带宽外的性能
13 | 老化率 | 不超过 1 ppb 每天 | 决定保持能力与调谐寿命
14 | 有正式 datasheet | 必须能拿到 PDF | 拿不到就只能按第 8 节实测反推脚位与极性

## 5. 候选器件

CORE 项目 · 硬件设计文档 | 第 7 页

下表价格为量级参考，参数为厂商公开资料的典型值，撰写环境无法联网核实。请把它当作搜索方向与判断框架，不要 当作最终报价与规格书。

### 5.1 B 档：正规渠道新品（推荐主力）

渠道为立创商城、贸泽、得捷、厂商代理。优点是有 datasheet、批次一致、可复购；缺点是单价高。

系列与品牌 | 封装 | 供电 | 典型指标（须复核） | 价格量 级 | 与本板匹配
Connor-Winfield OH300 系列 | 1 英寸金属 壳直插 | 3.3 V 或 5 V | HCMOS 输出，温度稳定度 ±5 到 ±20 ppb，老化约 1 ppb 每天 | 300 到 800 元 | 封装契合度最高的一类，务必核 对脚位排布与预热功耗
Taitien 泰艺 OCXO 系列 | 直插与贴片 均有 | 3.3 V 或 5 V | ±5 到 ±20 ppb，型号覆盖广 ，含低功耗版本 | 200 到 600 元 | 国内易买，有低功耗型号，是路 线 1 的主要希望
IQD OCXO 系列 | 直插或贴片 | 3.3 V / 5 V / 12 V | 分档细，从 ±20 ppb 到 ±1 ppb | 300 到 1500 元 | 贸泽常备，注意剔除 12 V 与正弦输出型号
Abracon AOCJY 系列 | 多为贴片， 约 10 x 8 mm 起 | 3.3 V | ±5 到 ±20 ppb，低功耗设计 | 200 到 600 元 | 贴片封装与本板直插焊盘不匹配 ，需转接板；但功耗最适合电池 供电
国产：成都天奥、 苏州东晶、扬兴 YXC 等 | 以 1 英寸直 插为主 | 5 V 居多 ，3.3 V 较少 | ±5 到 ±50 ppb 不等，分档明显 | 80 到 400 元 | 性价比最高的一类，务必索取 da tasheet，同一外形可能有多种 脚位定义

### 5.2 A 档：拆机与二手（低成本验证）

渠道为淘宝、闲鱼、AliExpress、eBay。优点是极便宜且常是高档货，缺点是无质保、批次不一、脚位与 EFC 需自行实测。

型号或类别 | 供电 | 输出 | 特点 | 价格量 级 | 与本板匹配
CTI OSC5A2B02 | 5 V | 方波 | 圈内最经典的入门件，±5 ppb 级，社区实测数据丰富 | 40 到 120 元 | 封装约 36 x 27 mm，脚位与本 板不匹配，需转接板加 5 V 升压
各类 1 英寸方壳 5 V 拆机件 | 5 V | 方波或 正弦 | 数量最多最便宜的一类，质量 参差需实测筛选 | 30 到 150 元 | 几何上最可能匹配本板，必须先 实测确认方波与脚位
Trimble / Symmetricom / Datum 拆机模块 | 多为 12 V | 常为正 弦 | 指标很好，部分是双恒温 | 80 到 300 元 | 供电与输出形式都不适配，只适 合当外部参考源
Morion MV89A 等 | 12 V | 正弦 | 短稳可达 1e-12 量级，发烧级选择 | 200 到 600 元 | 50.8 mm 封装加 12 V 加正弦，与本板完全不兼容

拆机件三条铁律。 一，先用限流实验室电源单独点亮实测，绝不直接焊上板。二，无 datasheet 时必须按第 8 节流程反推脚位，把 EFC
错接到电源会击穿变容二极管。三，同一链接的不同批次可能是完全不同的器件，量产不可依赖。

### 5.3 C 档：高性能（超出本板需求）

双恒温 DOCXO、恒温 SC 切晶体、Wenzel 与 Bliley 与 Morion 的高端型号，短稳可达 1e-12 甚至更好。这类器件普遍是 12 V 供电、功耗 5 到 15 W、体积 50 mm 以上、多为正弦输出，与本项目的便携电池 定位冲突。仅建议作为将来台式外接电源版本的升级选项，不在本板考虑范围。

CORE 项目 · 硬件设计文档 | 第 8 页

### 5.4 D 路线：超稳 MEMS 数字调频器件（替代方案）

以 SiTime SiT5711 与 SiT5721 一类"超稳 MEMS 振荡器"为代表：3.3 V 供电，功耗低于 0.15 W，通过 I2C 数字接口直接写入频率修正值，分辨率可达 1e-12 量级，不需要模拟 EFC 通道。

维度 | 相对 OCXO 的优势 | 相对 OCXO 的劣势
功耗 | 低 1 到 2 个数量级，彻底解决续航与 LDO 电流问题 | 无
预热 | 秒级可用，无长预热 | 无
调频接口 | 数字接口，本文 2.3 节的三个风险全部消失 | 需改硬件与固件走 I2C，PWM 加 RC 链路作废
温度稳定度 | 优于普通 TCXO | 通常仍不及好 OCXO 的 ±5 ppb
短稳 ADEV | 无 | 明显不如 OCXO，这是最关键的差距
封装 | 小型贴片 | 与本板直插焊盘不兼容，需改版

具体型号的稳定度与 ADEV 须查 SiTime 官方 datasheet 核实。此路线适合把"便携、续航、快速可用"排在"短期稳定度"之前的产品定位；若项目核心卖点是 ppb 级频率基准品质，仍应选 OCXO。

## 6. 推荐结论

### 6.1 首选方案

路线 2 加 B 档国产或台系 5 V 方波 OCXO。

1. 板上增加一路 5 V 升压，详见第 7 节，把 OCXO 供电与 3.3 V 数字域分开。
2. 选购 1 英寸直插、5 V 供电、HCMOS 方波输出、温度稳定度 ±5 到 ±10 ppb、老化不超过 1 ppb 每天、0-5 V 牵引 ±3 到 ±5 ppm 的型号。
3. EFC 仍用本板的 0-3.3 V 驱动，对应约 66% 牵引量，仍满足 3.4 节的余量要求；也可在升压后加运放把 0-3.3 V 放大到 0-5 V 以用满量程、改善线性度。
4. 在 RC 网络后加一级轨到轨运放跟随器，消除 40 k 欧源阻抗问题，即风险 A。

理由：5 V 是 OCXO 市场的主流供电，可选型号数量是 3.3 V 的数倍，价格低一个档次，且拆机件大量可用于前期验证。

### 6.2 备选方案（不想动板子）

路线 1 加低功耗 3.3 V OCXO。严格按第 4 节清单筛选，重点卡死"预热不超过 1.5 W、稳态不超过 1.0 W、3.3 V 供电、1 英寸直插、方波输出"这五条。同时满足的型号数量有限、单价偏高、选型工作量大，但完全不用改板。 若筛选中发现只有贴片封装的低功耗型号可选，做一块 25.4 mm 转接小板也是可行方案。

### 6.3 明确不推荐

- 任何 12 V 型号：本板无 12 V 轨，功耗也与电池方案冲突。
- 任何正弦输出型号：本板无整形电路，Morion 与多数 Trimble、Symmetricom 拆机件属此类。
- 无 EFC 引脚的固定频率 OCXO：无法驯服。
- 50 mm 级大封装双恒温件：与便携定位冲突。
- 未验证脚位就直接焊上板的拆机件：EFC 端错接电源会击穿变容管。

CORE 项目 · 硬件设计文档 | 第 9 页

## 7. 若走路线 2：供电改动要点

项目 | 说明
拓扑 | SYS（3.0 到 4.4 V）升压到 5.0 至 5.5 V，再经一级超低噪 LDO 稳到 5.0 V 供 OCXO。升压能力建议不低于 1.5 A 以覆盖预热浪涌
为什么要串 LDO | 升压是开关电源，其纹波与开关噪声会经供电灵敏度调制频率并抬高相噪基底，串一级低压差超低噪 LDO 并留 300 到 500 mV 压差可显著改善
网络与跳线 | 现有网络名 +3.3/+5V 已预留此意图。改动后应把 R10 与 R11 的占位值改成实际反馈电阻，或把该轨直接切到新的 5 V 源，并保留 JP1 作为回退到 3.3 V 的选项
电池续航估 算 | OCXO 稳态 2 W 加其余系统约 0.4 W 合计 2.4 W。按 3000 mAh 单节锂电约 11 Wh、转换效率 85% 计算，约 3.9 小时。预热阶段 3 到 5 分钟按 4 到 5 W 计，额外约 0.3 Wh，可忽略
热设计 | OCXO 装在板底面，稳态 2 W 会形成局部热源。一要避免其热流干扰 TMP117 的温度读数；二要避免机壳内气流直吹 OCXO，气流波动会转化成频率波动
EFC 电平匹 配（可选） | 用一级同相放大，增益 1.515，把 0-3.3 V 映射到 0-5 V 以用满牵引范围。但这会把牵引量放大 1.5 倍，需按 3.3 节重新核算分辨率是否仍在 3 到 10 ppm 的等效区间内

## 8. 到货验收流程

### 8.1 步骤

步 | 操作 | 方法 | 判据与记录
1 | 外观与 尺寸核 对 | 看壳体丝印与批次，用游标卡尺量壳体尺寸与引脚网格 | 网格 19.0 到 19.05 mm，壳体不超过 25.5 mm
2 | 脚位反 推（无 资料时 ） | 断电用万用表测各脚对壳体的阻值：近似 0 欧的是 GND；阻值极大且对地无低阻通路的是 EFC；剩余两脚串 100 欧限流后从 3.3 V 缓慢升压试探并监控电流 | 此步有烧毁风险，必须用限流电源，初 始限流设 100 mA。 记录每个脚的判定结论
3 | 预热电 流曲线 | 按标称电压供电、限流 1.5 A，记录 0、10 s、30 s、1 min、2 min、3 min、5 min、10 min 的电流 | 峰值是否在供电方案能力内，稳态是否 符合 datasheet。峰值超标即该器件不可用
4 | 输出波 形确认 | 用不低于 100 MHz 带宽的示波器配 10:1 探头测输出 | 必须是方波，记录 Vpp、上升沿、占空比，占空比应在 45% 到 55%
5 | EFC 牵 引曲线 实测 | EFC 从 0 V 起按 0.2 到 0.5 V 步进扫到满量程，每点稳定 60 s 后用频率计或与 GPS 1PPS 比对的闸门计数测频 | 画出 f-V 曲线，确认单调性、极性、总 牵引量、线性度，总牵引量应落在 3.4 节要求内
6 | EFC 输 入阻抗 估算 | 在 EFC 支路串入已知电阻如 100 k 欧，比较串入前后的频率变化量反推分压比 | 推得 Rin。低于 200 k 欧则必须加运放缓冲
7 | 准确度 与预热 漂移 | EFC 置于中点，连续记录 30 分钟频率 | 记录 5、10、30 分钟时刻的频差，预热判据一般取"进入 ±1 ppb 带宽"

CORE 项目 · 硬件设计文档 | 第 10 页
步 | 操作 | 方法 | 判据与记录
8 | 老化观 察 | 常温连续通电 7 到 30 天，每天同一时刻记录频率 | 拟合日老化率，应不超过 1 ppb 每天。 拆机件的老化通常已趋于平缓，这是二 手件的真实优点
9 | ADEV 测量 | 与 GPS 1PPS 做时间间隔测量，本板 MCU 的 32 位定时器即可粗测，采样不少于 10000 点，算重叠阿伦偏差 | 对照 3.2 节目标，1 秒处不劣于 1e-11
10 | 温度敏 感度（ 可选） | 用热风枪或温箱在 0 到 60 摄氏度间缓慢变温，同步记录 TMP117 与频率 | 得到频温曲线峰峰值，可用于固件前馈 补偿

### 8.2 验收记录表模板

项目 | 实测值 | 判据 | 结论
型号 / 批次 / 渠道 | | 记录用
壳体尺寸与引脚网格 mm | | 不超过 25.5，网格 19.0 到 19.05
引脚 1 到 5 的功能 | | 与 2.1 表一致
供电电压与稳态电流 | | 与所选方案匹配
预热峰值电流与持续时间 | | 不超过供电能力
输出波形 Vpp 与占空比 | | 方波，45% 到 55%
EFC 极性 | | 已确定
0-3.3 V 牵引量 ppm | | 3 到 10 ppm
EFC 输入阻抗 | | 不低于 1 M 欧，否则加缓冲
10 分钟频差 ppb | | 不超过 ±10 ppb
日老化率 ppb 每天 | | 不超过 1
ADEV 1 秒与 100 秒 | | 不劣于 1e-11 与 2e-11

## 9. 购买渠道与询价

渠道 | 搜索关键词或筛选路径 | 备注
立创商城 | "恒温晶振 OCXO 10MHz"，筛选频率 10 MHz、封装选插件、输出选 CMOS 或 HCMOS | 有中文规格书与现货标识，最省 事的正规渠道
贸泽 Mouser 与得捷 DigiKey | 参数筛选：Frequency 选 10 MHz，Package 选 Through Hole，Supply 选 3.3 V 或 5 V，Output 选 HCMOS，功能选带 EFC 的 VCOCXO | 参数筛选器最强、datasheet 齐 全，价格最高，注意关税与起订 量
淘宝 | "10M 恒温晶振 方波"、"OCXO 10MHz 压控 5V"、"恒温晶振 25.4 直插" | 新品与拆机混杂，下单前务必私 信索要 datasheet 与脚位图
闲鱼与 eBay | "拆机 恒温晶振"、"OCXO 10MHz" | 最便宜，也最需要第 8 节的完整验收流程
AliExpress | "OCXO 10MHz square wave"、"OCXO 10MHz VCOCXO" | 与淘宝货源大致重合

CORE 项目 · 硬件设计文档 | 第 11 页

询价话术模板，可直接复制给卖家：

你好，我需要 10 MHz 恒温晶振，请确认以下几点：
1) 输出是方波 HCMOS 还是正弦？
2) 供电电压是多少？
3) 预热电流峰值和稳态电流各是多少？
4) 有没有压控 EFC 引脚？控制电压范围和牵引量是多少 ppm？
5) 能否提供 datasheet 和引脚定义图（底视图，含引脚间距尺寸）？

## 10. 附录

### 10.1 术语

术语 | 含义
OCXO | 恒温晶体振荡器。晶体置于恒温槽中，用温控消除频温曲线的影响，是本项目的核心器件
EFC 或 VC | Electronic Frequency Control，电压控频输入，是 GPSDO 环路的执行端
牵引范围 | EFC 从最低到最高时能改变的频率总量，通常以 ppm 表示
ADEV | 阿伦方差或阿伦偏差，频率源短期稳定度的标准度量，与取样时间相关
Holdover | 失去 GPS 信号后仅靠 OCXO 自身维持精度的能力，主要由老化率与温度稳定度决定
Retrace | 断电冷却后再上电，频率回到原值的复现能力
DOCXO | 双恒温 OCXO，两级温控，性能更高、功耗更大

### 10.2 关键数值汇总

项目 | 数值
OCXO 焊盘引脚网格 | 19.0 x 19.0 mm，钻孔 1.0 mm，底面安装
EFC 滤波器 | 二阶 RC，fc = 0.80 Hz，源阻抗 40 k 欧
EFC 源阻抗处理 | 加轨到轨运放跟随器，或选输入阻抗不低于 1 M 欧的器件
推荐 PWM 分辨率与载波 | 16 位，2.594 kHz，基于 170 MHz 时钟
推荐牵引范围 | 0-3.3 V 内总量 3 到 10 ppm
不改板时的功耗门槛 | 预热不超过 1.5 W，稳态不超过 1.0 W
路线 2 的电池续航估算 | 约 3.9 小时，按 3000 mAh 单节锂电、OCXO 稳态 2 W 计
短稳目标 | 1 秒阿伦偏差不劣于 1e-11

### 10.3 待办事项

1. 复核 TPS7A8901 的实际单通道电流能力与压差，本文按 500 mA 估算。
2. 确定 R10 与 R11 的实际阻值，明确 +3.3/+5V 轨的目标电压，当前是占位值。
3. 复核 R6 180 欧与 R24 49.9 欧的分压比是否满足 LMK1C1102 的输入门限，并确认 U8 的 VDD 焊盘连接。
4. 确定走路线 1、2 还是 3 之后，按第 4 节清单锁定 2 到 3 个候选型号，各买 1 只按第 8 节验收，用实测数据定型。
5. 把最终选定型号的 EFC 极性、牵引量 Hz 每伏、预热时间写入固件常量与 hardware/bom/。

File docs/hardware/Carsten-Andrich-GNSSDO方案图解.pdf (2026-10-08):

CORE 项目 · 硬件设计文档 | 第 1 页

# Carsten Andrich GNSSDO 方案图解

GPSDO 项目 · 参考方案图解 · v1.0 · 2026-10-08

资料来源与可信度声明。 本文的电路细节全部取自作者公开的两版原理图 PDF（v1：2022-08-05；v2：2022-08-10 至 08-11）和 v2 版图 PDF，设计思路取自作者在 time-nuts 邮件列表与 EEVblog 论坛的两个讨论串（2022-08-05 至 2022-09-03），逐条来源列在第 13
节。截至作者最后一条公开帖（2022-09-03），整机没有发布任何实测结果，固件与 KiCad 工程也未公开，只有原理图与版图的 PDF。文中的滤波器 f0、Q、群时延与幅频曲线是本文按原理图元件值自行计算的 ；标注"推断"的内容是本文根据帖子描述整理，作者并未明说。

## 1. 方案速览

项目 | 内容
作者 | Carsten Andrich，自述职业为射频工程师
发布 | 2022-08-05 同时发到 time-nuts 与 EEVblog；08-11 更新原理图并发布版图
用途 | 移动车辆之间的精确时间同步，服务于分布式 SDR 的相干采样与毫米波变频器。载体主要是汽车，也可能上飞机
为什么 自己做 | 作者在工作中用过 Ministd、Jackson Labs LC_XO、SRS FS740，移动中都不满足要求
指标目 标 | 10 km 半径内、移动中相对时间误差 < 10 ns，期望 < 1 ns。只要求相对同步，不关心绝对 UTC 误差
成本目 标 | 单台器件与制造费用 < 500 欧元，不含 OCXO
开发优 先级 | 性能 > 简洁 > 性价比（作者原话的顺序）
核心器 件 | ZED-F9T（用 RCB-F9T 评估板）、TDC7200、STM32G474RE、Abracon AOCJY OCXO、LMK1C1103、AD5542A、ADR4533、OPA189、BUF602 x5、TMP117；v2 加 IIM-42652 IMU
板子 | 100 x 100 mm，5 路 SMA，三路电源全部外供
进度 | 原型设计定稿；TDC7200 死区问题已用面包板实测验证；整机性能未见公开

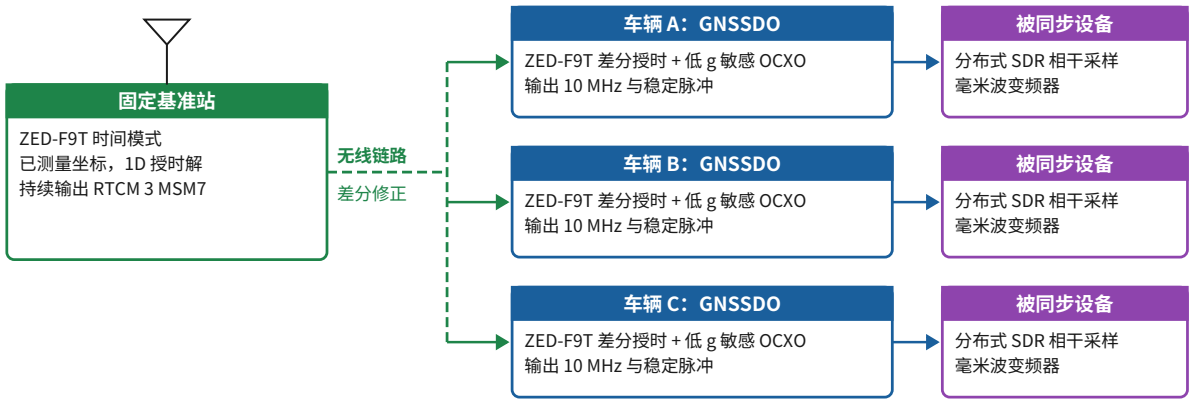
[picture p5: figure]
固定基准站; ZED-F9T 时间模式 已测量坐标，1D 授时解 持续输出 RTCM 3 MSM7; 无线链路; 差分修正; 车辆 A：GNSSDO; ZED-F9T 差分授时 + 低 g 敏感 OCXO 输出 10 MHz 与稳定脉冲; 被同步设备; 分布式 SDR 相干采样 毫米波变频器; 车辆 B：GNSSDO; 车辆 C：GNSSDO

CORE 项目 · 硬件设计文档 | 第 2 页

GNSS 卫星（基准站与车辆共视）

目标：10 km 半径内、移动中相对时间误差 < 10 ns，期望 < 1 ns。1 ns 对应电波传播约 30 cm。

只要求车辆之间相对同步，不关心绝对 UTC 误差。作者用过的 Ministd、LC_XO、FS740 在移动中均不达标。

图 1 应用场景：基准站播发差分修正，各车辆上的 GNSSDO 彼此相对同步

### 1.1 作者明确提出的三处改进

作者说明这套架构受 thinkfat（Matthias Welwarsky）的 STM32 + TDC7200 方案启发，并在三处做了改动：

方面 | thinkfat 的做法 | Andrich 的做法 | 理由（作者自述）
OCXO 输出给 TDC | 经 74HC390 分频 | 10 MHz 直接送 TDC7200，不分频 | 分频器的传播延迟随温度变化
时钟分配器 件 | 74 系列逻辑 | 只用 LMK1C110x 这类低抖动时钟芯片 | 74 系列没有抖动与相噪指标
调谐电压 | DAC 直接送 OCXO | DAC 后加 1 Hz 有源低通 | 一是压低电源、基准、DAC 送进 EFC 的噪声；二是为在 16 bit 之上叠加 PWM 扩展分辨率留出条件

## 2. 系统架构

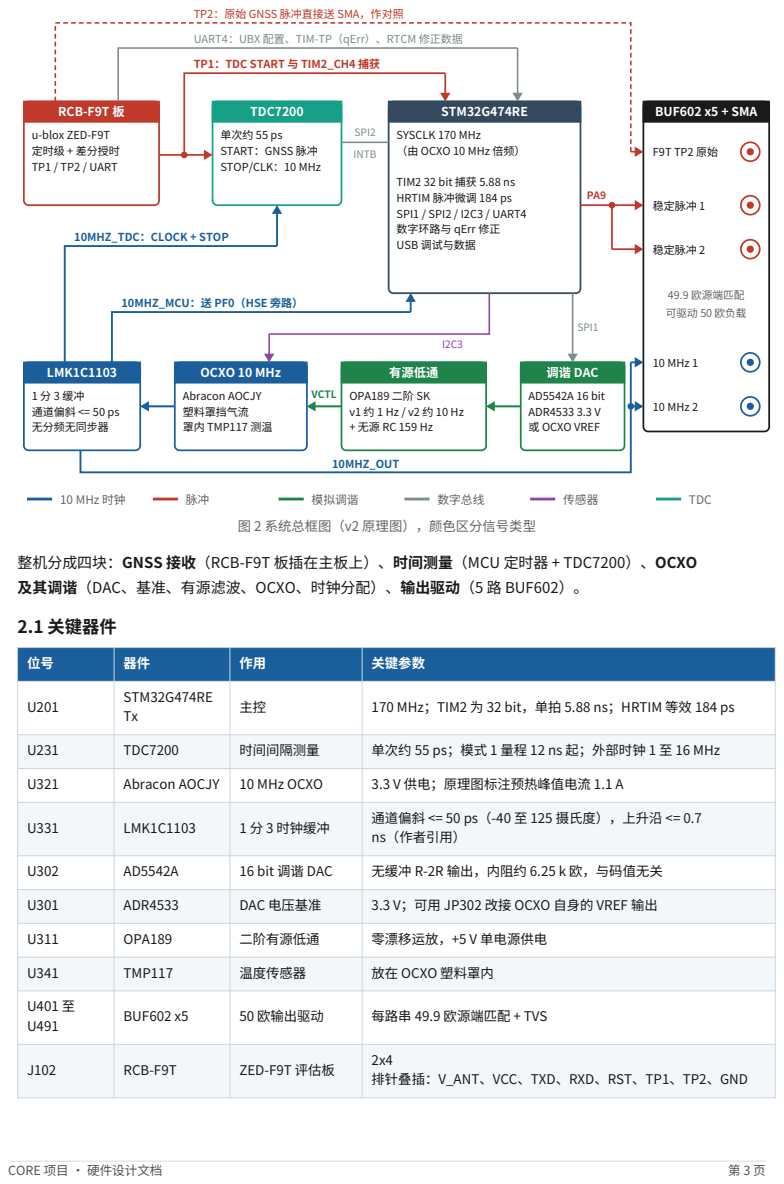
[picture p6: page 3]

TP2：原始 GNSS 脉冲直接送 SMA，作对照

UART4：UBX 配置、TIM-TP（qErr）、RTCM 修正数据

整机分成四块：GNSS 接收（RCB-F9T 板插在主板上）、时间测量（MCU 定时器 + TDC7200）、OCXO
及其调谐（DAC、基准、有源滤波、OCXO、时钟分配）、输出驱动（5 路 BUF602）。

位号 | 器件 | 作用 | 关键参数

U201 | STM32G474RE Tx | 主控 | 170 MHz；TIM2 为 32 bit，单拍 5.88 ns；HRTIM 等效 184 ps

U231 | TDC7200 | 时间间隔测量 | 单次约 55 ps；模式 1 量程 12 ns 起；外部时钟 1 至 16 MHz

U321 | Abracon AOCJY | 10 MHz OCXO | 3.3 V 供电；原理图标注预热峰值电流 1.1 A

U331 | LMK1C1103 | 1 分 3 时钟缓冲 | 通道偏斜 <= 50 ps（-40 至 125 摄氏度），上升沿 <= 0.7 ns（作者引用）

U302 | AD5542A | 16 bit 调谐 DAC | 无缓冲 R-2R 输出，内阻约 6.25 k 欧，与码值无关

U301 | ADR4533 | DAC 电压基准 | 3.3 V；可用 JP302 改接 OCXO 自身的 VREF 输出

U311 | OPA189 | 二阶有源低通 | 零漂移运放，+5 V 单电源供电

U341 | TMP117 | 温度传感器 | 放在 OCXO 塑料罩内

U401 至 U491 | BUF602 x5 | 50 欧输出驱动 | 每路串 49.9 欧源端匹配 + TVS

J102 | RCB-F9T | ZED-F9T 评估板 | 2x4 排针叠插：V_ANT、VCC、TXD、RXD、RST、TP1、TP2、GND

## 3. 时钟与脉冲分配

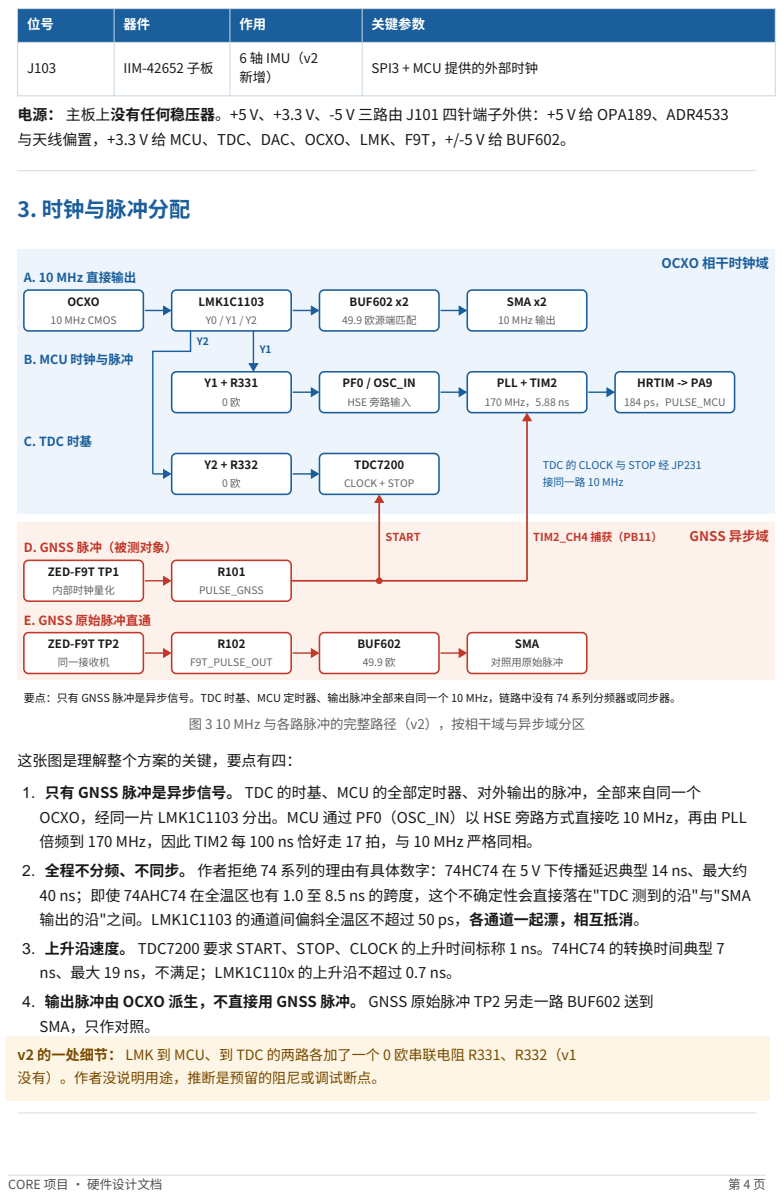
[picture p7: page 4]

位号 | 器件 | 作用 | 关键参数

J103 | IIM-42652 子板 | 6 轴 IMU（v2 新增） | SPI3 + MCU 提供的外部时钟

电源： 主板上没有任何稳压器。+5 V、+3.3 V、-5 V 三路由 J101 四针端子外供：+5 V 给 OPA189、ADR4533
与天线偏置，+3.3 V 给 MCU、TDC、DAC、OCXO、LMK、F9T，+/-5 V 给 BUF602。

要点：只有 GNSS 脉冲是异步信号。TDC 时基、MCU 定时器、输出脉冲全部来自同一个 10 MHz，链路中没有 74 系列分频器或同步器。

1. 只有 GNSS 脉冲是异步信号。 TDC 的时基、MCU 的全部定时器、对外输出的脉冲，全部来自同一个
OCXO，经同一片 LMK1C1103 分出。MCU 通过 PF0（OSC_IN）以 HSE 旁路方式直接吃 10 MHz，再由 PLL
倍频到 170 MHz，因此 TIM2 每 100 ns 恰好走 17 拍，与 10 MHz 严格同相。
2. 全程不分频、不同步。 作者拒绝 74 系列的理由有具体数字：74HC74 在 5 V 下传播延迟典型 14 ns、最大约
40 ns；即使 74AHC74 在全温区也有 1.0 至 8.5 ns 的跨度，这个不确定性会直接落在"TDC 测到的沿"与"SMA
输出的沿"之间。LMK1C1103 的通道间偏斜全温区不超过 50 ps，各通道一起漂，相互抵消。
3. 上升沿速度。 TDC7200 要求 START、STOP、CLOCK 的上升时间标称 1 ns。74HC74 的转换时间典型 7
ns、最大 19 ns，不满足；LMK1C110x 的上升沿不超过 0.7 ns。
4. 输出脉冲由 OCXO 派生，不直接用 GNSS 脉冲。 GNSS 原始脉冲 TP2 另走一路 BUF602 送到
SMA，只作对照。

v2 的一处细节： LMK 到 MCU、到 TDC 的两路各加了一个 0 欧串联电阻 R331、R332（v1
没有）。作者没说明用途，推断是预留的阻尼或调试断点。

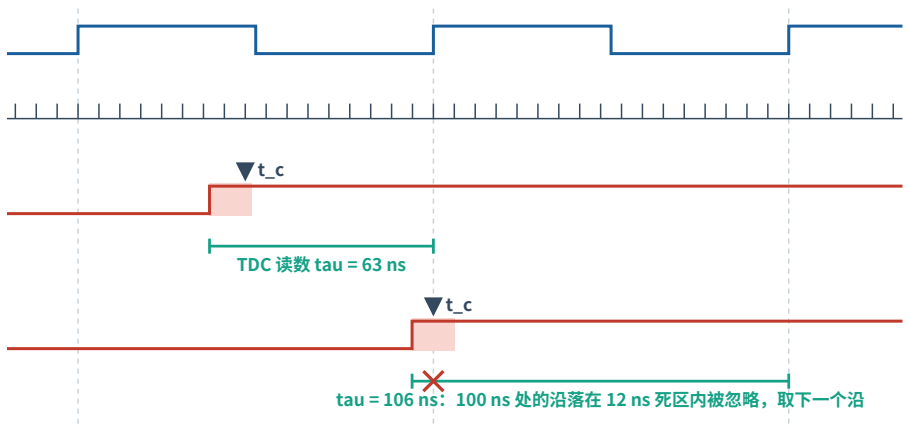
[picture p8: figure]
TDC 读数 tau = 63 ns

CORE 项目 · 硬件设计文档 | 第 5 页

## 4. 时间间隔测量：TIM2 粗测 + TDC7200 细测

### 4.1 原理

0 ns | 100 ns | 200 ns

### 10 MHz（CLOCK/STOP）

TIM2 节拍 5.88 ns

情形 A：GNSS 脉冲

情形 B：GNSS 脉冲

tau = 106 ns：100 ns 处的沿落在 12 ns 死区内被忽略，取下一个沿

(1) 粗测 | TIM2 捕获 GNSS 脉冲得 t_c。误差只要小于 +/-50 ns 即可，输入同步带来的固定延迟可一次标定。
(2) 细测 | TDC7200 测 tau：脉冲到其后第一个可用 10 MHz 上升沿，范围 12 ~ 112 ns，红色为 12 ns 死区。
(3) 组合 | k = round((t_c + tau) / 100 ns)，脉冲精确时刻 t = k x 100 ns - tau，分辨率由 TDC 决定。

图 4 两级时间测量时序。情形 A 是常规情况，情形 B 是 10 MHz 沿落进 TDC 死区的情况

TDC7200 的模式 1 只能测十几到几百 ns 的短间隔，而且单次误差随间隔线性增大（见 4.3 节）。作者的做法是：

- START 接 GNSS 脉冲，STOP 与 CLOCK 都接连续的 10 MHz（经 JP231 短接）。于是 TDC 测到的是"脉冲到其后第一个可用 10 MHz 沿"的时间 tau，范围 12 至 112 ns，这是周期内的精细相位。
- TIM2 的 32 bit 输入捕获（PB11，TIM2_CH4）同时给出粗时刻 t_c，分辨率 5.88 ns，用来判定"是哪一个 10 MHz 周期"，即解决 TDC 读数的 100 ns 周期模糊。
- 组合：k = round((t_c + tau) / 100 ns)，脉冲精确时刻 t = k x 100 ns - tau。

一个容易忽略的好处：粗测的误差只要小于正负 50 ns 就不影响取整。 所以 TIM2 输入同步造成的几个时钟周期的固定延迟完全无关紧要，粗测不需要标定到 ns 级。

### 4.2 TDC7200 死区之争与作者的解法

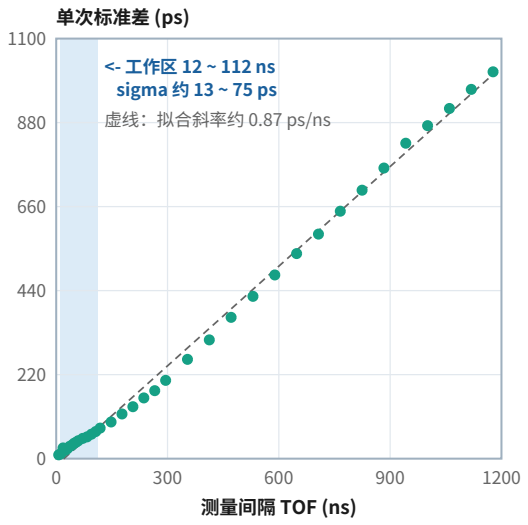
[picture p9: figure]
测量间隔 TOF (ns); 单次标准差 (ps); <- 工作区 12 ~ 112 ns sigma 约 13 ~ 75 ps; 虚线：拟合斜率约 0.87 ps/ns

CORE 项目 · 硬件设计文档 | 第 6 页
0 | 20 | 40 | 60 | 80 | 100

0

20

40

60

80

100

120

相位 phi：脉冲到下一个 10 MHz 沿 (ns)

TDC 读数 tau (ns)

折叠：读数 100 ~ 112 ns

约 12% 的脉冲落在此区

tau = phi

死区

右图数据：作者 2022-08-28 实测，模式 1，CALIBRATION2 = 10 周期，每点 10 万次。STOP 先于或等于 START 时全部判为无效。

图 5 左：周期性 STOP 下的读数折叠关系；右：作者面包板实测的单次标准差

发帖次日，vk3jpk 指出 TDC7200 模式 1 的最小可测间隔是 12 ns，脉冲落在 10 MHz 沿之前 0 至 12 ns 的情况（约 12% 的时间）会出问题，并建议照 TAPR TICC 的思路加一级 D 触发器同步器。thinkfat 也提到他用 74HC74 把 STOP 延迟一个周期。社区里的三种方案：

方案 | 做法 | 代价
同步器（TICC 思路） | D 触发器链把脉冲同步到 10 MHz，TDC 测脉冲到同步器输出 | 多器件，触发器延迟随温度变化 ，需从 TDC 结果中消掉
STOP 延迟一周期 （thinkfat） | 74HC74 把 STOP 推后 100 ns | 多器件，上升沿慢
作者的方案 A：利用周期性 | 不加任何器件。第一个沿落进死区就被忽略，TDC 自然测到下一个沿，读数从 0 至 12 ns 折叠到 100 至 112 ns | 折叠区的读数长了 100 ns，单次误差略大
作者的方案 B | TDC7200 寄存器 CLOCK_CNTR_STOP_MASK = 1，开始后等一个时钟周期再接受 STOP | 方案 A 失败时的后备

作者坚持方案 A 的理由：数据手册没有任何地方说 STOP 落在死区或先于 START 会影响后续测量；而且他不愿为一个"没有坚实技术理由"的同步器引入额外的温度相关延迟。

他随后用实测验证了这个假设（2022-08-28）。 做了一块 TDC7200 转接板插在 Nucleo-G474RE 上，用 TIM2 产生间隔可编程的 START/STOP（正间隔每点测 10 万次，负间隔每点 1 万次）：

结果 | 说明
STOP 先于或等于 START | 100% 判为溢出无效，不产生错误读数，下一次测量不受影响
设定间隔 5.88 ns | 仍有 99.8% 有效，平均读数 6.71 ns。说明标称 12 ns 是保证值，实际门限更低；设计上仍应按 12 ns 处理
设定间隔 >= 11.76 ns | 100% 有效
单次标准差 | 随间隔近似线性增长，拟合斜率约 0.87 ps/ns；12 至 112 ns 工作区内约 13 至 75 ps

### 4.3 实测中发现的一个坑：GPIO 输出速度

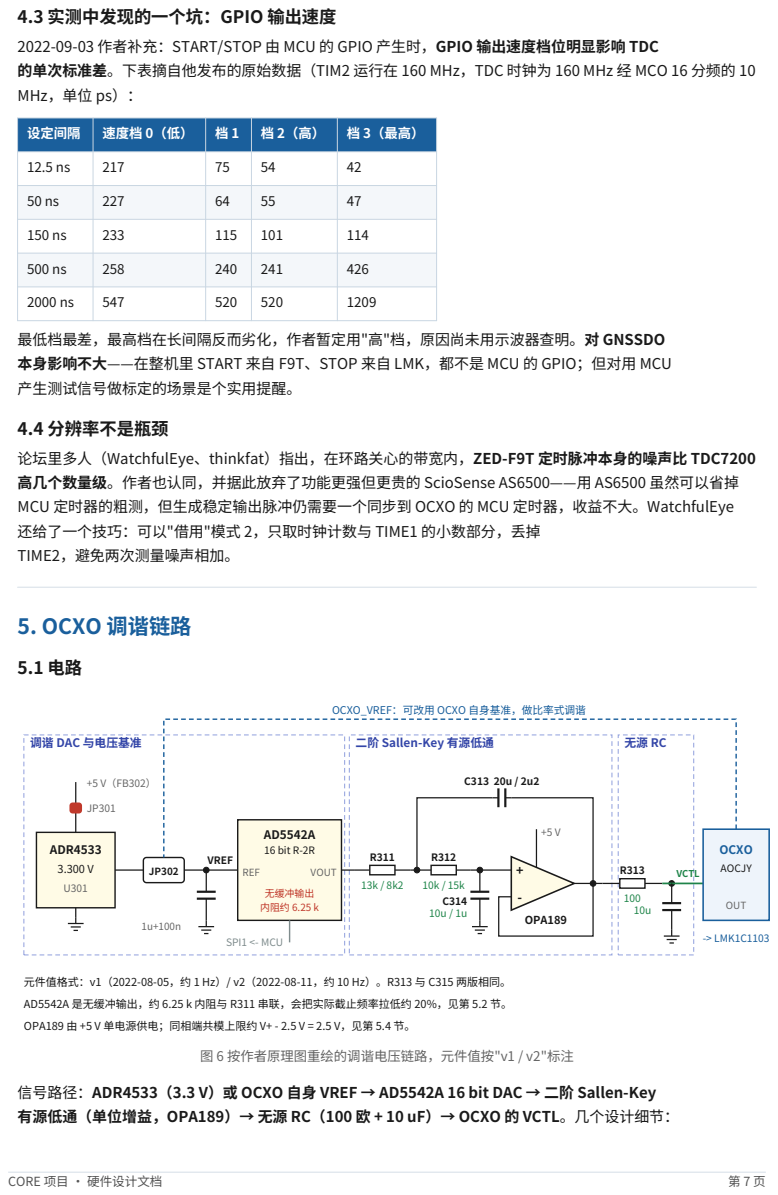
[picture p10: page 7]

2022-09-03 作者补充：START/STOP 由 MCU 的 GPIO 产生时，GPIO 输出速度档位明显影响 TDC
的单次标准差。下表摘自他发布的原始数据（TIM2 运行在 160 MHz，TDC 时钟为 160 MHz 经 MCO 16 分频的 10
MHz，单位 ps）：

设定间隔 | 速度档 0（低） | 档 1 | 档 2（高） | 档 3（最高）

最低档最差，最高档在长间隔反而劣化，作者暂定用"高"档，原因尚未用示波器查明。对 GNSSDO
本身影响不大——在整机里 START 来自 F9T、STOP 来自 LMK，都不是 MCU 的 GPIO；但对用 MCU
产生测试信号做标定的场景是个实用提醒。

论坛里多人（WatchfulEye、thinkfat）指出，在环路关心的带宽内，ZED-F9T 定时脉冲本身的噪声比 TDC7200
高几个数量级。作者也认同，并据此放弃了功能更强但更贵的 ScioSense AS6500——用 AS6500 虽然可以省掉
MCU 定时器的粗测，但生成稳定输出脉冲仍需要一个同步到 OCXO 的 MCU 定时器，收益不大。WatchfulEye
还给了一个技巧：可以"借用"模式 2，只取时钟计数与 TIME1 的小数部分，丢掉
TIME2，避免两次测量噪声相加。

OCXO_VREF：可改用 OCXO 自身基准，做比率式调谐

元件值格式：v1（2022-08-05，约 1 Hz）/ v2（2022-08-11，约 10 Hz）。R313 与 C315 两版相同。

AD5542A 是无缓冲输出，约 6.25 k 内阻与 R311 串联，会把实际截止频率拉低约 20%，见第 5.2 节。

信号路径：ADR4533（3.3 V）或 OCXO 自身 VREF → AD5542A 16 bit DAC → 二阶 Sallen-Key
有源低通（单位增益，OPA189）→ 无源 RC（100 欧 + 10 uF）→ OCXO 的 VCTL。几个设计细节：

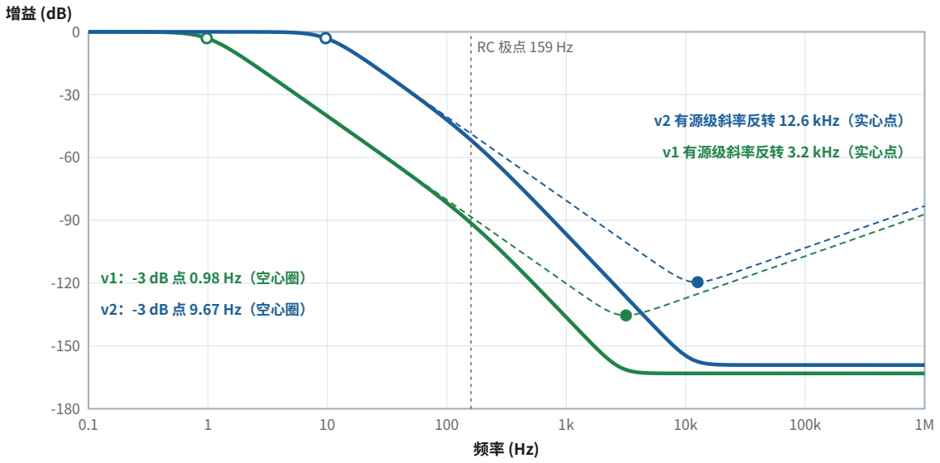
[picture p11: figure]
v1：-3 dB 点 0.98 Hz（空心圈）; v2：-3 dB 点 9.67 Hz（空心圈）

CORE 项目 · 硬件设计文档 | 第 8 页
- 基准二选一（JP302）。 用 OCXO 自带的 VREF 时，DAC 输出与 OCXO 内部基准成比例，基准漂移被抵消一部分；用 ADR4533 时噪声与温漂由独立的精密基准决定。
- AD5542A 的 LDAC 接地，数据在 CS 上升沿直接锁存，只需 SPI1 的三根线（不读回）。
- 为什么有源级后面还要一级无源 RC。 在几 kHz 以上，C313 近似短路，输入电流经 R311 直接灌到运放输出端；运放的闭环输出阻抗随频率升高，于是有源级的衰减到某个频率后不再增加，反而以 +20 dB/十倍频回升，原理图上标注为"斜率在 3 至 4 kHz 处反转"。后面那级 159 Hz 的 RC 把这段回升压平。
- R313 只取 100 欧。 作者解释：12 k 欧的电阻在 300 K 时热噪声约 14 nV/根号Hz，已高于 OPA189 的输出噪声，所以第二级用小电阻大电容"宁可保守"。
- OCXO 罩在 Hammond 1551P 塑料盒里挡气流，罩内放 TMP117 测温。

### 5.2 两版参数与本文计算

参数 | v1（2022-08-05） | v2（2022-08-11）
R311 / R312 | 13 k / 10 k | 8.2 k / 15 k
C313 / C314 | 20 uF / 10 uF | 2.2 uF / 1 uF
f0（按原理图） | 0.99 Hz | 9.68 Hz
Q | 0.70（接近巴特沃斯） | 0.71
群时延：直流 / 峰值 | 0.23 s / 0.28 s（0.62 Hz 处） | 0.024 s / 0.029 s（6.2 Hz 处）
计入 DAC 内阻 6.25 k 后的 f0 与 Q | 0.81 Hz，Q 0.67 | 7.29 Hz，Q 0.74
计入 DAC 内阻后的群时延峰值 | 0.33 s | 0.039 s
作者标注的斜率反转点 | 3 至 4 kHz | 约 10 kHz
本文模型算出的反转点 | 3.2 kHz | 12.6 kHz
| v2 有源级斜率反转 12.6 kHz（实心点） v1 有源级斜率反转 3.2 kHz（实心点）
v1 总响应（至 VCTL） | v1 仅有源级 | v2 总响应（至 VCTL） | v2 仅有源级

按原理图元件值计算；运放取 GBW 14 MHz，等效输出电阻 8 欧（使反转频率与作者 PSpice 结论一致）。未计 DAC 内阻。

图 7 两版调谐滤波器的幅频响应（按原理图元件值计算）

CORE 项目 · 硬件设计文档 | 第 9 页

一个旁证： 作者在帖子中给出 v1 的 PSpice 结果"群时延在约 0.5 Hz 处达到峰值约 0.27 s"，与本文不计 DAC 内阻时算出的 0.28 s @ 0.62 Hz 吻合，计入内阻后则是 0.33 s。可见作者仿真时把 DAC 当成了理想电压源（他也说明用的是"2 V 直流偏置 + 1 mV 交流"的激励源）。

### 5.3 为什么要更细的调谐分辨率

1 s | 10 s | 100 s | 1000 s

1 ps

10 ps

100 ps

1 ns

10 ns

100 ns

持续时间 tau

### 1 LSB 累积的时间误差

作者期望的 1 ns

| 作者算例 305 ps
| | TDC7200 单次约 50 ps
16 bit DAC：30.5 ppt / LSB | 20 bit DAC：1.91 ppt / LSB

假设 OCXO 调谐范围 2 ppm 全部落在 DAC 满量程内。斜线是 1 LSB 频率步进在 tau 内累积的时间误差。

图 8 DAC 一个 LSB 的频率步进在 tau 内累积出的时间误差

作者的算例：假设 OCXO 调谐范围 2 ppm 全部落在 16 bit DAC 的满量程内，一个 LSB 对应 30.5 ppt；持续 10 s 就累积 305 ps，已经比 TDC7200 的约 50 ps 分辨率粗了 6 倍。所以他希望在 DAC 之上再叠加 PWM 或 PAM（用 STM32G4 的定时器或 DAC 的循环 DMA）扩展有效位数——这正是 1 Hz 低通的第二个用途。

这个设计在 time-nuts 上引发了一轮讨论：

观点 | 提出者 | 要点
滤波器时延会带 来环内相移和噪 声峰化 | Bob kb8tq | 控制环不分模拟数字，时延就是时延，无法"补偿掉"
群时延对慢环路 可忽略 | 作者 | 0.27 s 的群时延对 10 s 以上的环路时间常数可忽略；1PPS 驱动的环路时间常数本来就不可能小于 1 s；数字环可把滤波器传函和死区时间显式计入
其实几乎不用滤 波 | Watch fulEye | 按窄带调频近似，VCTL 噪声引起的相噪约为 20 log10(S x Nv(f) / 2f)。以 0 至 4 V 调 +/-2 ppm 的廉价 OCXO（S = 10 Hz/V）为例，1 LSB 方波扰动在 10 Hz 偏移处约 -122 dBc/Hz，远低于廉价 OCXO 自身相噪
PWM 抖动比 DAC 更便宜 | MIS42 N | 用 PIC 的 10 bit PWM 逐脉冲抖动扩到 24 bit，FET 对管缓冲加无源滤波，粒度优于 1 uV

v2（08-11）把截止频率从 1 Hz 提到 10
Hz，群时延随之降为原来的十分之一。作者没有说明改动原因，时间上紧随上述讨论。

### 5.4 本文发现的两处需要注意的地方

以下两点作者在帖子和原理图中都没有讨论，是本文根据器件数据手册推断的，移植时应先核实：

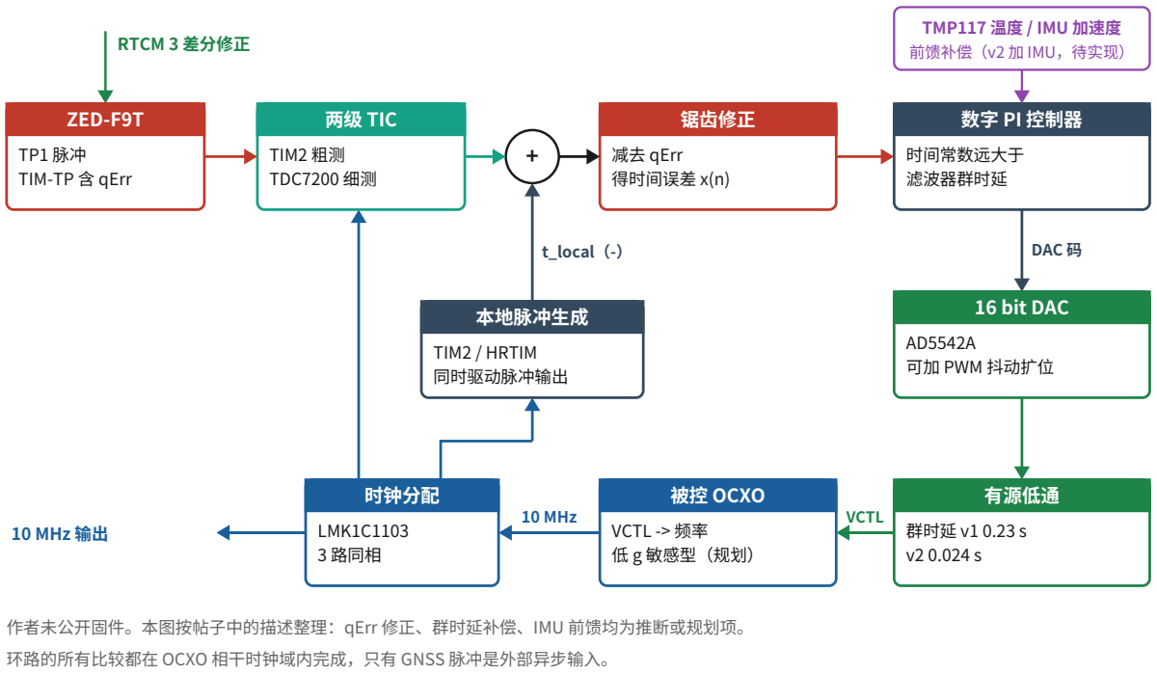
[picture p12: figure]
ZED-F9T; TP1 脉冲 TIM-TP 含 qErr; 两级 TIC; TIM2 粗测 TDC7200 细测; 锯齿修正; 减去 qErr 得时间误差 x(n); 数字 PI 控制器; 时间常数远大于 滤波器群时延; TMP117 温度 / IMU 加速度; 前馈补偿（v2 加 IMU，待实现）; 16 bit DAC; AD5542A 可加 PWM 抖动扩位; 有源低通; 群时延 v1 0.23 s v2 0.024 s; 被控 OCXO; VCTL -> 频率 低 g 敏感型（规划）; 时钟分配; LMK1C1103 3 路同相; 本地脉冲生成; TIM2 / HRTIM 同时驱动脉冲输出; DAC 码; 10 MHz; VCTL; t_local（-）; 10 MHz 输出; RTCM 3 差分修正; 作者未公开固件。本图按帖子中的描述整理：qErr 修正、群时延补偿、IMU 前馈均为推断或规划项。; 环路的所有比较都在 OCXO 相干时钟域内完成，只有 GNSS 脉冲是外部异步输入。

CORE 项目 · 硬件设计文档 | 第 10 页
1. AD5542A 的内阻会改变滤波器参数。 它是无缓冲 R-2R 输出，内阻约 6.25 k 欧，与 R311 串联。结果是 f0 比设计值低约 18% 至 25%，群时延相应变大（见 5.2 节表格）。直流精度不受影响，因为运放同相端几乎不取电流。移植时应把 R311 减去约 6.25 k 欧，或在 DAC 后加缓冲。
2. OPA189 的输入共模范围可能不够。 TI 数据手册给出的输入共模上限比正电源低约 2.5 V（典型值）。OPA189 用 +5 V 单电源时，同相端最高约 2.5 V；而 DAC 满量程是 3.3 V，码值的上部约 24% 会使单位增益跟随器超出共模范围。如果 OCXO 的实际工作点在 2.5 V 以下就不受影响——作者仿真时用的 2 V 偏置恰好在范围内，所以仿真不会暴露这个问题。本项目 v1.1 计划 HW-B 选的 OPA333、OPA192 都是输入轨到轨型，不存在此问题。

## 6. 控制环（推断）

图 9 数字锁相环的信号流（按帖子描述整理，作者未公开固件）

作者没有公开固件，下面是根据帖子能确定的部分：

环节 | 能确定的内容 | 来源
相位比 较 | GNSS 脉冲时刻与本地 OCXO 派生脉冲时刻之差，全部在 OCXO 相干时钟域内完成 | 架构本身
环路时 间常数 | 作者按"大于 10 s"考虑，并认为 1PPS 驱动下小于 1 s 不现实 | time-nuts 讨论
滤波器 时延 | 由数字环显式计入 | time-nuts 讨论
锯齿波 修正 | 用 F9T 的 UBX-TIM-TP 中的 qErr。F9T 内部时钟据社区估计约 128 MHz，量化步长约 7.8 ns | 推断；时钟频率为 Marek 的估计，未见官方确认

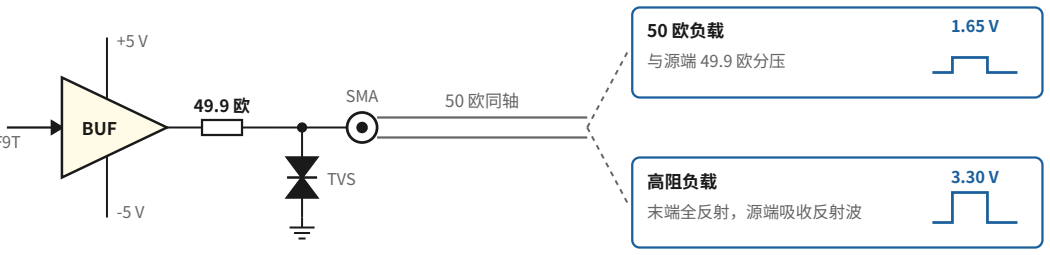
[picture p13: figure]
TVS; SMA; 50 欧同轴; 50 欧负载; 与源端 49.9 欧分压; 高阻负载; 末端全反射，源端吸收反射波

CORE 项目 · 硬件设计文档 | 第 11 页
环节 | 能确定的内容 | 来源
差分授 时 | 一台固定的 F9T 以时间模式、已测坐标运行，向移动端发送 RTCM 3 MSM7；移动端 F9T 用这些码与载波相位修正改善授时 | time-nuts 讨论
IMU 用途 | v2 加了 IMU，作者未说明用途。推断用于 OCXO 加速度敏感度补偿或运动状态记录 | 推断
温度 | TMP117 放在 OCXO 罩内，可用于温度前馈 | 推断

### 6.1 社区指出的 ZED-F9T 风险

这些风险直接影响移动场景，作者表示要靠原型实测来回答：

- 定时指标只在固定位置模式下规定。 F9T 数据手册的 5 ns 绝对、2.5 ns 差分的脉冲精度只针对固定位置模式；移动时的运行极限是 4 g、500 m/s。作者承认移动中可能劣化，验证这一点正是做原型的目的之一。
- 能否用 RTK 修正有争议。 John Ackermann（N8UR）认为只有 F9P 能内部做 RTK，F9T 只能当基准站；作者引数据手册反驳：F9T 的差分授时功能本身就使用 RTCM 10403 中的码与载波相位修正，不需要做 RTK 定位。
- 位置误差不等于时间误差。 作者用 F9P 双天线基线长度误差的统计（98% 小于 30 cm，约合 1 ns）来类比，Bob kb8tq 认为时间误差很可能比这个类比更差。目前双方都没有数据。
- 模块对温度、冲击、姿态敏感。 Thomas Abbott 实测：把裸模块翻转、升温 5 至 10 摄氏度、甚至用力敲桌子，脉冲都会跳几个 ns，10 至 20 s 后恢复。他判断是内部 TCXO 受扰后各个环路在重新收敛。这对车载是直接威胁。
- qErr 偶发回绕。 Thomas Abbott、Marek、Bob 都观察到时间脉冲偏移修正偶尔出现约 7 ns 的"跳点"，2019 年的固件与 TIM 2.21 固件上都有人遇到，固件里必须做跳变检测。
- 不要开 SBAS。 作者引用了 u-blox 的建议：授时应用应关闭 SBAS。

## 7. 输出驱动

BUF602 输出级（5 路相同）

CMOS 3.3 V
来自 LMK / MCU / F9T | BUF

J401 10 MHz

来源：LMK Y0

J411 10 MHz

来源：LMK Y0

J441 稳定脉冲

来源：MCU PA9

J451 稳定脉冲

来源：MCU PA9

J491 F9T TP2

来源：接收机直出

BUF602 压摆率 8 V/ns，上升沿 < 0.5 ns，PSRR > 45 dB（至 1 MHz），以上为作者引用的数据手册值。

+/-5 V 与 +3.3 V 全部由 J101 端子从外部供入，板上没有稳压器。

图 10 BUF602 输出级：源端 49.9 欧匹配，可驱动 50 欧或高阻负载

CORE 项目 · 硬件设计文档 | 第 12 页

5 路输出电路完全相同：BUF602 → 49.9 欧串联 → TVS → SMA。2 路 10 MHz 来自 LMK 的 Y0，2 路稳定脉冲来自 MCU 的 PA9，1 路是 F9T 的 TP2 原始脉冲。

作者为什么用缓冲运放而不用 74 逻辑门，在同期的 RCB-F9T 转接板讨论中解释得很清楚：

理由 | 说明
上升沿 | BUF602 压摆率 8 V/ns，上升沿 < 0.5 ns；逻辑门的规格书都不给 1 ns 以下的上升时间
电源抑制 | BUF602 的 PSRR 在 1 MHz 以内 > 45 dB；逻辑门基本不标
源端匹配 | 运放输出阻抗低且确定，串 49.9 欧即成 50 欧源；逻辑门不标输出阻抗，驱动 50 欧要并联多个输出
可预期的噪 声 | 附加噪声主要来自输入电压噪声 4.8 nV/根号Hz，约合 -153 dBm/Hz（50 欧），可以照数据手册算；逻辑门没有抖动指标
工程成本 | Bob kb8tq 认为分立方案更便宜；作者认为为每种信号分别验证一套方案的工程成本更高，手焊 SMA 的成本已经超过器件差价

作者还指出输出电平恰好符合 ITU G.703 的要求。在单独的 RCB-F9T 转接板上，-5 V 由 LM27761 电荷泵产生（驱动 5 路 50 欧负载的平均电流 < 100 mA）；主板上则由 J101 外供。

## 8. MCU 引脚分配

STM32G474RET6

LQFP64，170 MHz
时钟取自 OCXO
10MHZ_MCU（HSE 旁路） | PF0 · 5
PULSE_GNSS（TIM2_CH4） | PB11 · 33
UART4_TX -> F9T RXD | PC10 · 52
UART4_RX <- F9T TXD | PC11 · 53
I2C3_SCL -> TMP117 | PC8 · 40
I2C3_SDA <-> TMP117 | PC9 · 41
USB D- | PA11 · 45
USB D+ | PA12 · 46
SWDIO | PA13 · 49
SWCLK | PA14 · 50
LED 绿 / 黄 / 红 | PA0~2 · 12~14
PA9 · 43 | PULSE_MCU（TIM2_CH3）
PA4 · 18 | SPI1_NSS -> DAC
PA5 · 19 | SPI1_SCK -> DAC
PA7 · 21 | SPI1_MOSI -> DAC
PB12 · 34 | SPI2_NSS -> TDC
PB13 · 35 | SPI2_SCK -> TDC
PB14 · 36 | SPI2_MISO <- TDC
PB15 · 37 | SPI2_MOSI -> TDC
PC6 · 38 | TDC INTB（4k7 上拉）
PC7 · 39 | TDC ENABLE
PA15 · 51 | SPI3_NSS -> IMU
PB3~5 · 56~58 | SPI3 <-> IMU
PB6 · 59 | TIM4_CH1 -> IMU CLKIN

PA9 也可作
HRTIM1_CHA2
184 ps 输出

v1（08-05）差异：TDC ENABLE / INTB 在 PC8 / PC9，TMP117 走 I2C4（PC6 / PC7），无 IMU 与 LED。

图 11 STM32G474RET6 在 v2 原理图中的引脚分配

几个值得注意的选择：

- PF0 接 10 MHz（HSE 旁路），这是"MCU 与 OCXO 同源"的关键一根线。
- PA9 输出稳定脉冲。 它在原理图上标为 TIM2_CH3，但 PA9 同时是 HRTIM1_CHA2，可改用 HRTIM 获得约 184 ps 的边沿定位分辨率，这就是作者说的"约 200 ps 可调延迟"。

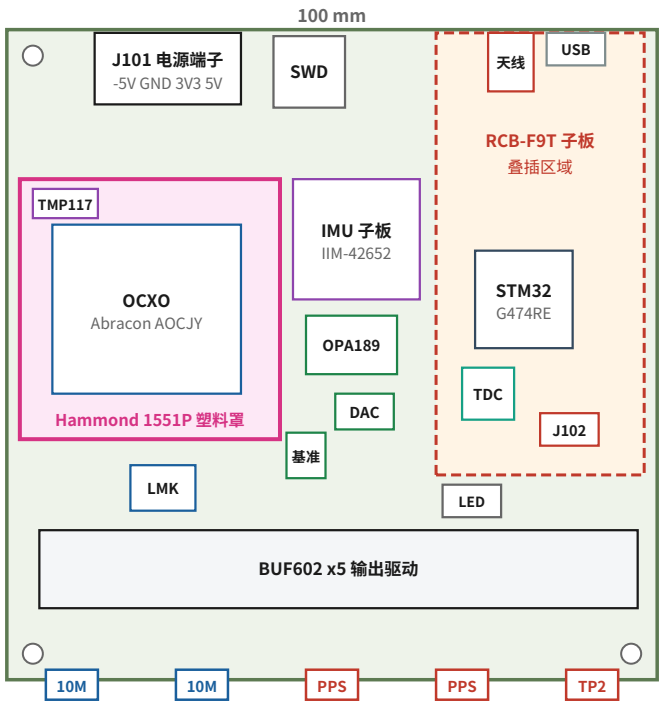
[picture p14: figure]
J101 电源端子; -5V GND 3V3 5V; SWD; Hammond 1551P 塑料罩; OCXO; Abracon AOCJY; TMP117; IMU 子板; IIM-42652; RCB-F9T 子板; 叠插区域; USB; STM32; TDC; OPA189; DAC; LMK; LED; BUF602 x5 输出驱动; PPS

CORE 项目 · 硬件设计文档 | 第 13 页
- GNSS 脉冲进 PB11（TIM2_CH4），与输出脉冲共用 32 bit 的 TIM2，粗测与生成在同一个计数器上，没有跨定时器的同步问题。
- PC13 至 PC15 一律不用。 v2 原理图特意注明：这三脚由电池域的 3 mA 电源开关供电，最高 2 MHz @ 30 pF，且不能输出电流。
- TDC 的 INTB 加了 4.7 k 上拉（v2 的 R231）。作者在 08-07 读 thinkfat 的帖子时发现 v1 漏了这个上拉——原理图注释"Only INT is open-drain"。
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

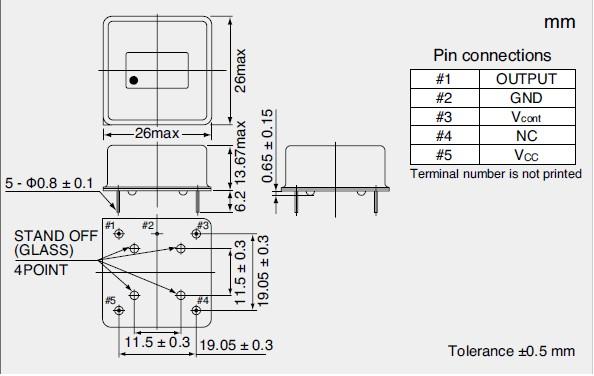
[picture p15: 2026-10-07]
docs/hardware/10Mhz OCXO ETC-CTI OSC5A2B02/CTI_datasheet1.jpg

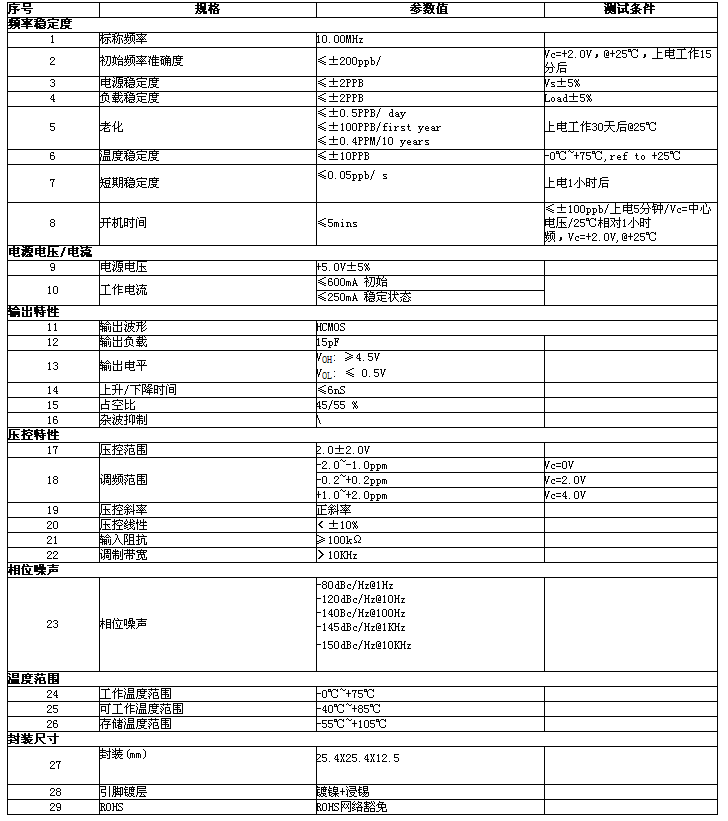
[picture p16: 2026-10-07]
docs/hardware/10Mhz OCXO ETC-CTI OSC5A2B02/ocxo_datasheet2.png

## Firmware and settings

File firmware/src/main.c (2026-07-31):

/**
 * @file main.c
 * @brief 固件入口点
 *
 * 职责:
 *   - 系统初始化 (时钟/电源/外设)
 *   - 启动各服务模块
 *   - 进入主循环或 RTOS 调度
 */

#include "hal/hal_init.h"
#include "app/app_main.h"
#include "services/service_manager.h"

int main(void)
{
    /* 1. 硬件抽象层初始化 */
    hal_init();

    /* 2. 服务层启动 */
    service_manager_init();

    /* 3. 应用层入口 */
    app_run();

    /* 不应到达此处 */
    while (1) {
        /* idle / WFI */
    }

    return 0;
}

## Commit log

2026-07-31 Initial commit: GPSDO project
    [GPSDO.kicad_pcb, GPSDO.kicad_sch]
2026-07-31 Update README and schematic history
2026-07-31 Update KiCad schematic files and history
    [GPSDO.kicad_sch]
2026-07-31 Update KiCad schematic and project files
    [GPSDO.kicad_sch]
2026-08-04 更新 GPSDO 硬件设计文件
    [GPSDO.kicad_pcb, GPSDO.kicad_sch]
2026-08-04 更新 GPSDO 硬件原理图和 PCB 文件
    [GPSDO.kicad_pcb, GPSDO.kicad_sch]
2026-08-04 移除嵌入式 Git 子模块 .history
2026-08-05 更新 GPSDO 硬件原理图和 PCB 设计文件
    [GPSDO.kicad_pcb, GPSDO.kicad_sch]
2026-08-09 更新原理图与PCB设计
    [GPSDO.kicad_pcb, GPSDO.kicad_sch]
2026-08-21 sch updaate
    [GPSDO.kicad_sch]
2026-08-30 sch update
    [GPSDO.kicad_pcb, GPSDO.kicad_sch]
2026-10-08 add pdf and sch
    [GPSDO_Rev1.0.kicad_pcb, GPSDO_Rev1.0.kicad_sch]
2026-10-13 add stm32cubemx project
2026-10-16 pcb update
2026-10-19 sch and pcb update

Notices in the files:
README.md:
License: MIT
